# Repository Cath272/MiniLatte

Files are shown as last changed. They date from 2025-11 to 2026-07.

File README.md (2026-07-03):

# MiniLatte

## Introduction
MiniLatte is a Mini Pc made using the LattePanda Mu compute module

## General description
The device is a x86 desktop comuter with lots of IO ports like USB, PCIe, Ethernet and more. 

## Problems
Esp32 and GL3224 do not enumerate sometimes
The headphone jack is not correctly wired and i did not figure out how to fix it yet

### Block diagram
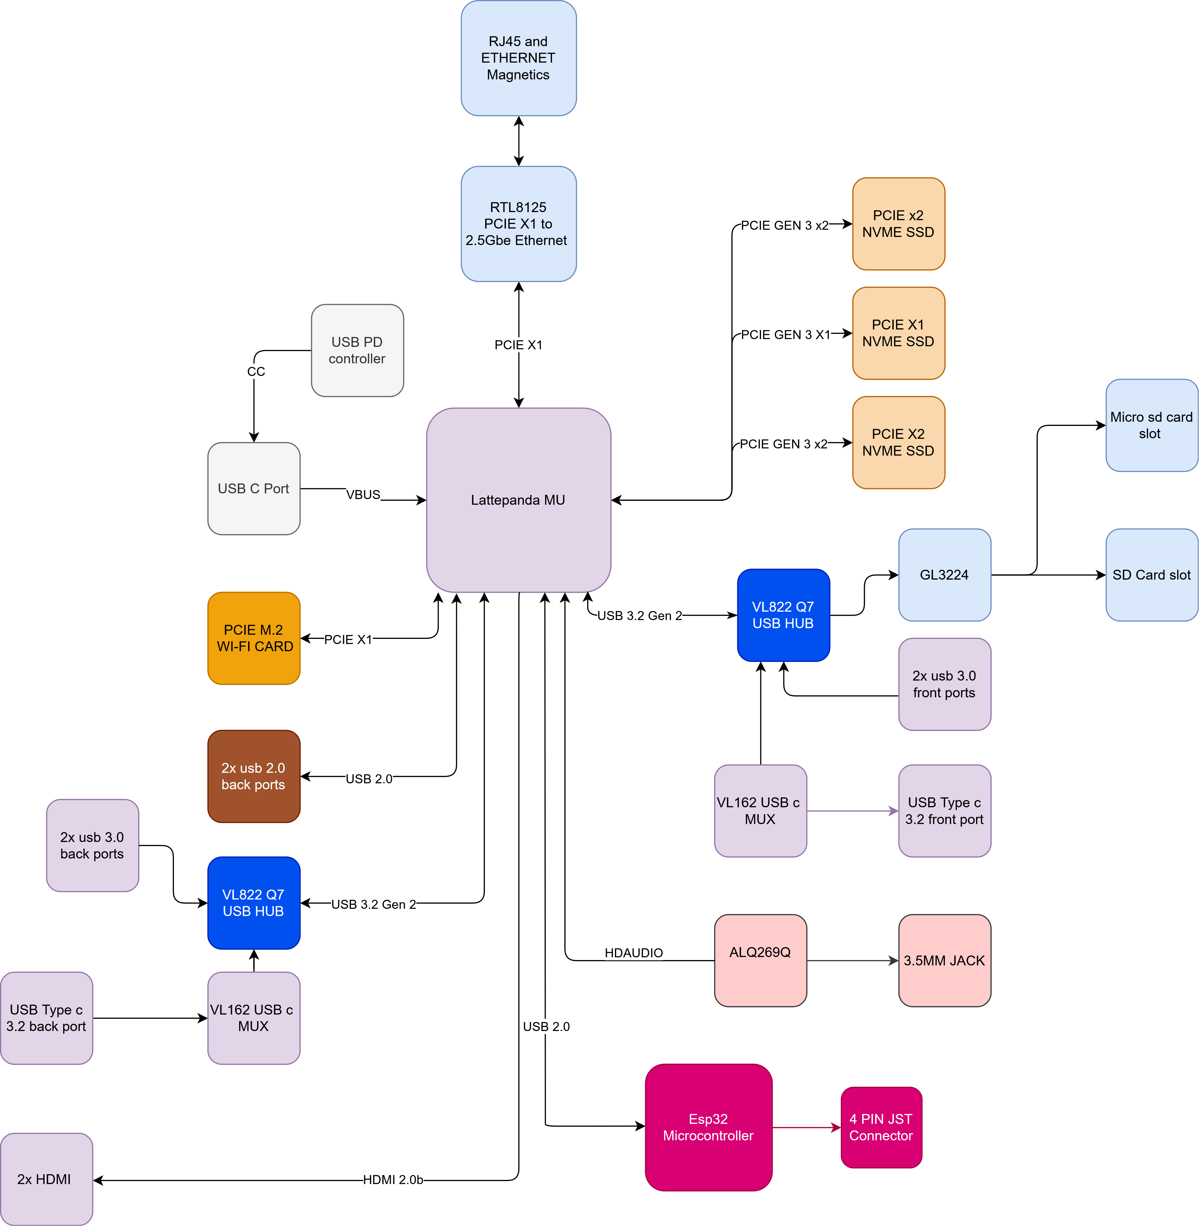
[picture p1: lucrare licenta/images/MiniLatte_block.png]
block diagram


## Hardware Design
### LattePanda Mu 
The LattePanda Mu is a compute module with rich IO with up to 9 PCIe slots, lots of usb, gpio and much more.
The module is Avaliable with 8 or 16gb of LPDDR5 ram, and an Intel N100 or Intel N305 CPU, the module uses a SODIMM DDR4 slot to connect to the carrier pcb

## ICs 
The board uses a lot of ics, so to avoid a long section about ics you can find the complete list of ICs in an the BOM generator in KiCad
All parts that are not generic (Like caps and resistors) are directly imported from LCSC so they also have an LCSC id 
Please read the warning on the IT8851-128 if you want to build the board.

Some of the chips are not available on components sourcing sites like DigiKey or LCSC but can be easliy found of Aliexpress.
Some notable Ics used by the board:

### VL822-Q7
USB 3.2 Gen 2 USB Hub 10Gbps with 4 downstream ports, used to increase the number of usb from 2 to 8

### GL3224ONY
USB 3.2 Gen 1 to dual Sd card controller, used to have 2 sd cards slots on the pcb

### IT8851FN-128
Usb Type C DP alt mode Controller, used for having a usb C port with Displayport output, the chip is a bit hard to get but you can find it on Aliexpress if you ask some BOM sellers. The chip also needs to be flashed so ask the Lattepanda team for the flashing firmware.
The chip variant needs to be "IT8851-128" EXACTLY, other variants do not work.  

### TPS51275

Main Power Ic, used for DC-DC from 20v to 3.3v and 5v

### VL162
USB Type-C 2:4 differential channels mux switch and integrated CC logic function for USB 3.1 type-C application. Needed for the type C ports to work both ways.

### RTL8125BG
PCIe to 2.5Gbps Ethernet controller

## Schematic
[Schematic](PCB/MiniLatte.pdf)

## PCB

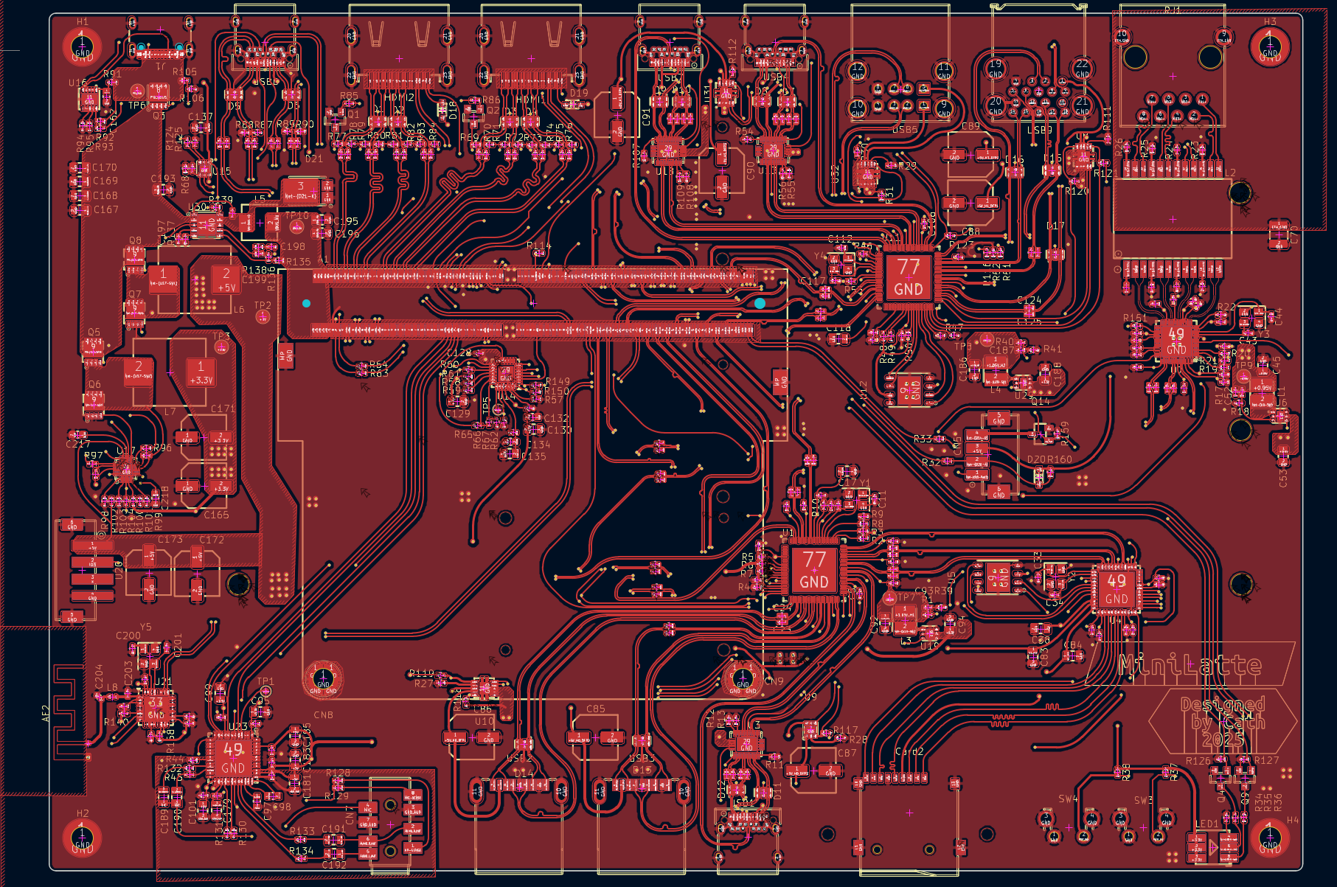
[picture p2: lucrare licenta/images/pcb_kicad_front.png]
kicad_front

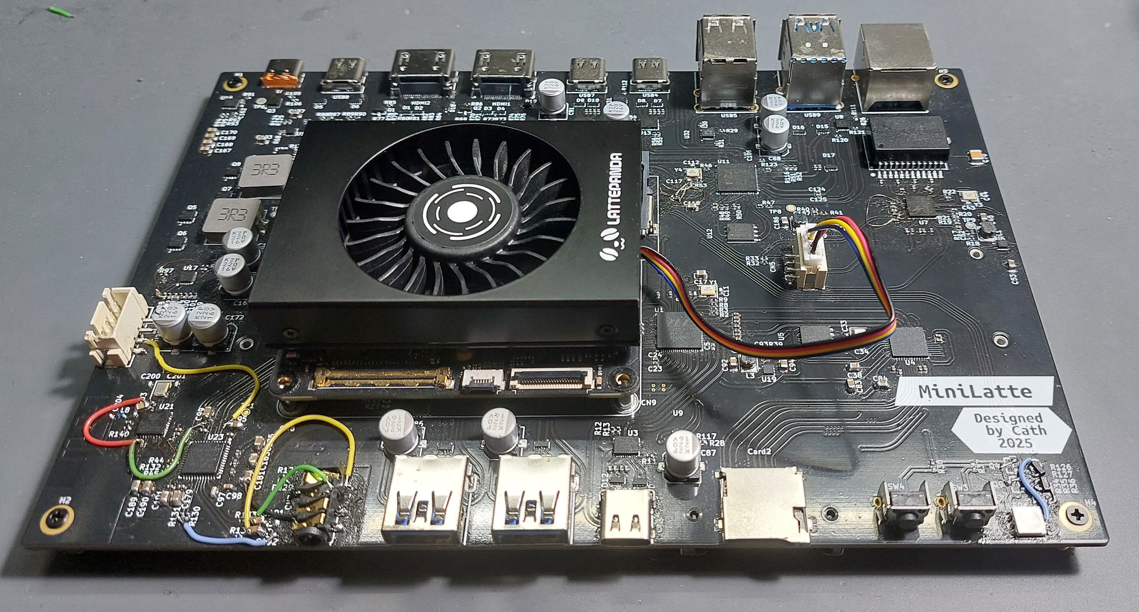
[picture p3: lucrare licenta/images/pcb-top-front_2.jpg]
pcb_front

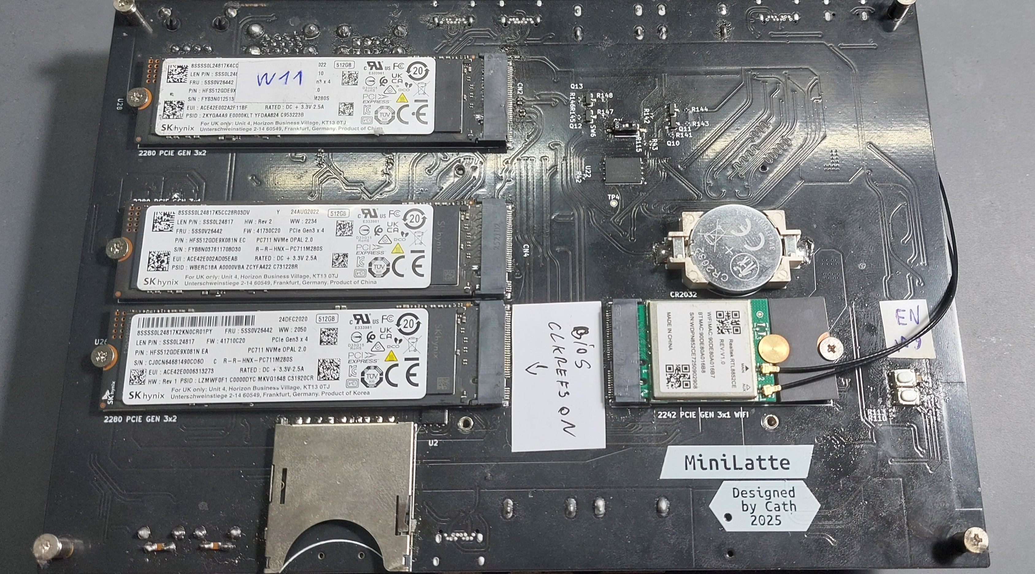
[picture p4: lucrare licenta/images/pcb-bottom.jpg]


## LED Array

The board connects to a secoundary board that an WS2812C LED Array made out of 220 leds (5x44). The Controller for the LEDs is on the main pcb and it is a ESP32 C3

## Case and 3d design

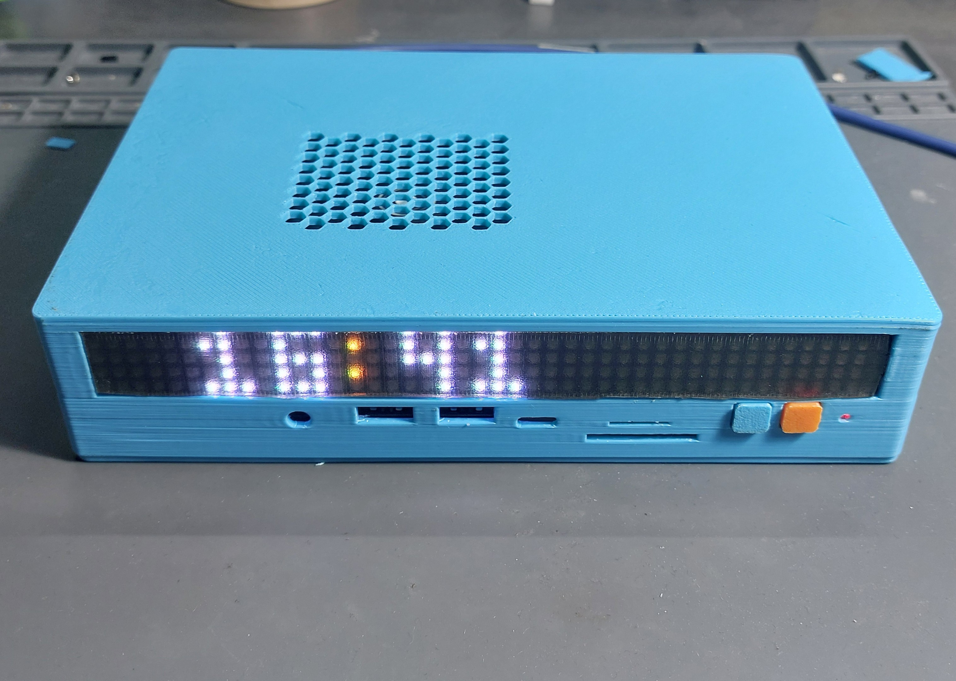
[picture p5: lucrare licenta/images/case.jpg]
case

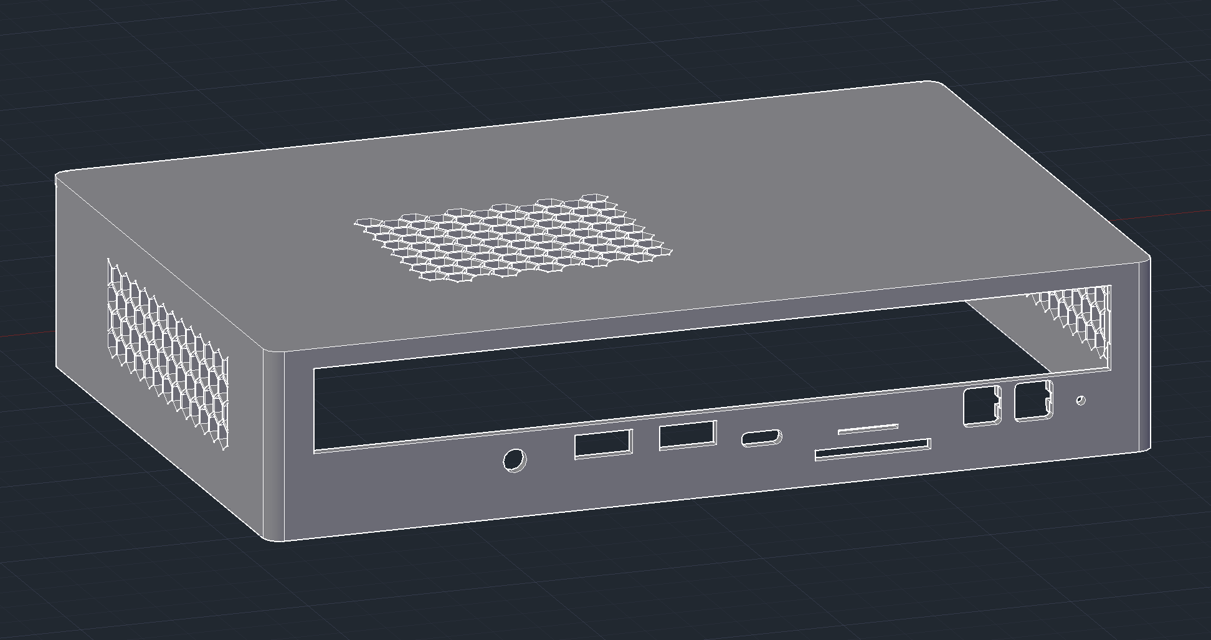
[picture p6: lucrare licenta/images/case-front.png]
case_front

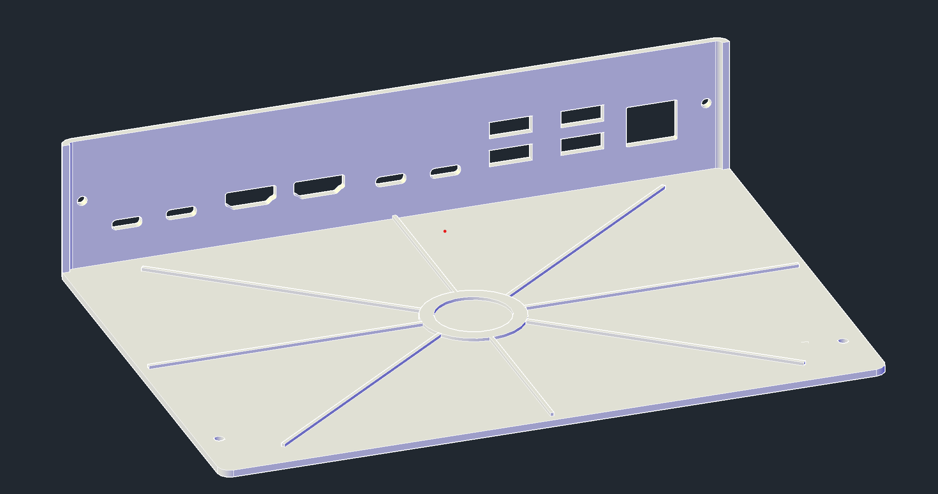
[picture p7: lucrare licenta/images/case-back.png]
case_back


The case was make using AutoCad and exported to stl
The stl files can be found in the 3D Models folder.
The case is made of 2 parts and there is a diffusion layer for the LED PCB

## Bachlors Degree
This project was made as a project for my bachlor's degree, you can find the thesis and a shorts powerpoint in the "lucrare licenta" folder but it is in romanian. It provides some details of the building process of this pcb. You can also find some extra pics in the same folder.

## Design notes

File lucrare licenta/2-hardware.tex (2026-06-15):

\chapter{Proiectarea sistemului hardware}
\label{ch:Proiectarea sistemului hardware}

\section{LattePanda Mu}

LattePanda Mu (vezi Figura \ref{fig:LattePanda-Mu}) este un modul de calcul performant, cu dimensiuni comparabile unui card bancar, proiectat de compania DFRobot. Acesta este conceput pentru integrare în produse hardware personalizate, fiind potrivit atât pentru proiecte de tip hobby, cât și pentru aplicații industriale.

Seria actuală cuprinde modele cu diferite configurații de procesoare și memorie, acestea menținând intercompatibilitatea la nivel de pinout. Modulul este proiectat pentru a fi inserat într-o \textit{carrier board} (placă de bază) folosind un slot standard SO-DIMM \ac{DDR}4. Această alegere constructivă este justificată de densitatea mare de pini, necesară pentru a expune numeroasele interfețe de comunicare către placa purtătoare.

Flexibilitatea platformei este sporită de posibilitatea modificării BIOS-ului, permițând utilizatorului să configureze alocarea liniilor de date pentru a prioritiza, după caz, numărul de sloturi \ac{PCIe} sau porturile USB disponibile. Specificațiile tehnice ale unității utilizate în prezenta lucrare sunt următoarele:

\begin{figure}
  \centering
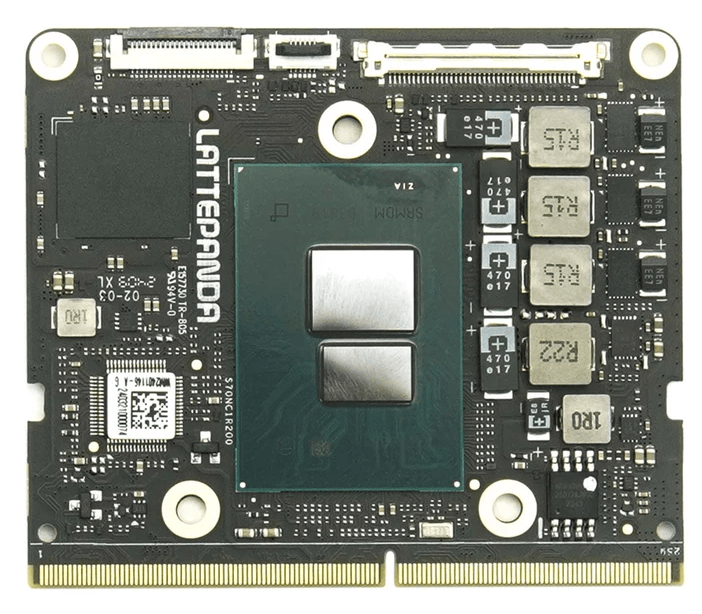
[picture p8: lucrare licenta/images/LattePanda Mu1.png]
  
  \caption[Modulul LattePanda Mu]{Modulul LattePanda Mu \cite{lattepanda_docs}.}
  \label{fig:LattePanda-Mu}
\end{figure}

În ceea ce privește conectivitatea, configurația aleasă pentru acest sistem include:
\begin{itemize}
  \item 2 porturi USB 3.2 Gen 2 (10 Gbps);
  \item 7 linii \ac{PCIe} Gen 3.
\end{itemize}

\section{Conexiuni - Diagramă Bloc}

În această secțiune sunt descrise conexiunile și este explicată diagrama bloc din Figura ~\ref{fig:diagrama-bloc}.
Sistemul utilizează standardul \textit{USB \ac{PD}}  pentru alimentare, alegere motivată datorită costului redus și a disponibilității ridicate pe piață a surselor compatibile.
Fiind un standard universal și nu unul proprietar, acesta oferă flexibilitate maximă în alegerea alimentatorului și facilitează înlocuirea rapidă a acestuia în caz de necesitate.
Toate conexiunile sunt realizate intern, la nivelul plăcii de bază, pentru a reduce latențele și a crește fiabilitatea.

\begin{figure}
  \makebox[\textwidth][c]{}
  \caption{Diagramă bloc a sistemului MiniLatte. Prezintă interconexiunile între modulul LattePanda Mu și componentele periferice.}
  \label{fig:diagrama-bloc}
\end{figure}

Pentru extinderea capacităților de conectare a perifericelor, au fost integrate două hub-uri USB care pun la dispoziție 4 porturi USB 3.2 Gen 2 fiecare, acestea sunt atât USB type A cât și USB type C. Suplimentar, la unul dintre hub-urile USB este conectat un cititor de carduri dual \ac{SD}, utilizând lățimea de bandă oferită de interfața USB 3.2 Gen 2. Amplasarea acestora fiind observată în \ref{fig:front-ports} și \ref{fig:back-ports}.

Semnalul video este distribuit prin trei porturi digitale: două \ac{HDMI} 2.0 acestea suportând rezoluții de până la 4K 60Hz, și un DisplayPort 1.4 (via USB-C) care suportă rezoluții până de la 4K 120Hz.
Pe partea de procesare audio, sistemul utilizează un cip \textit{ALC269Q} ce comunică prin protocolul \textit{\ac{HDAudio}}, acesta fiind conectat la un port de tip TRRS, permițând semnale audio stereo și microfon.

În ceea ce privește conectivitatea la rețea, sistemul oferă două posibilități distincte, ambele bazate pe magistrala \ac{PCIe} Gen 3:
\begin{enumerate}
  \item \textbf{Wireless:} prin intermediul unui modul Wi-Fi instalat în slotul dedicat de pe placa de bază;
  \item \textbf{Ethernet:} utilizând controlerul \textit{Realtek RTL8125}, care suportă viteze de transfer de până la 2.5 Gbps via \ac{PCIe} Gen 3.
\end{enumerate}

Capacitatea de stocare poate fi extinsă considerabil prin cele trei sloturi destinate unităților \ac{SSD} M.2 \ac{NVMe} poziționate pe partea inferioară a plăcii (vezi Figura \ref{fig:bottom-ports}). .

\begin{figure}
  \centering
  \begin{subfigure}[b]{1\linewidth}
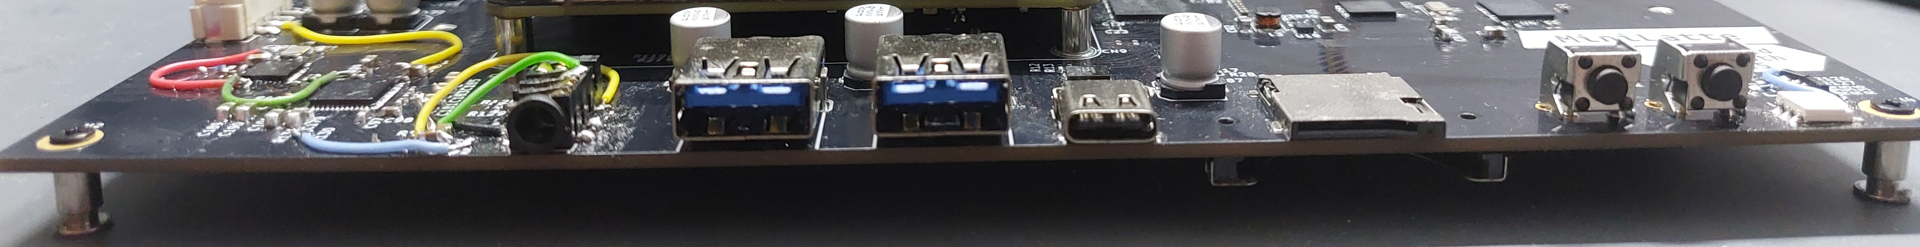
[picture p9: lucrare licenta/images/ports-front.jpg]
    
    \caption{Port-urile din partea din față a PCB-ului.}
    \label{fig:front-ports}
  \end{subfigure}
  \begin{subfigure}[b]{1\linewidth}
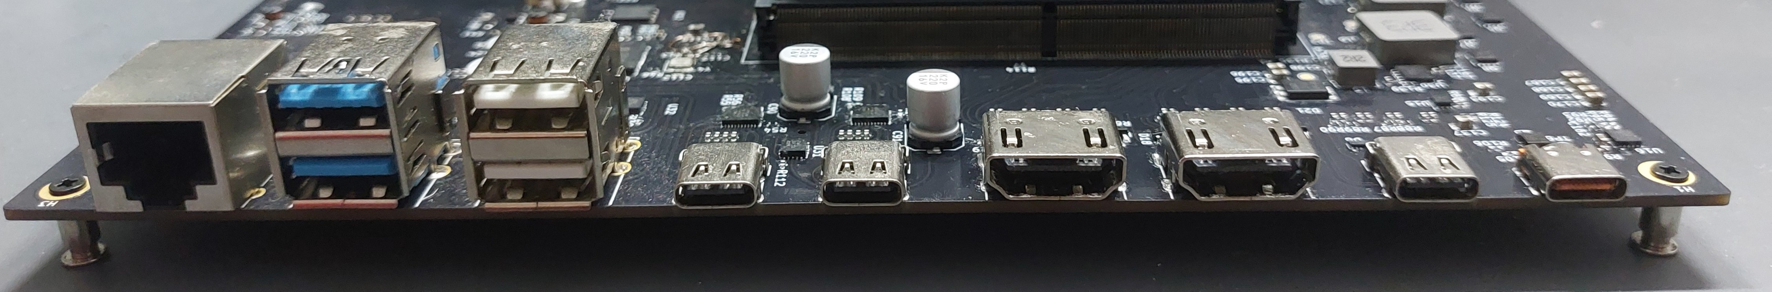
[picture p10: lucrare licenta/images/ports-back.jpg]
    
    \caption{Port-urile din partea din spate a PCB-ului.}
    \label{fig:back-ports}
  \end{subfigure}
  \begin{subfigure}[b]{0.7\linewidth}
    
    \caption{Port-urile de pe spatele PCB-ului.}
    \label{fig:bottom-ports}
  \end{subfigure}

  \caption{Port-urile PCB-ului.}
  \label{fig:ports}
\end{figure}

\section{Arhitectura hardware și selecția componentelor}

Placa de bază pentru acest modul a fost proiectată folosind KiCad 9, folosind ca bază documentația dată de creatorii modulului, dar și țindând cont de regulile de proiectare atât pe partea de diagrame electrice dar și pe partea de design de \ac{PCB}.
Pornind de la diagrama bloc,procesul de selecție a componentelor s-a bazat pe mai multe criterii, precum costul, disponibilitatea pe piață, familiaritatea cu producătorul și calitatea documentației tehnice.
\begin{itemize}
  \item \textbf{ITE IT8851FN-128:} O excepție notabilă în procesul de achiziție o reprezintă acest cip de management. Deși este un circuit integrat dificil de procurat prin canalele standard de distribuție, utilizarea sa a fost obligatorie din cauza compatibilității exclusive cu firmware-ul proprietar furnizat de LattePanda, neexistând o alternativă viabilă pe piață la momentul proiectării.
  \item \textbf{VIA Labs VL822-Q7 \cite{VL822-Q7}:} Reprezintă hub-ul USB 3.2 Gen 2 principal al sistemului. A fost selectat datorită capacității de a gestiona 4 porturi din \textit{downstream} cu o lățime de bandă de până la \mbox{10\text{\,}Gbps} per port, oferind un raport excelent între performanța de transmisie și costul de implementare.
  \item \textbf{VIA Labs VL162 \cite{VL162}:} Acest circuit integrat acționează ca un switch de date/multiplexor de mare viteză pe 4 canale, special conceput pentru configurarea porturilor USB Type-C. Rolul său critic este de a detecta orientarea fizică a conectorului USB-C inserat (prin monitorizarea pinilor CC1/CC2) și de a ruta corect liniile diferențiale de date (\textit{TX/RX}) către hub-ul principal, asigurând conexiunea indiferent de poziția în care utilizatorul conectează cablul.
  \item \textbf{Realtek RTL8125}, care oferă suport pentru viteze de până la 2.5 Gbps, menținând totodată un cost competitiv.
  \item Circuite Integrate de la Texas Instruments (TPS51275 \cite{TPS51275}, TPS54561 \cite{TPS54561}, TPS62590 \cite{TPS62590}), iar pentru protecția la supracurent au fost alese cipurile TPS2553 și TPS2561. Alegerea acestor componente s-a bazat pe eficiența ridicată, documentația detaliată și disponibilitatea acestora.
  \item \textbf{Memoriile NOR W25Q128JV} (folosit pentru stocarea BIOS-ului) respectiv W25Q32JV (folosite pentru stocarea firmware-ului pentru VL822 și GL3224), acesta au fost alese datorită costului redus.
  \item \textbf{Genesis Logic GL3224-ONY:} - controller pentru carduri SD și MicroSD, acesta a fost ales din cauza costului redus și a pentru suportul interfețelor de tip UHS-I care permit viteze până la 104MB/s.
  \item \textbf{Hynetek HUSB238} -  USB Type-C PD controller, acesta a fost ales din cauza costului redus și a modului foarte ușor de a programa tensiunile pe care le cere încărcătorului folosind doar doi rezistori, unul pentru curentul maxim și unul pentru tensiune.
  \item \textbf{Espressif Systems ESP32-C3FN4:} - Microcontroller cu WiFi și 4Mb de memorie internă, a fost ales datorită prețului, memoriei interne, circuitului intern USB-UART dar și a performanței. Microcontrollerul a fost ales în locul locul pinilor GPIO nativi ai modulului LattePanda Mu din cauza faptului că aceștia nu erau funcționali la momentul proiectării sistemului, dar și pentru a degreva procesorul de sarcina de a controla LED-urile.
\end{itemize}

\section{Diagrama electrică}

Diagrama electrică reprezintă etapa inițială esențială în procesul de proiectare. în cazul sistemului MiniLatte, aceasta este structurată pe 19 pagini și descrie în detaliu toate conexiunile dintre modulul LattePanda Mu, circuite integrate și conectori utilizați. Schema a fost organizată pe blocuri funcționale, precum „USB3”, „HDMI” și „PCIe\_SSD”, pentru a facilita înțelegerea și verificarea conexiunilor.

Pentru realizarea acesteia au fost utilizate în principal fișele de date ale componentelor, specificațiile protocoalelor de comunicație, precum și documentația oficială DFRobot  \cite{lattepanda_docs} \cite{lattepanda_github}. Aceasta din urmă a oferit informații esențiale despre modul de interconectare al modulului LattePanda Mu, servind drept referință pentru integrarea componentelor externe.

\section{Rutare trasee și Integritatea Semnalului}
Etapa de rutare a traseelor pe \ac{PCB} a avut un rol critic în asigurarea funcționării corecte a sistemului, în special datorită prezenței interfețelor de mare viteză, precum USB 3.2 Gen 2, \ac{PCIe} Gen 3 și HDMI 2.0. Pentru a preveni degradarea semnalului din cauza reflexiilor și a fenomenului de \textit{crosstalk} (diafonie), placa a fost realizată pe 4 straturi, asigurând o structură de tip \textit{stripline} (traseu rutat pe stratul exterior) și \textit{microstrip} (traseu rutat pe stratul interior) cu impedanță controlată.

%În această configurație, traseele de semnal sunt rutate pe cele două straturi exterioare, în timp ce cele două straturi interioare sunt utilizate ca planuri continue de masă. Această arhitectură permite asigurarea unui traseu de retur (return path) continuu și de impedanță redusă pentru curentul de semnal, conform bunelor practici de proiectare recomandate în ghidurile de layout pentru circuite de mare viteză \cite{Layout_Guidelines}. Menținerea unui plan de referință neîntrerupt contribuie la reducerea interferențelor electromagnetice și la îmbunătățirea integrității semnalului.

Impedanța caracteristică a liniilor de transmisie depinde direct de geometria traseelor și de proprietățile dielectrice ale materialului suport (FR4, cu o permisivitate dielectrică relativă $\varepsilon_r \approx 4.2$). Pentru protocoalele utilizate, s-au calculat și implementat următoarele valori țintă ale impedanței diferențiale ($Z_{diff}$):
\begin{itemize}
  \item \textbf{Interfețele USB 3.2 și PCIe Gen 3:} $Z_{diff} = 90\,\Omega \pm 10\%$
  \item \textbf{Interfața HDMI 2.0:} $Z_{diff} = 100\,\Omega \pm 10\%$
  \item \textbf{Liniilor de semnal de tip \textit{single-ended} (asimetrice):} $Z_{0} = 50\,\Omega \pm 10\%$
\end{itemize}

Determinarea lățimii traseelor ($w$) și a distanței de separare în cadrul perechii ($s$) s-a realizat utilizând calculatorul de impedanță integrat în suita KiCad 9, corelat cu structura geometrică a substratului (vezi Figura \ref{fig:stackup}).

Un aspect fundamental în layout-ul circuitelor de înaltă frecvență îl reprezintă asigurarea unui \textit{return path} (traseu de retur) continuu și de impedanță minimă pentru curentul de înaltă frecvență. Curentul de retur tinde să urmeze calea de sub traseul de semnal, în cel mai apropiat plan de referință solid (GND). În cadrul proiectului, straturile interioare (In1.GND și In2.GND) acționează ca planuri de masă continue.

\begin{figure}
  \centering
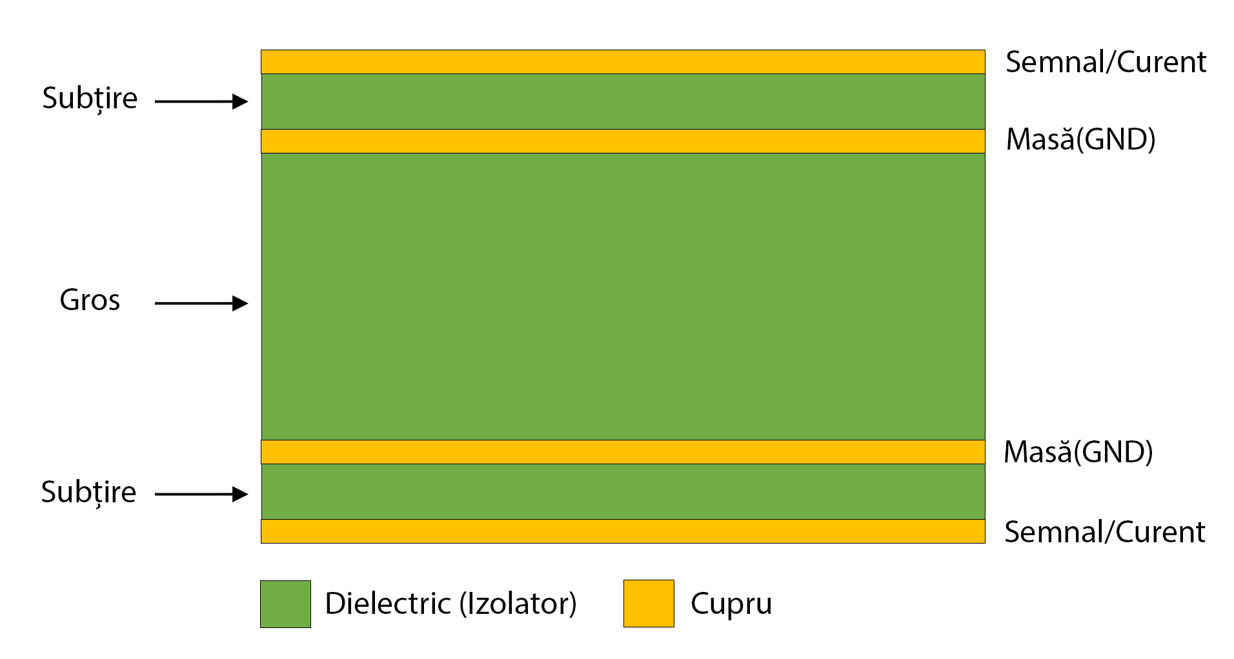
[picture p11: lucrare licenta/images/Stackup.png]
  
  \caption{Poziționarea straturilor PCBului.}
  \label{fig:stackup}
\end{figure}

\subsection{Poziționarea componentelor}
Prima etapă a rutării este plasarea preliminară a componentelor. În acest caz, s-a pornit de la poziționarea slotului pentru modulul LattePanda Mu și a conectorilor externi, în funcție de distribuția pinilor modulului (vezi Figura \ref{fig:pcb_zones}). Având în vedere că primii pini sunt dedicați alimentării, s-a ales poziționarea circuitelor de alimentare în proximitatea conectorului de intrare, definind astfel zona stângă a plăcii ca zonă principală de alimentare. Următoarele semnale sunt cele video, începând cu portul USB-C (care transmite semnal DisplayPort), urmat de cele două porturi HDMI. Ulterior, au fost poziționate porturile USB, conectate la pinii din extremitatea dreaptă a modulului, necesitând spațiu suplimentar pentru integrarea hub-ului USB. În final, a fost amplasat portul Ethernet. Dimensiunile plăcii au fost determinate de amplasarea conectorilor: lățimea este de 190 mm, stabilită de porturile din partea posterioară, iar lungimea de 130 mm, determinată de porturile din partea frontală.

\begin{figure}
  \centering
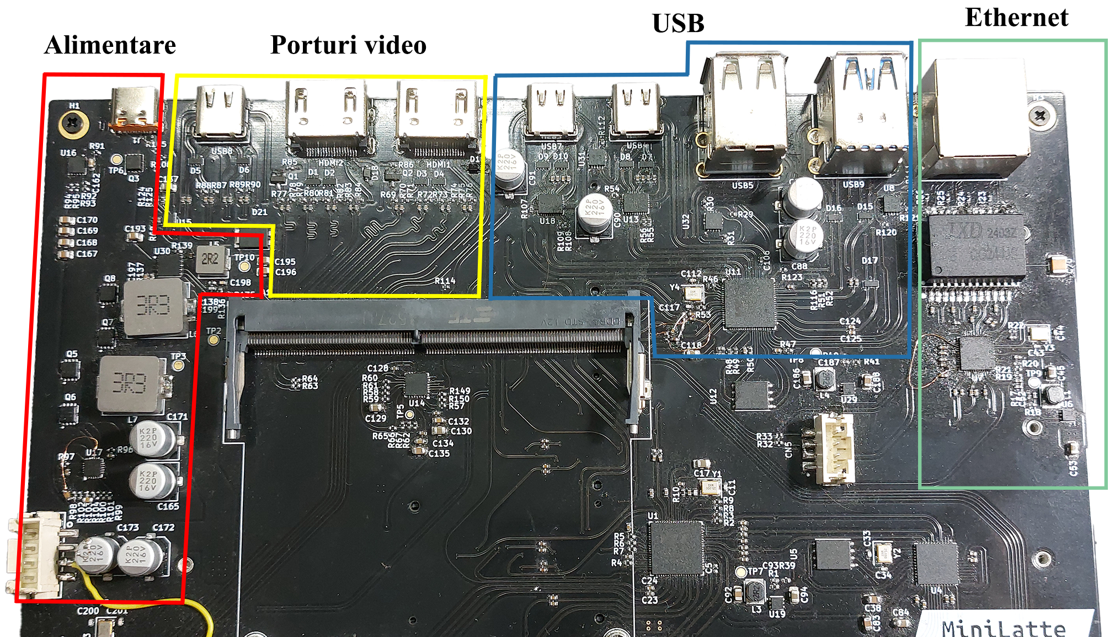
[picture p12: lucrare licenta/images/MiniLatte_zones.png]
  
  \caption{Poziționarea componentelor pe placă.}
  \label{fig:pcb_zones}
\end{figure}

\subsection{Perechi diferențiale}
Transmisia diferențiale reprezintă principala metodă de transmitere a datelor la viteze ridicate, fiind folosite în majoritatea protocoalelor de comunicare moderne cum ar fi HDMI, USB și \ac{PCIe}
În proiectarea \ac{PCB}-urilor, perechile diferențiale reprezintă două trasee paralele, cu lungimi egale și cu o distanță controlată între ele.
Diferența de lungime dintre cele două trasee, definită ca \textit{Intra Pair Skew} (decalaj în cadrul aceleiași perechi) vezi Figura~\ref{fig:Intra-Pair Skew}, trebuie să se încadreze într-o toleranță strictă, de exemplu, 0,125 mm pentru USB 3.0 \cite{Layout_Guidelines}.
În cazul protocoalelor care utilizează mai multe perechi diferențiale în paralel (precum HDMI sau DisplayPort), este necesară și gestionarea fenomenului de \textit{Inter-Pair Skew} (decalaj între perechi diferite), fiind impusă o toleranță strictă de maximum \mbox{1\text{\,}mm} pentru a asigura sincronizarea corectă a fluxurilor de date la frecvențe ridicate. Corecțiile geometrice au fost implementate prin adăugarea de serpentine pentru compensarea lungimii pe stratul exterior (vezi Figura \ref{fig:Inter-Pair Skew}).

\begin{figure}
  \centering
  \makebox[\textwidth][c]{
    \begin{subfigure}[b]{0.31\linewidth}
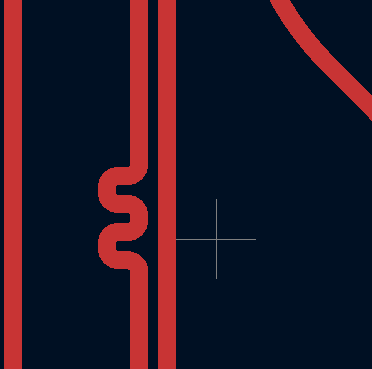
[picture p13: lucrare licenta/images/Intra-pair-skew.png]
      
      \caption{Corecție a Intra Pair Skew pe o pereche diferețială.}
      \label{fig:Intra-Pair Skew}
    \end{subfigure}
    \begin{subfigure}[b]{0.66\linewidth}
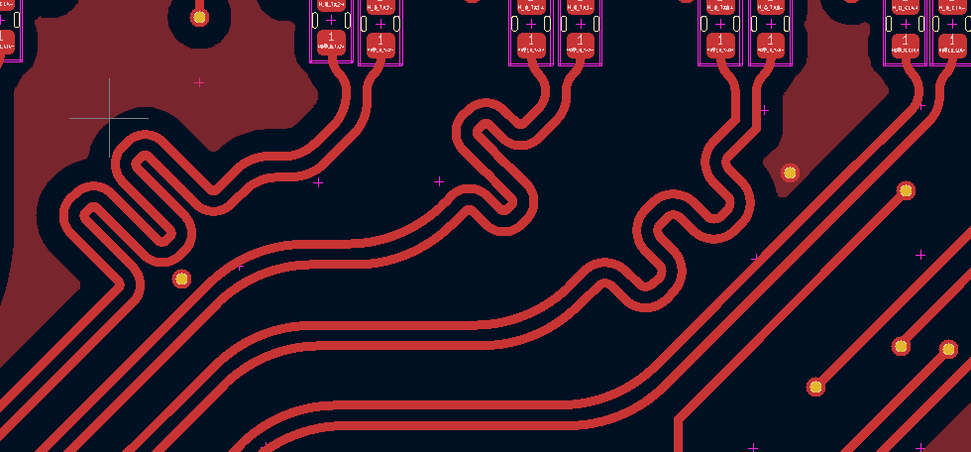
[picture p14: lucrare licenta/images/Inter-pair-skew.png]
      
      \caption{Corecție a Inter Pair Skew pe cele 4 perechi diferețiale ale unui port HDMI.}
      \label{fig:Inter-Pair Skew}
    \end{subfigure}
  }

  \caption{Corecții ale Intra si Inter Pair Skew.}
  \label{fig:Skew}

\end{figure}

\section{Proiectarea rețelei de alimentare și a protecțiilor}
Datorită numărului mare de interfețe disponibile, un lucru important in acest design a fost proiectarea in jurul consumului de curent, atât a modulului LattePanda Mu dar și componentelor de pe placa și a diverselor dispozitive conectate.

Modulul este alimentat printr-un port USB Type C utilizând protocolul USB \ac{PD} versiunea 3.0, controlat de un cip HUSB238, responsabil de negocierea tensiunii cu sursa de alimentare, solicitând un profil de \mbox{20\text{\,}V} și \mbox{3,25\text{\,}A} (\mbox{65\text{\,}W}) \cite{usb_pd_spec}, valoare standard pentru acest protocol.

Tensiunea este coborâtă la \mbox{17,5\text{\,}V} pentru modulul LattePanda Mu folosind regulatorul TPS54561. Consumul modulului fiind de \mbox{10-15\text{\,}W} în modul standard și până la \mbox{15\text{\,}W} în modul Boost, de asemenea sunt generate tensiuni auxiliare de \mbox{3,3\text{\,}V} și \mbox{5\text{\,}V} folosind cipul TPS51275.

Puterea necesară la intrare ($P_{in}$) a fost dimensionată prin calcularea consumului total al sistemului (Tabelul \ref{Tab:consumption_pwr}). Luând în considerare o eficiență conservatoare de $\eta$ = 90\% a regulatorelor DC-DC, puterea totală necesară la intrare a fost estimată matematic prin ecuația:
\begin{equation}
    P_{\text{in}} = \frac{P_{\text{total\_consumatori}}}{\eta} = \frac{48,6\,\text{W}}{0,90} \approx 54\,\text{W}
\end{equation}

Profilul de $65\,\text{W}$ a fost ales deorece este primul profil disponibil deasupra puterii calculate de $54\,\text{W}$, acest lucru oferind o marjă de siguranță critică pentru a absorbi eventualele vârfuri tranzitorii de curent.

\begin{table}[h]
  \centering
  \rowcolors{2}{white}{lightgray!20}
  \begin{tabularx}{\textwidth}{X c c c}
    \toprule
    \rowcolor{gray!30}
    \textbf{Consumator}   & \textbf{Nr. Unități} & \textbf{Consum Maxim / Unitate} & \textbf{Consum Total} \\ \midrule
    LattePanda Mu         & 1                    & 15\text{\,}W                    & 15\text{\,}W          \\
    USB 2.0 Periferice    & 2                    & 0,5\text{\,}W                   & 1\text{\,}W           \\
    USB 3.2 Periferice    & 6                    & 0,9\text{\,}W                   & 5,4\text{\,}W         \\
    Realtek RTL8125       & 1                    & 1\text{\,}W                     & 1\text{\,}W           \\
    Genesis Logic GL3224  & 1                    & 0,5\text{\,}W                   & 0,5\text{\,}W         \\
    ESP32-C3              & 1                    & 1,1\text{\,}W                   & 1,1\text{\,}W         \\
    LED-uri WS2812C       & 220                  & 0,068\text{\,}W                 & 15\text{\,}W          \\
    SSD-uri NVMe          & 3                    & 1,83\text{\,}W                  & 5,5\text{\,}W         \\
    Modul Wi-Fi           & 1                    & 2,5\text{\,}W                   & 2,5\text{\,}W         \\
    VIA Labs VL822-Q7     & 2                    & 0,8\text{\,}W                   & 1,6\text{\,}W         \\ \midrule
    \textbf{Consum total} & \multicolumn{2}{c}{} & \textbf{48,6\text{\,}W}                                 \\ \bottomrule
  \end{tabularx}
  \caption{Bugetul estimat pentru consumul de putere al sistemului.}
  \label{Tab:consumption_pwr}
\end{table}

\begin{figure}
  \centering
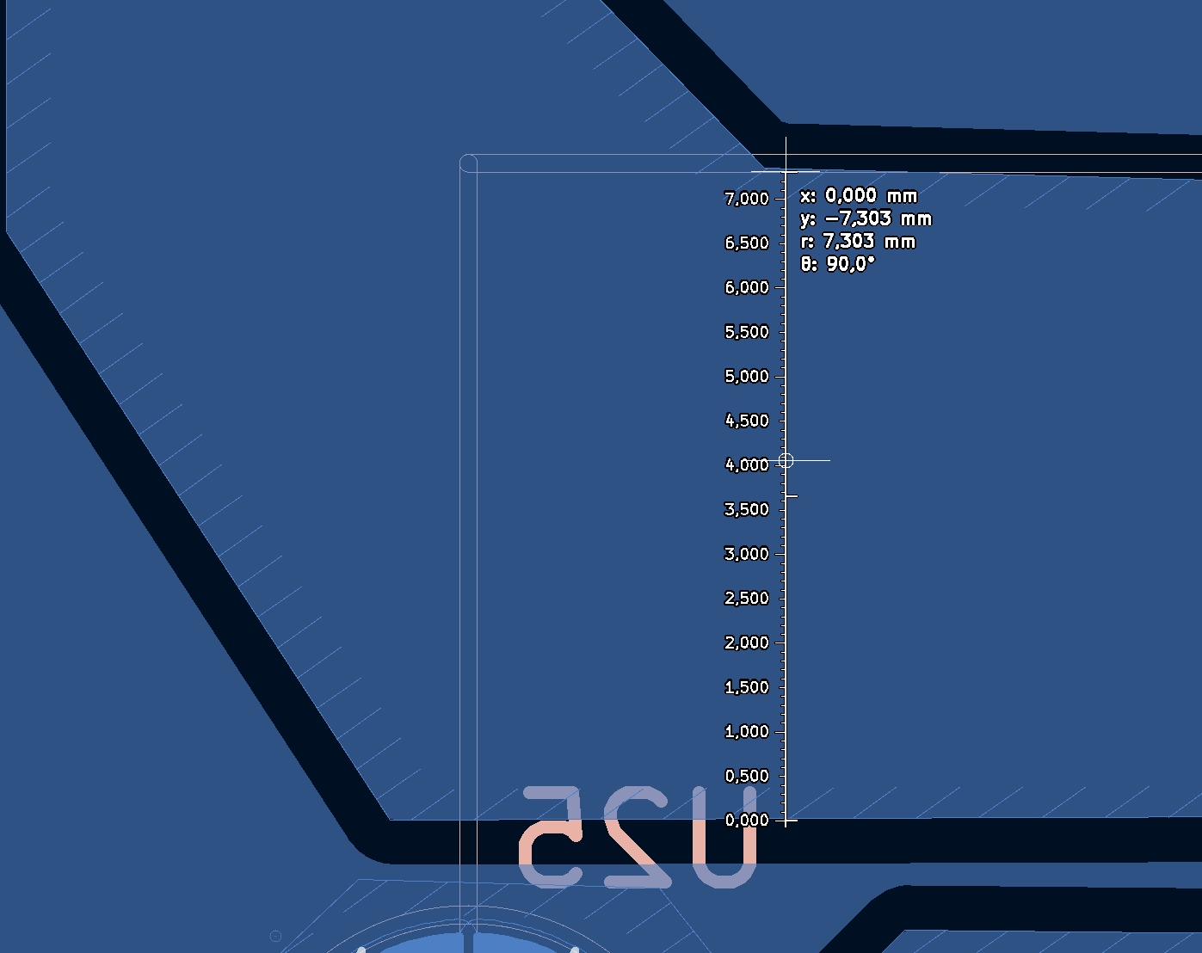
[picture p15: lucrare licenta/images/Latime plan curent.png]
  
  \caption{Plan de curent cu o lățime de 7,3mm.}
  \label{fig:power-plane}
\end{figure}

Traseele de alimentare au fost dimensionate corespunzător curenților implicați. Conform standardului IPC-2152 \cite{IPC-2152}, lățimea planului principal de alimentare de după regulatorul de $3,3\,\text{V}$ a fost dimensionată la $7.3\,\text{mm}$ (vezi Figura \ref{fig:power-plane}), urmând ca acestea să se reducă progresiv după alimentarea consumatorilor principali. Acest calcul garantează că, la un curent maxim de $10\,\text{A}$, creșterea de temperatură locală a cuprului ($\Delta T$) nu depășește $10^\circ\text{C}$ față de mediul ambiant.

Pe liniile de $3,3\,\text{V}$ și $5\,\text{V}$, unde curentul este distribuit către mai multe periferice expuse extern (porturile USB), s-a implementat o arhitectură de protecție activă. S-au integrat circuitele TPS2553 și TPS2561 de la Texas Instruments, care acționează ca limitatoare de curent reglabile și comutatoare inteligente. Acestea monitorizează în timp real curentul absorbit de porturile USB, limitându-l la $0,5\,\text{A}$ pentru USB 2.0 și respectiv $0,9\,\text{A}$ pentru USB 3.2. În cazul unui scurtcircuit extern, cipul decuplează linia defectă într-un timp de răspuns de ordinul microsecundelor, protejând sursa principală și prevenind resetarea accidentală a întregului sistem Mini PC.

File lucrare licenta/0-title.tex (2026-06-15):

\begin{titlepage}

% Redu marginile
\newgeometry{left=2cm,right=2cm,bottom=1cm}

\begin{figure}[!htb]
    \centering
    \begin{minipage}{0.2\textwidth}
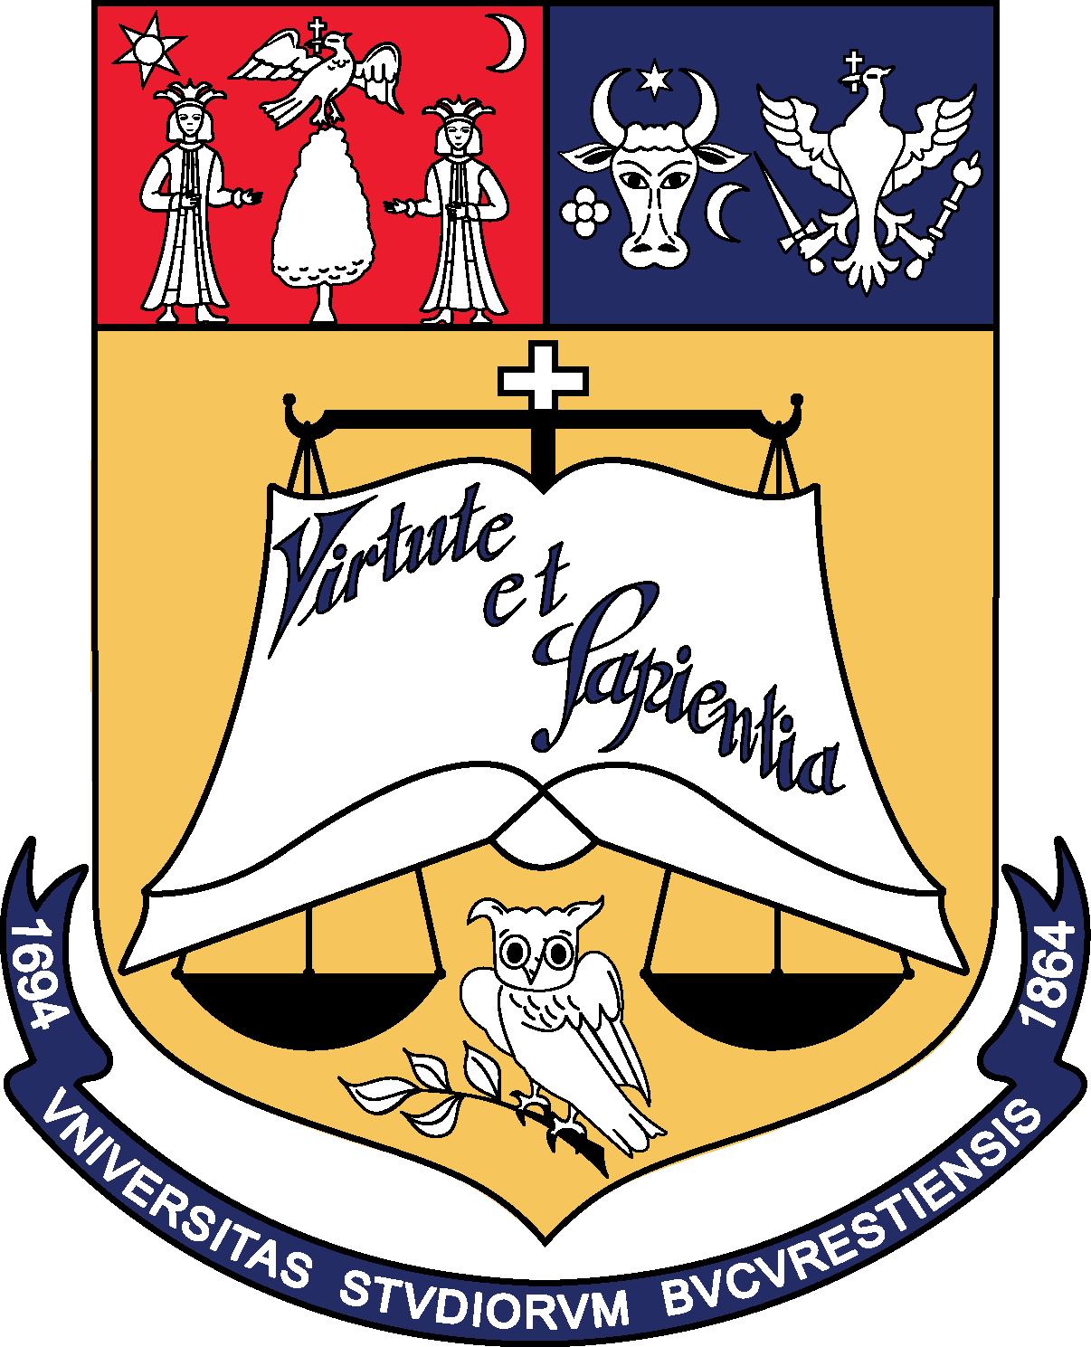
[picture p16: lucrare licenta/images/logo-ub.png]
        
    \end{minipage}
    \begin{minipage}{0.5\textwidth}
        \large
        \vspace{0.2cm}
        \begin{center}
            \textbf{UNIVERSITATEA DIN BUCUREȘTI}
        \end{center}
        \vspace{0.3cm}
        \begin{center}
            \textbf{
                FACULTATEA DE \\
                MATEMATICĂ ȘI INFORMATICĂ
            }
        \end{center}
    \end{minipage}
    \begin{minipage}{0.2\textwidth}
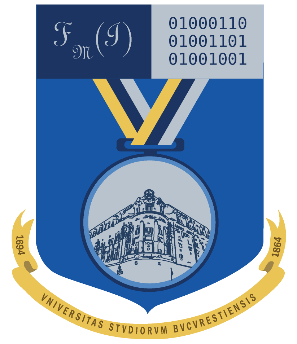
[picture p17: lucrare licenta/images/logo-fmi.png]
        
    \end{minipage}
\end{figure}

\begin{center}
\textbf{SPECIALIZAREA TEHNOLOGIA INFORMAȚIEI}
\end{center}

\vspace{1cm}

\begin{center}
\Large \textbf{Proiect de Diplomă}
\end{center}

\begin{center}
\huge \textbf{\MakeUppercase{\@title}}
\end{center}

\vspace{3cm}

\begin{center}
\large \textbf{Absolvent \\ \@author}
\end{center}

\vspace{0.25cm}

\begin{center}
\large \textbf{Coordonator științific \\ Conf. Dr. Alexe Bogdan \\ Drd. Dumitriu Andrei}
\end{center}

\vspace{2cm}

\begin{center}
\Large \textbf{București, iunie 2026}
\end{center}
\end{titlepage}

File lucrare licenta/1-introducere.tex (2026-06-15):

\chapter{Introducere}
\label{ch:introducere}

În acest capitol se prezintă contextul proiectului, obiectivele urmărite și motivația alegerii platformei hardware. Lucrarea vizează dezvoltarea unui sistem compact și performant, capabil să ruleze aplicații complexe într-un format redus, utilizând arhitectura x86 modernă pentru a asigura compatibilitatea cu o gamă largă de soluții software.

Proiectul propune dezvoltarea unui sistem Mini PC bazat pe modulul LattePanda Mu (vezi Figura \ref{fig:forma-finala}), integrat pe o placă de bază, care include interfețe de mare viteza (USB 3.2, HDMI), stocare NVMe și conectivitate WiFi și Ethernet.

Proiectul prevede proiectarea unei plăci de bază (vezi Figura \ref{fig:pcb-front-kicad}) care se integreze modulul, să îl conecteze la interfețele exterioare, direct sau prin anumite cip-uri, și să gestioneze tensiunile și curenții necesari functionării în parametrii optimi.

Acest sistem se adresează atât pasionațiilor de electronica care pot dezvolta pe baza proiectului conceput dar și a tuturor persoanelor care iși doresc un sistem compact cu posibilitea de a schimba modulul cu unul mai performant pe viitor.

\section{Obiectivele proiectului și contribuția personală}

\begin{figure}
    \centering
    \makebox[\textwidth][c]{
        \begin{subfigure}[b]{0.5\linewidth}
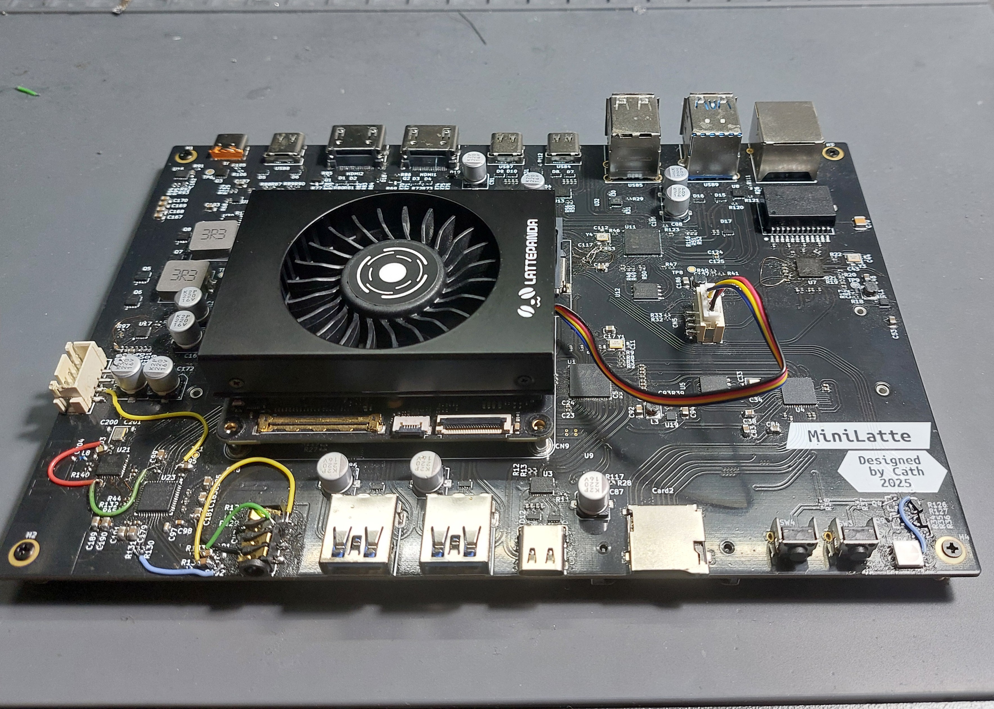
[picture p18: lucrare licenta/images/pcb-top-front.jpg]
            
            \caption{PCB-ul asamblat.}
            \label{fig:case_final}
        \end{subfigure}
        \begin{subfigure}[b]{0.5\linewidth}
            
            \caption{Sistemul asambalat în carcasă.}
            \label{fig:pcb_final}
        \end{subfigure}
    }

    \caption{Formă finală.}
    \label{fig:forma-finala}

\end{figure}

Contribuția originală a acestei lucrări constă în proiectarea integrală, realizarea fizică și validarea experimentală a unei plăci de bază complexe de la stadiul de schemă electrică de principiu până la prototipul funcțional. Obiectivele tehnice specifice îndeplinite pe parcursul proiectului au fost:

\begin{itemize}
    \item \textbf{Proiectarea schemei electrice:} Integrarea modulului x86 cu diverse circuite integrate auxiliare (hub-uri USB 3.2, controlere Ethernet 2.5 Gbps și circuite de management al curentului).
    \item \textbf{Dezvoltarea layout-ului PCB complex:} Rutarea unui circuit imprimat cu 4 straturi, cu respectarea constrângerilor stricte de integritate a semnalului (\textit{Signal Integrity}) și control al impedanței diferențiale pentru linii de mare viteză (USB 3.2 Gen 2, PCIe Gen 3 și HDMI 2.0).
    \item \textbf{Managementul alimentării și protecției:} Dimensionarea geometrică a planurilor de cupru pentru curenți mari (până la 10 A) conform standardului IPC-2152 și implementarea de protecții active la supracurent pentru porturile periferice.
    \item \textbf{Dezvoltarea carcasei și asamblarea prototipului:} Proiectarea asistată de calculator (folosind AutoCAD) a unei carcase dedicate optimizate pentru printare 3D și asamblarea fizică a componentelor SMD.
\end{itemize}

Acest sistem se adresează atât pasionaților de electronică, oferind o platformă hardware deschisă și modulară, cât și aplicațiilor comerciale care necesită densitate mare de calcul într-un volum redus, cu avantajul major de a permite upgrade-ul ulterior al modulului de procesare fără modificarea plăcii de bază.

\section{Structura lucrării} Lucrarea este structurată în patru capitole principale, începând cu „Introducerea”, care oferă
o prezentare generală a temei, a motivației și a obiectivelor proiectului.

\textit{Capitolul II} intitulat "Design", descrie proiectarea sistemului, detaliind selecția componentelor, procesul de proiectare a \ac{PCB}-ului, pozitionarea porturilor externe și diversele reguli și bune practici ce au fost luate în vedere în faza de proiectare.

\textit{Capitolul III} intitulat "Asamblare" este dedicat asamblării sistemului, detaliind matricea led integrată în sistem, proiectarea carcasei în care vor fi montate cele 2 plăci, asamblarea plăcii de bază, testarea și depanarea erorilor apărute.

Lucrarea se încheie cu o secțiune de concluzii, care evidențiază direcția de dezvoltare a proiectului, inclusiv luând în cosiderare modalitățiile prin care acesta poate fi pregătit pentru a ajunge un produs de serie.

\begin{figure}
  \centering
  
  \caption{Vedere frontală a PCB-ului in programul  \cite{kicad}.}
  \label{fig:pcb-front-kicad}
\end{figure}

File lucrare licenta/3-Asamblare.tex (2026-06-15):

\chapter{Implementarea fizică}

\section{Matrice LED}

Mini PC-ul vine echipat cu o matrice LED \ref{fig:LED-Matrix} compusă din 220 LED-uri adresabile RGB cu driver WS2812C, acestea au nevoie doar de un pin de input și sunt legate în serie, acestea formând o matrice 44x5.
Acestea sunt controlate de un Microcontroller ESP32-C3 care comunică cu modulul LattePanda prin USB, iar microcontrollerul fiind integrat direct pe \ac{PCB}-ul principal.

\begin{figure}
  \centering
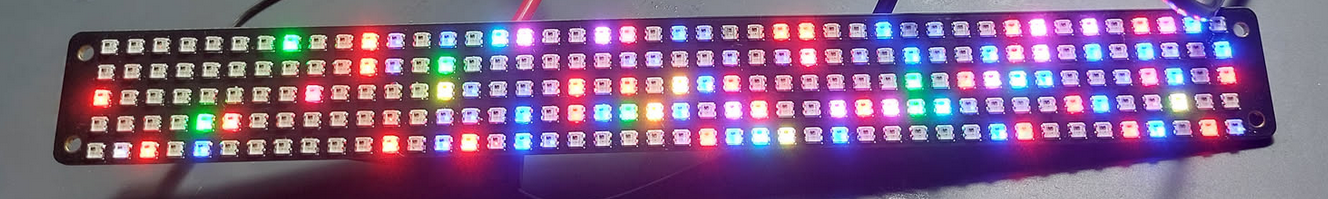
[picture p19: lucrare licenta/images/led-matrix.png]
  
  \caption{Matricea LED RGB asamblată.}
  \label{fig:LED-Matrix}
\end{figure}

\section{Carcasa}
Pentru a monta cele două \ac{PCB}-uri am proiectat o carcasă folosind AutoCAD, aceasta este formată din 2 piese principale printate 3d folosind filament PLA, un schelet ce include partea din față, lateralele și partea superioară \ref{fig:Front-case}, apoi un capac pentru partea inferioară și spate \ref{fig:back-case}. Cele 2 \ac{PCB}-uri sunt montate pe schelet, acesta incluzand și un panou de difuzie printat cu filament translucid PETG.

\begin{figure}
  \centering
  \begin{subfigure}[b]{0.45\linewidth}
    
    \caption{Partea frontală a carcasei.}
    \label{fig:Front-case}
  \end{subfigure}
  \begin{subfigure}[b]{0.45\linewidth}
    
    \caption{Partea din spate a carcasei.}
    \label{fig:back-case}
  \end{subfigure}

  \caption{Cele 2 părți ale carcasei.}
  \label{fig:Case}

\end{figure}

\section{Asamblare}
Pentru a asambla componentele pe \ac{PCB} am folosit șabloane din oțel inoxidabil, tăiate la laser, aceasta fiind produsă odată cu \ac{PCB}-ul, cu aceste șabloane am aplicat o pastă de fludor și am plasat fiecare componentă pe placă, începând cu matricea LED \ref{fig:LED-Matrix-Assembly} care are 220 LED-uri, apoi continuând cu \ac{PCB}-ul principal \ref{fig:Main-PCB-Assembly}, acesta având în jur de 500 de componente, dintre care 380 de componente pasive SMD de capsulă 0603 și 0402, 32 circuite integrate în capsule QFN, 16 tranzistori in capsula SOT și DFN, 20 de conectori și alte componente active sau pasive.

\begin{figure}
  \centering
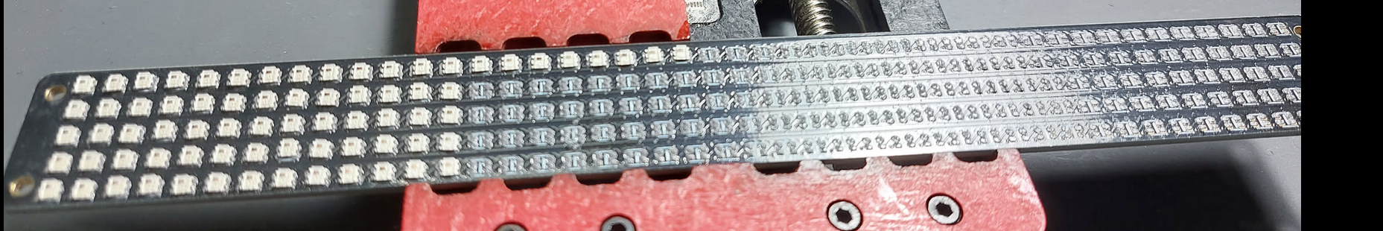
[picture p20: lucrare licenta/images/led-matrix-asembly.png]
  
  \caption{Matrice Led în timpul asamblării.}
  \label{fig:LED-Matrix-Assembly}
\end{figure}

\begin{figure}
  \centering
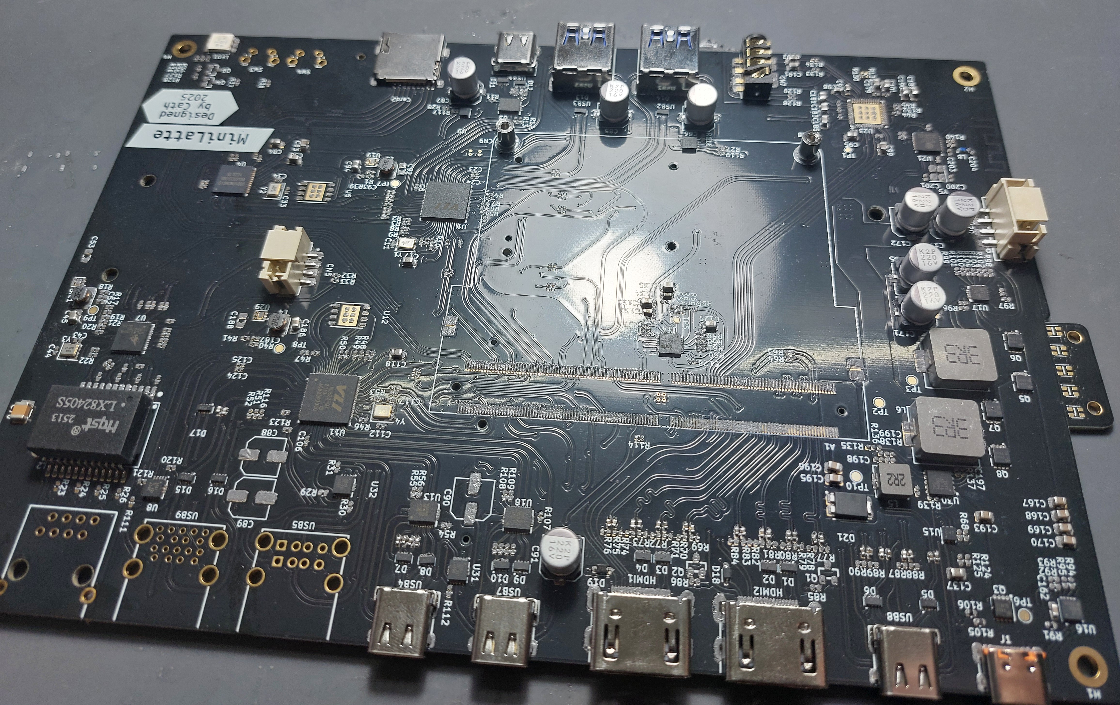
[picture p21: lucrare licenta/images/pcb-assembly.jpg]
  
  \caption{PCB-ul principal în timpul asambării în timpul asamblării.}
  \label{fig:Main-PCB-Assembly}
\end{figure}

\section{Testare și depanare}

Toate defectele prezentate în această secțiune au fost identificate în urma testării prototipului și ulterior corectate în proiectul \ac{PCB}. Din considerente de cost, varianta revizuită nu a mai fost trimisă în producție.

\subsection{Defect al circuitului de alimentare}
După asamblarea plăcii, procesul de testare a evidențiat inițial o problemă majoră: regulatorul de tensiune care coboară tensiunea de 20V la 5V și 3,3V nu pornea. Deoarece acesta asigură și alimentarea regulatorului de 17,5 V utilizat de modulul principal, nici acesta nu devenea operațional.

Cauza problemei a fost identificată ca fiind absența unor condensatoare necesare pentru funcționarea corectă a regulatorului \ac{LDO}, utilizat în faza inițială de pornire a circuitului intern al cipului, până la activarea convertorului DC-DC. Remedierea a constat în adăugarea unui condensator, realizată printr-o conexiune suplimentară între pinul circuitului integrat și un condensator montat ulterior pe placă (Figura \ref{fig:TPS-fix}).

\begin{figure}
  \centering
  \begin{subfigure}[b]{0.45\linewidth}
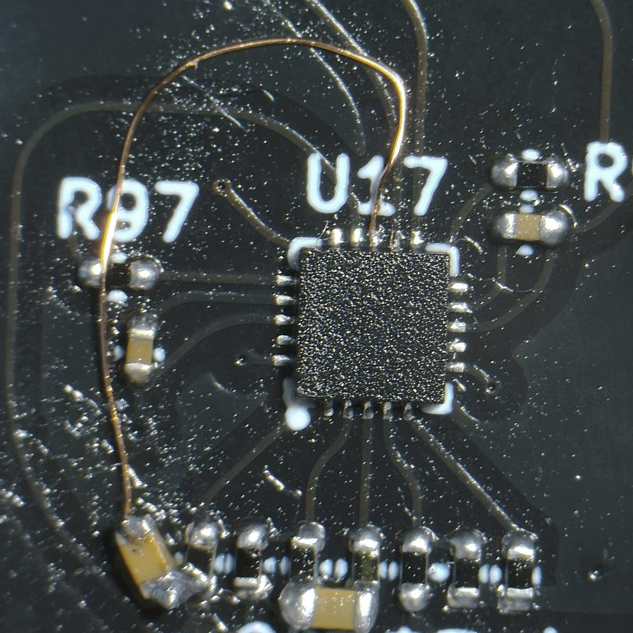
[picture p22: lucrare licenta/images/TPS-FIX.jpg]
    
    \caption{Firul ce leaga unul dintre LDO-uri de un condensator.}
    \label{fig:TPS-fix}
  \end{subfigure}
  \begin{subfigure}[b]{0.45\linewidth}
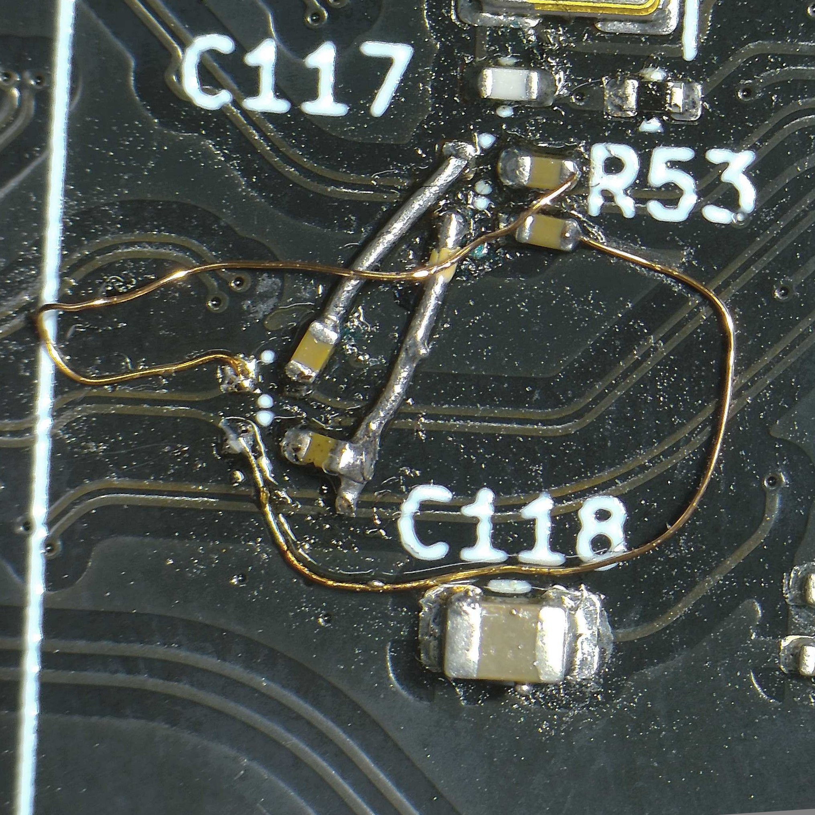
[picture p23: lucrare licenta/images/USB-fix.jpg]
    
    \caption{Repararea liniilor USB prin lipirea unor fire foarte subțiri.}
    \label{fig:USB-fix}
  \end{subfigure}
  \caption{Două reparații folosind fire subțiri.}

\end{figure}

\subsection{Defecte legate de protocoale}

Sistemul a pornit corespunzător și a permis încărcarea sistemului de operare. Testele ulterioare au evidențiat însă și alte deficiențe:
\begin{itemize}
  \item Un slot \ac{NVMe} nu funcționa, cauza fiind o lipire defectuoasă a unui pin;
  \item Controlerul Ethernet \textit{Realtek RTL8125} nu pornea, fiind necesară adăugarea unui rezistor de tip pull-up pe unul dintre pini;
  \item Timpul de inițializare în BIOS era neobișnuit de mare.
\end{itemize}

Investigațiile au arătat că problema legată de BIOS era cauzată de conectarea incorectă a liniilor USB 3.2 Gen 2 către hub-ul USB. Perechile diferențiale au fost conectate eronat (RX-RX și TX-TX), în loc de configurația corectă RX-TX și TX-RX. Această eroare a apărut din utilizarea unei topologii specifice conexiunilor între cip și port, în locul celei necesare pentru interconectarea a două cipuri. Corecția a fost realizată prin refacerea conexiunilor folosind fire (Figura \ref{fig:USB-fix}).
O altă problemă identificată a fost funcționarea incorectă a LED-ului RGB frontal, utilizat pentru indicarea stării sistemului: \textit{power off} (roșu - oprit), \textit{standby} (galben) și \textit{power on} (alb - pornit). LED-ul rămânea aprins în culoarea roșie imediat după alimentare, iar celelalte culori nu funcționau.
Cauza acestei deficiențe a fost utilizarea incorectă a tranzistoarelor MOSFET de tip N într-o configurație de tip high-side switching, în condițiile în care tensiunea de comandă pe poartă era comparabilă sau mai mică decât tensiunea drenă-sursă. În această situație, tranzistorul nu putea comuta corect.
Soluția corectă constă în utilizarea unei configurații de tip low-side switching (vezi Figura \ref{fig:low-fix} și Figura \ref{fig:low-high-conf}), în care tensiunea de comandă (3,3 V) este aplicată între poartă și masă, asigurând funcționarea corespunzătoare a tranzistorului și controlul corect al LED-ului.

\begin{figure}
  \centering
  \begin{subfigure}[b]{0.4\linewidth}
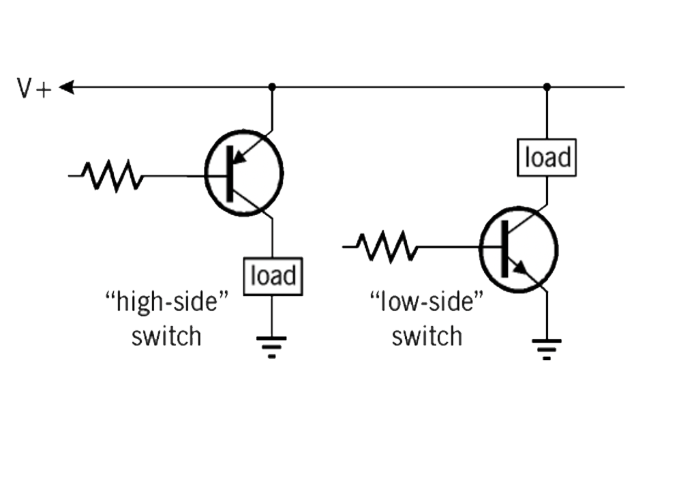
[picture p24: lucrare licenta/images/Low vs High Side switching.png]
    
    \caption{}
    \label{fig:low-high-conf}
  \end{subfigure}
  \begin{subfigure}[b]{0.55\linewidth}
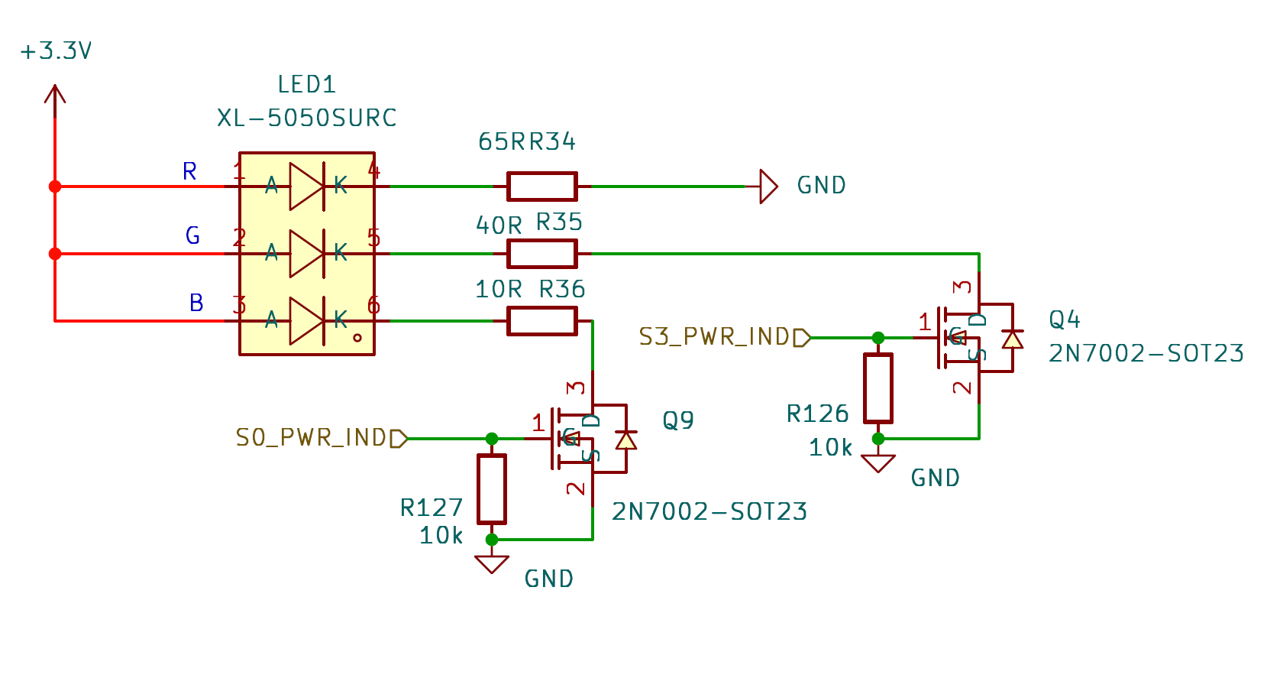
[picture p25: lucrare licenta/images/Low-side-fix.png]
    
    \caption{}
    \label{fig:low-fix}
  \end{subfigure}
  \caption{(a) Configurațiile de tip Low Side și High Side (b) Diagrama electrică reparată folosind un Low Side switch.}

\end{figure}

\subsection{Alte defecte nerezolvate}

Două defecte care nu a fost reparate pe placă dar care a fost reparate în proiect sunt:
\begin{itemize}
  \item Ventilatorul pornește la putere maximă odată cu alimentarea sistemului, pentru a remedia această problemă a fost adăugat un MOSFET care permite alimentarea sistemului doar când acesta este în starea de pornit, folosind același semnal ca LED-ul alb.
  \item Al doilea controller USB nu a fi putut fi reparat pentru a funcționa la viteze usb 3.2, acesta având punctele de lipire mai inaccesibile ca primul
\end{itemize}

\subsection{Testare în sisteme de operare}
Pentru a testa performanța sistemului am folosit sistemul de operare Windows 11.
Au fost testate (Tabelul \ref{Tab:performace}) timpul de pornire al sistemului în ambele sisteme de operare, viteza de internetului atât pe Wi-Fi cât și pe fir, viteza maximă de transmisiune pe USB dar și viteza maximă a SSD-urile conectate (fiind limitate de conexiunea PCIe x2).
Pentru testarea sistemului au fost folosite 3 SSD-uri SKhynix PC711 care rulează pe o interfață PCIe Gen3 x 4, capabile să satureze interfețele conectate. 

\begin{table}[h]
  \centering
  \rowcolors{2}{white}{lightgray!20}
  \begin{tabularx}{\textwidth}{X c}
    \toprule
    \rowcolor{gray!30}
    \textbf{Parametru Testat} & \textbf{Rezultat Măsurat (Windows 11)} \\ \midrule
    Timp de pornire           & 48\text{\,}s                               \\
    Viteza LAN                & 2,26\text{\,}Gbps                          \\
    Viteza SSD PCIe           & 1771\text{\,}MB/s (Read), 1673\text{\,}MB/s (Write) \\
    Viteza USB                & 2,5\text{\,}Gbps                           \\
    Scor Cinebench MultiCore  & 2750                                       \\ \bottomrule
  \end{tabularx}
  \caption{Performanțele măsurate ale sistemului în mediul de operare Windows 11.}
  \label{Tab:performace}
\end{table}

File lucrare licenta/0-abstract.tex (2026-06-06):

\begin{abstractpage}

\begin{abstract}{romanian}
Lucrarea de față prezintă proiectarea și realizarea unei plăci de bază dedicate modulului de calcul x86 \textit{LattePanda Mu}, având ca scop dezvoltarea unui sistem Mini PC compact și performant. Pentru a asigura o transmitere rapidă și stabilă a datelor, sistemul integrează o gamă extinsă de protocoale complexe de comunicație, întregul design fiind dezvoltat în jurul managementului riguros al consumului ridicat de curent, caracteristic arhitecturilor x86 și perifericelor atașate. Vor fi prezentate etapele de dezvoltare a hardware-ului, de la analiza conceptuală, proiectarea diagramelor electrice și selecția componentelor, până la realizarea circuitului imprimat. Lucrarea se încheie cu validarea experimentală a prototipului prin testarea stabilității în medii de operare reale.
\end{abstract}

\begin{abstract}{english}
This thesis presents the design and implementation of a dedicated motherboard for the x86 \textit{LattePanda Mu} compute module, aiming to develop a compact and high-performance Mini PC system. To ensure fast and stable data transmission, the system integrates a wide range of complex communication protocols, with the entire design centered around the rigorous power management required by x86 architectures and their peripherals. The stages of hardware development are presented, from conceptual analysis, schematic design, and component selection, to the printed circuit board layout. The thesis concludes with the experimental validation of the prototype by testing its stability under real operating conditions.
\end{abstract}

\end{abstractpage}

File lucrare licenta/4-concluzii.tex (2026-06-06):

\chapter{Concluzii și direcții viitoare}
\label{ch:concluzii}

Proiectul sistemului Mini PC bazat pe modulul \textit{LattePanda Mu} demonstrează fezabilitatea proiectării unui \ac{PCB} complex cu 4 straturi și a realizării unui sistem integrat performant. Prototipul a fost validat experimental, demonstrând stabilitate în rularea sistemelor de operare moderne. Arhitectura implementată oferă o flexibilitate ridicată, deschizând calea pentru extinderea funcționalităților plăcii sau pentru upgrade-ul direct al modulului de procesare x86.
Pentru tranziția de la stadiul de prototip de laborator la un produs de serie, sunt necesare optimizări structurate pe două direcții principale:

\begin{itemize}
    \item \textbf{Eficientizarea fabricației carcasei:} Reproiectarea geometrică a carcasei pentru a fi compatibilă cu tehnologia de \textit{injection molding} (turnare prin injecție). Această tranziție este critică pentru producția de masă, reducând drastic timpul de execuție per unitate și asigurând o rezistență structurală superioară față de printarea 3D.
    \item \textbf{Alinierea PCB-ului la normele pentru producție:} Uniformizarea orientării componentelor SMD și optimizarea amprentelor conform standardelor IPC. 
\end{itemize}

Prin atingerea tuturor obiectivelor propuse, proiectul se materializează într-o platformă hardware fiabilă și complet funcțională. Validarea interconectării magistralelor de mare viteză și a sistemului complex de alimentare pe un PCB unic confirmă viabilitatea designului, acesta servind drept o bază robustă atât pentru o viitoare comercializare, cât și pentru dezvoltarea de noi sisteme de calcul compacte.

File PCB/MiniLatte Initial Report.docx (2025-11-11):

# LattePanda Mu Mini Pc

Proiectul este bazat pe un modul LattePanda Mu (https://www.lattepanda.com/lattepanda-mu) care incorporeaza un Procesor Quad Core Intel N100 si 8Gb de Ram LPDDR5, ținta proiectului a fost de a creea un mini calculator pe baza acestui modul si a proiecta PCB-ul, carcasa si alte componente conexe in jurul acestui modul.

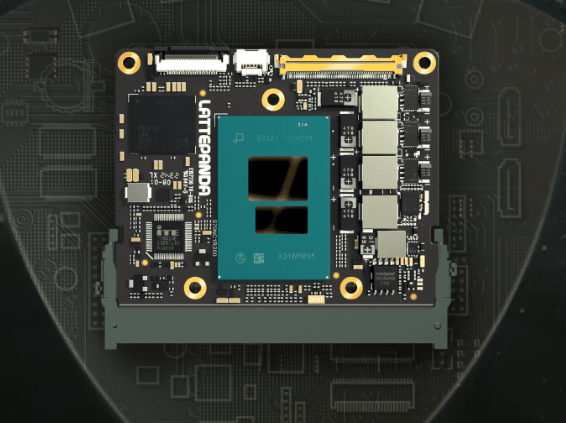
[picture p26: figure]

Descriere Generala

Modulul LattePanda Mu este foarte flexibil in conectivitatea, acesta avand 9 magistrale de viteza mare care pot fi configurate sa fie ori USB 3.2 Gen 2 (10Gbps) sau PCIE 3.0. Eu am ales sa folosesc 2 linii de usb si 7 de pcie. Cele de usb fiind destul de rapide si de usor de bifurcat folosind HUB-uri direct pe placa. Pe partea de usb am ales sa am 4 porturi usb de viteza mare in partea din spate (din care unul type c) si 3 in partea din fata (din care unul type c) iar al 4-lea din fata va fi folosit pentru un Integrat pentru interfațarea cu carduri de memorie SD de viteză mare. Pe partea de ieșiri video, placa va dispune de 2 porturi hdmi care suportă rezoluții până la 4K. Iar pe partea de conectivitate PCB-ul va dispune de un slot pentru placa de wifi și bluetooth, aceasta putând fi ușor schimbată dacă este necesară una mai perfomantă, și de asemenea va dispune de o placă de rețea de mare viteză pentru internet pe fir (2.5GbE).

Alimentarea se face printr-un port usb C care folosește standardul Power Delivery și suportă tensiuni de alimentare de la 12v la 20v. Motivul principal pentru care am folosit acest standard este popularitatea sa și ușurința cu care poți să găsești surse de alimentare de acest tip pe piață.

Și de asemenea pe partea de audio, placa o să dispună de o mufă de căști combo (căști + microfon). In ultimul rând placa va dispune de un microcontroller ESP32 care va controla o matrice de LED-uri rgb programabile, care o sa arate diferite informatii despre sistem, notificari sau o sa poata sa fie programabil pentru a afisa ce doreste utilizatorul.

Diagramă bloc

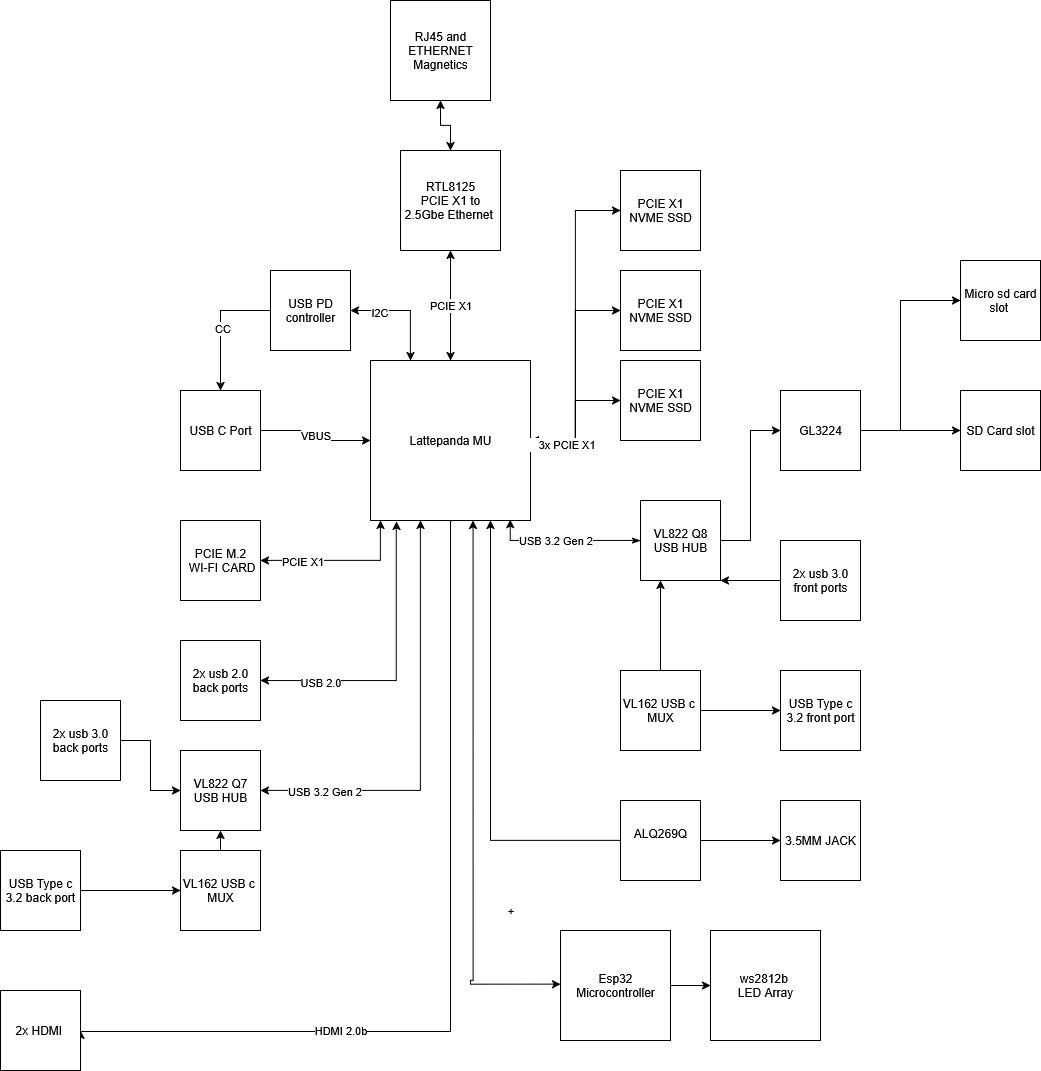
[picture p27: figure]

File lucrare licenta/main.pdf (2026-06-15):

UNIVERSITATEA DIN BUCUREȘTI

FACULTATEA DE
MATEMATICĂ ȘI INFORMATICĂ

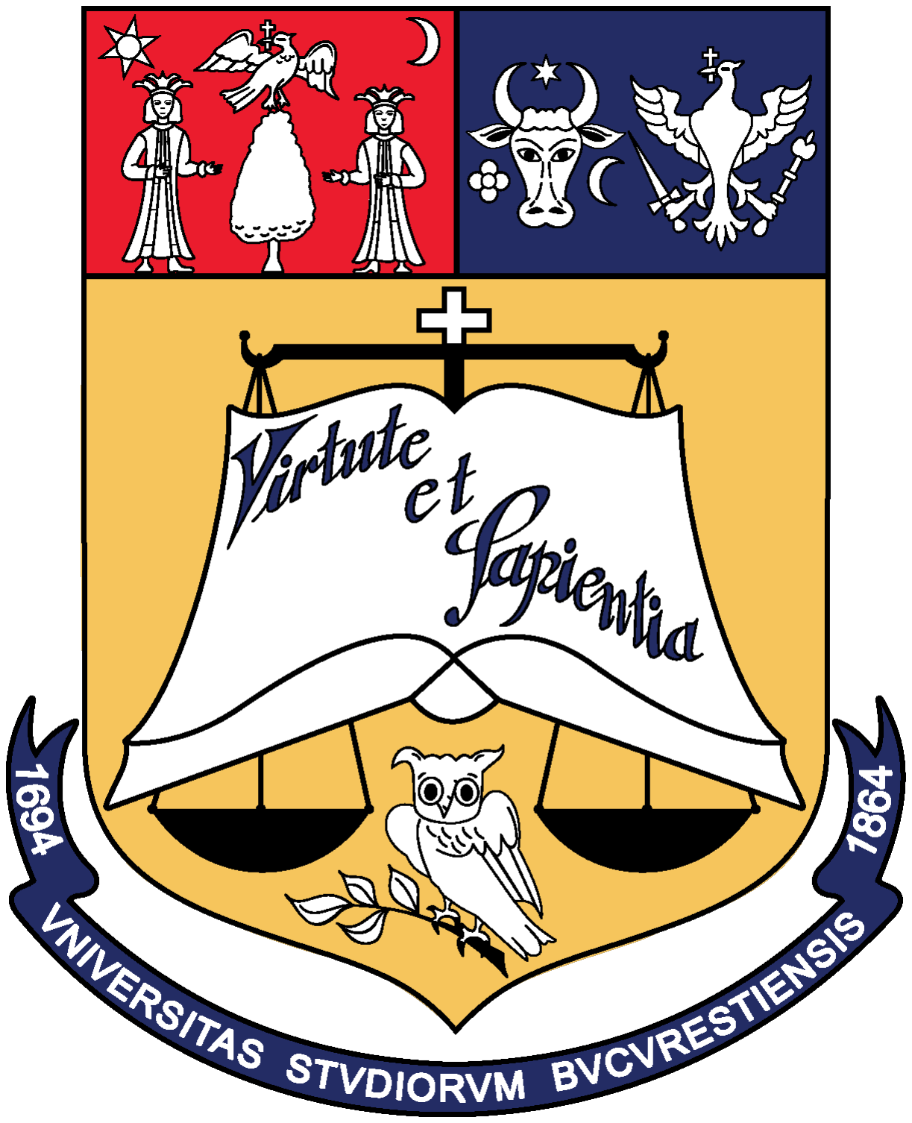
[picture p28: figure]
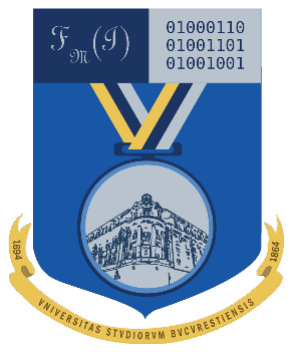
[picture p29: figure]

SPECIALIZAREA TEHNOLOGIA INFORMAȚIEI

## Proiect de Diplomă

# MINI PC FOLOSIND MODULUL

# LATTEPANDA MU

Absolvent

Bălan Liviu-Florin

Coordonator științific

Conf. Dr. Alexe Bogdan

Drd. Dumitriu Andrei

## București, iunie 2026

Rezumat

Lucrarea de față prezintă proiectarea și realizarea unei plăci de bază dedicate modulului de cal-

cul x86 LattePanda Mu, având ca scop dezvoltarea unui sistem Mini PC compact și performant.

Pentru a asigura o transmitere rapidă și stabilă a datelor, sistemul integrează o gamă extinsă de

protocoale complexe de comunicație, întregul design fiind dezvoltat în jurul managementului

riguros al consumului ridicat de curent, caracteristic arhitecturilor x86 și perifericelor atașate.

Vor fi prezentate etapele de dezvoltare a hardware-ului, de la analiza conceptuală, proiectarea di-

agramelor electrice și selecția componentelor, până la realizarea circuitului imprimat. Lucrarea

se încheie cu validarea experimentală a prototipului prin testarea stabilității în medii de operare

reale.

Abstract

This thesis presents the design and implementation of a dedicated motherboard for the x86 Lat-

tePanda Mu compute module, aiming to develop a compact and high-performance Mini PC

system. To ensure fast and stable data transmission, the system integrates a wide range of com-

plex communication protocols, with the entire design centered around the rigorous power man-

agement required by x86 architectures and their peripherals. The stages of hardware develop-

ment are presented, from conceptual analysis, schematic design, and component selection, to

the printed circuit board layout. The thesis concludes with the experimental validation of the

prototype by testing its stability under real operating conditions.

# Cuprins

1 Introducere | 8
2 Proiectarea sistemului hardware | 11
3 Implementarea fizică | 22

4 Concluzii și direcții viitoare | 27
Bibliografie | 28

# Listă de figuri

1.1 Formă finală | | 9
1.2 Vedere frontală a PCB-ului in programul [6] | | 10
2.1 Modulul LattePanda Mu | | 12

2.2 Diagramă bloc a sistemului MiniLatte. Prezintă interconexiunile între modulul

LattePanda Mu și componentele periferice | | 13
2.3 Port-urile PCB-ului | | 14
2.4 Poziționarea straturilor PCBului | | 18
2.5 Poziționarea componentelor pe placă | | 19
2.6 Corecții ale Intra si Inter Pair Skew | | 19
2.7 Plan de curent cu o lățime de 7,3mm | | 21
3.1 Matricea LED RGB asamblată | | 22
3.2 Cele 2 părți ale carcasei | | 23
3.3 Matrice Led în timpul asamblării | | 23
3.4 PCB-ul principal în timpul asambării în timpul asamblării | | 24
3.5 Două reparații folosind fire subțiri | | 25

3.6 (a) Configurațiile de tip Low Side și High Side (b) Diagrama electrică reparată

folosind un Low Side switch | 26

# Listă de tabele

2.1 Bugetul estimat pentru consumul de putere al sistemului | | 20
3.1 Performanțele măsurate ale sistemului în mediul de operare Windows 11. . . . | 26

# Lista de abrevieri

PCIe Peripheral Component Interconnect Express

HDMI High-Definition Multimedia Interface

HDAudio High Definition Audio

NVMe Non-Volatile Memory Express

SSD Solid State Drive

PCB Printed Circuit Board

SD Secure Digital

DDR Double Data Rate

PD Power Delivery

LDO Low DropOut

# Capitolul 1

# Introducere

În acest capitol se prezintă contextul proiectului, obiectivele urmărite și motivația alegerii

platformei hardware. Lucrarea vizează dezvoltarea unui sistem compact și performant, capabil

să ruleze aplicații complexe într-un format redus, utilizând arhitectura x86 modernă pentru a

asigura compatibilitatea cu o gamă largă de soluții software.

Proiectul propune dezvoltarea unui sistem Mini PC bazat pe modulul LattePanda Mu (vezi

Figura 1.1), integrat pe o placă de bază, care include interfețe de mare viteza (USB 3.2, HDMI),

stocare NVMe și conectivitate WiFi și Ethernet.

Proiectul prevede proiectarea unei plăci de bază (vezi Figura 1.2) care se integreze modulul,

să îl conecteze la interfețele exterioare, direct sau prin anumite cip-uri, și să gestioneze tensiunile

și curenții necesari functionării în parametrii optimi.

Acest sistem se adresează atât pasionațiilor de electronica care pot dezvolta pe baza proiec-

tului conceput dar și a tuturor persoanelor care iși doresc un sistem compact cu posibilitea de a

schimba modulul cu unul mai performant pe viitor.

## 1.1 Obiectivele proiectului și contribuția personală

Contribuția originală a acestei lucrări constă în proiectarea integrală, realizarea fizică și vali-

darea experimentală a unei plăci de bază complexe de la stadiul de schemă electrică de principiu

până la prototipul funcțional. Obiectivele tehnice specifice îndeplinite pe parcursul proiectului

au fost:

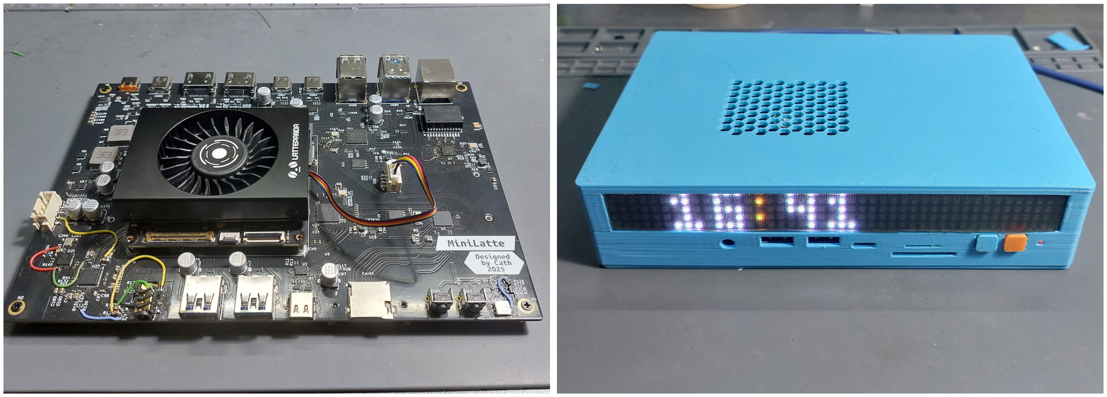
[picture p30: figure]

(a) PCB-ul asamblat. | (b) Sistemul asambalat în carcasă.

Figura 1.1: Formă finală.

- Proiectarea schemei electrice: Integrarea modulului x86 cu diverse circuite integrate

auxiliare (hub-uri USB 3.2, controlere Ethernet 2.5 Gbps și circuite de management al

curentului).

- Dezvoltarea layout-ului PCB complex: Rutarea unui circuit imprimat cu 4 straturi, cu

respectarea constrângerilor stricte de integritate a semnalului (Signal Integrity) și control

al impedanței diferențiale pentru linii de mare viteză (USB 3.2 Gen 2, PCIe Gen 3 și

HDMI 2.0).

- Managementul alimentării și protecției: Dimensionarea geometrică a planurilor de cu-

pru pentru curenți mari (până la 10 A) conform standardului IPC-2152 și implementarea

de protecții active la supracurent pentru porturile periferice.

- Dezvoltarea carcasei și asamblarea prototipului: Proiectarea asistată de calculator (fo-

losind AutoCAD) a unei carcase dedicate optimizate pentru printare 3D și asamblarea

fizică a componentelor SMD.

Acest sistem se adresează atât pasionaților de electronică, oferind o platformă hardware

deschisă și modulară, cât și aplicațiilor comerciale care necesită densitate mare de calcul într-un

volum redus, cu avantajul major de a permite upgrade-ul ulterior al modulului de procesare fără

modificarea plăcii de bază.


Figura 1.2: Vedere frontală a PCB-ului in programul [6].

## 1.2 Structura lucrării

Lucrarea este structurată în patru capitole principale, începând cu „Introducerea”, care oferă

o prezentare generală a temei, a motivației și a obiectivelor proiectului.

Capitolul II intitulat ”Design”, descrie proiectarea sistemului, detaliind selecția componen-

telor, procesul de proiectare a Printed Circuit Board (PCB)-ului, pozitionarea porturilor externe

și diversele reguli și bune practici ce au fost luate în vedere în faza de proiectare.

Capitolul III intitulat ”Asamblare” este dedicat asamblării sistemului, detaliind matricea led

integrată în sistem, proiectarea carcasei în care vor fi montate cele 2 plăci, asamblarea plăcii de

bază, testarea și depanarea erorilor apărute.

Lucrarea se încheie cu o secțiune de concluzii, care evidențiază direcția de dezvoltare a

proiectului, inclusiv luând în cosiderare modalitățiile prin care acesta poate fi pregătit pentru a

ajunge un produs de serie.

# Capitolul 2

# Proiectarea sistemului hardware

## 2.1 LattePanda Mu

LattePanda Mu (vezi Figura 2.1) este un modul de calcul performant, cu dimensiuni compa-

rabile unui card bancar, proiectat de compania DFRobot. Acesta este conceput pentru integrare

în produse hardware personalizate, fiind potrivit atât pentru proiecte de tip hobby, cât și pentru

aplicații industriale.

Seria actuală cuprinde modele cu diferite configurații de procesoare și memorie, acestea

menținând intercompatibilitatea la nivel de pinout. Modulul este proiectat pentru a fi inserat într-

o carrier board (placă de bază) folosind un slot standard SO-DIMM Double Data Rate (DDR)4.

Această alegere constructivă este justificată de densitatea mare de pini, necesară pentru a expune

numeroasele interfețe de comunicare către placa purtătoare.

Flexibilitatea platformei este sporită de posibilitatea modificării BIOS-ului, permițând utili-

zatorului să configureze alocarea liniilor de date pentru a prioritiza, după caz, numărul de sloturi

Peripheral Component Interconnect Express (PCIe) sau porturile USB disponibile. Specificați-

ile tehnice ale unității utilizate în prezenta lucrare sunt următoarele:

În ceea ce privește conectivitatea, configurația aleasă pentru acest sistem include:

- 2 porturi USB 3.2 Gen 2 (10 Gbps);
- 7 linii PCIe Gen 3.


Figura 2.1: Modulul LattePanda Mu [9].

## 2.2 Conexiuni - Diagramă Bloc

În această secțiune sunt descrise conexiunile și este explicată diagrama bloc din Figura 2.2.

Sistemul utilizează standardul USB Power Delivery (PD) pentru alimentare, alegere motivată

datorită costului redus și a disponibilității ridicate pe piață a surselor compatibile. Fiind un stan-

dard universal și nu unul proprietar, acesta oferă flexibilitate maximă în alegerea alimentatorului

și facilitează înlocuirea rapidă a acestuia în caz de necesitate. Toate conexiunile sunt realizate

intern, la nivelul plăcii de bază, pentru a reduce latențele și a crește fiabilitatea.

Pentru extinderea capacităților de conectare a perifericelor, au fost integrate două hub-uri

USB care pun la dispoziție 4 porturi USB 3.2 Gen 2 fiecare, acestea sunt atât USB type A cât și

USB type C. Suplimentar, la unul dintre hub-urile USB este conectat un cititor de carduri dual

Secure Digital (SD), utilizând lățimea de bandă oferită de interfața USB 3.2 Gen 2. Amplasarea

acestora fiind observată în 2.3a și 2.3b.

Semnalul video este distribuit prin trei porturi digitale: două High-Definition Multimedia

Interface (HDMI) 2.0 acestea suportând rezoluții de până la 4K 60Hz, și un DisplayPort 1.4 (via

USB-C) care suportă rezoluții până de la 4K 120Hz. Pe partea de procesare audio, sistemul uti-

lizează un cip ALC269Q ce comunică prin protocolul High Definition Audio (HDAudio), acesta

fiind conectat la un port de tip TRRS, permițând semnale audio stereo și microfon.

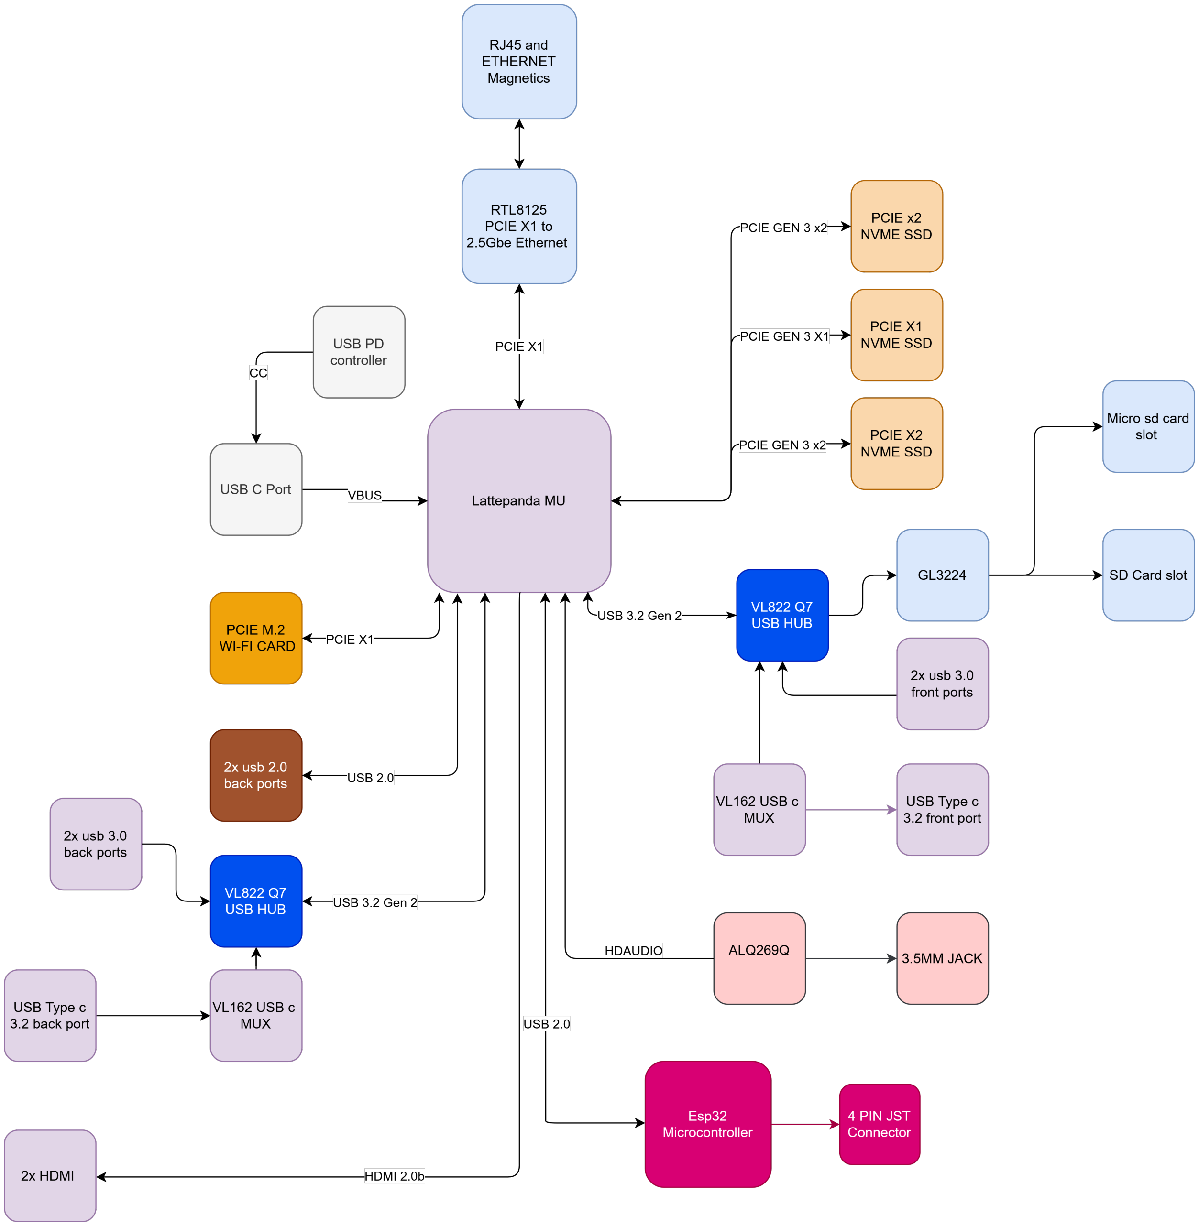
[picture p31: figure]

Figura 2.2: Diagramă bloc a sistemului MiniLatte. Prezintă interconexiunile între modulul LattePanda Mu și componentele periferice.


(a) Port-urile din partea din față a PCB-ului.


(b) Port-urile din partea din spate a PCB-ului.


(c) Port-urile de pe spatele PCB-ului.

Figura 2.3: Port-urile PCB-ului.

În ceea ce privește conectivitatea la rețea, sistemul oferă două posibilități distincte, ambele

bazate pe magistrala PCIe Gen 3:

1. Wireless: prin intermediul unui modul Wi-Fi instalat în slotul dedicat de pe placa de bază;
2. Ethernet: utilizând controlerul Realtek RTL8125, care suportă viteze de transfer de până

la 2.5 Gbps via PCIe Gen 3.

Capacitatea de stocare poate fi extinsă considerabil prin cele trei sloturi destinate unități-

lor Solid State Drive (SSD) M.2 Non-Volatile Memory Express (NVMe) poziționate pe partea

inferioară a plăcii (vezi Figura 2.3c). .

## 2.3 Arhitectura hardware și selecția componentelor

Placa de bază pentru acest modul a fost proiectată folosind KiCad 9, folosind ca bază docu-

mentația dată de creatorii modulului, dar și țindând cont de regulile de proiectare atât pe partea

de diagrame electrice dar și pe partea de design de PCB. Pornind de la diagrama bloc,procesul

de selecție a componentelor s-a bazat pe mai multe criterii, precum costul, disponibilitatea pe

piață, familiaritatea cu producătorul și calitatea documentației tehnice.

- ITE IT8851FN-128: O excepție notabilă în procesul de achiziție o reprezintă acest cip

de management. Deși este un circuit integrat dificil de procurat prin canalele standard de

distribuție, utilizarea sa a fost obligatorie din cauza compatibilității exclusive cu firmware-

ul proprietar furnizat de LattePanda, neexistând o alternativă viabilă pe piață la momentul

proiectării.

- VIA Labs VL822-Q7 [8]: Reprezintă hub-ul USB 3.2 Gen 2 principal al sistemului.

A fost selectat datorită capacității de a gestiona 4 porturi din downstream cu o lățime

de bandă de până la 10 Gbps per port, oferind un raport excelent între performanța de

transmisie și costul de implementare.

- VIA Labs VL162 [7]: Acest circuit integrat acționează ca un switch de date/multiplexor

de mare viteză pe 4 canale, special conceput pentru configurarea porturilor USB Type-C.

Rolul său critic este de a detecta orientarea fizică a conectorului USB-C inserat (prin mo-

nitorizarea pinilor CC1/CC2) și de a ruta corect liniile diferențiale de date (TX/RX) către

hub-ul principal, asigurând conexiunea indiferent de poziția în care utilizatorul conectează

cablul.

- Realtek RTL8125, care oferă suport pentru viteze de până la 2.5 Gbps, menținând toto-

dată un cost competitiv.

- Circuite Integrate de la Texas Instruments (TPS51275 [2], TPS54561 [3], TPS62590 [4]),

iar pentru protecția la supracurent au fost alese cipurile TPS2553 și TPS2561. Alegerea

acestor componente s-a bazat pe eficiența ridicată, documentația detaliată și disponibili-

tatea acestora.

- Memoriile NOR W25Q128JV (folosit pentru stocarea BIOS-ului) respectiv W25Q32JV

(folosite pentru stocarea firmware-ului pentru VL822 și GL3224), acesta au fost alese

datorită costului redus.

- Genesis Logic GL3224-ONY: - controller pentru carduri SD și MicroSD, acesta a fost

ales din cauza costului redus și a pentru suportul interfețelor de tip UHS-I care permit

viteze până la 104MB/s.

- Hynetek HUSB238 - USB Type-C PD controller, acesta a fost ales din cauza costului

redus și a modului foarte ușor de a programa tensiunile pe care le cere încărcătorului

folosind doar doi rezistori, unul pentru curentul maxim și unul pentru tensiune.

- Espressif Systems ESP32-C3FN4: - Microcontroller cu WiFi și 4Mb de memorie inter-

nă, a fost ales datorită prețului, memoriei interne, circuitului intern USB-UART dar și a

performanței. Microcontrollerul a fost ales în locul locul pinilor GPIO nativi ai modulului

LattePanda Mu din cauza faptului că aceștia nu erau funcționali la momentul proiectării

sistemului, dar și pentru a degreva procesorul de sarcina de a controla LED-urile.

## 2.4 Diagrama electrică

Diagrama electrică reprezintă etapa inițială esențială în procesul de proiectare. în cazul sis-

temului MiniLatte, aceasta este structurată pe 19 pagini și descrie în detaliu toate conexiunile

dintre modulul LattePanda Mu, circuite integrate și conectori utilizați. Schema a fost organizată

pe blocuri funcționale, precum „USB3”, „HDMI” și „PCIe_SSD”, pentru a facilita înțelegerea

și verificarea conexiunilor.

Pentru realizarea acesteia au fost utilizate în principal fișele de date ale componentelor,

specificațiile protocoalelor de comunicație, precum și documentația oficială DFRobot [9] [10].

Aceasta din urmă a oferit informații esențiale despre modul de interconectare al modulului Lat-

tePanda Mu, servind drept referință pentru integrarea componentelor externe.

## 2.5 Rutare trasee și Integritatea Semnalului

Etapa de rutare a traseelor pe PCB a avut un rol critic în asigurarea funcționării corecte a

sistemului, în special datorită prezenței interfețelor de mare viteză, precum USB 3.2 Gen 2,

PCIe Gen 3 și HDMI 2.0. Pentru a preveni degradarea semnalului din cauza reflexiilor și a

fenomenului de crosstalk (diafonie), placa a fost realizată pe 4 straturi, asigurând o structură

de tip stripline (traseu rutat pe stratul exterior) și microstrip (traseu rutat pe stratul interior) cu

impedanță controlată.

Impedanța caracteristică a liniilor de transmisie depinde direct de geometria traseelor și

de proprietățile dielectrice ale materialului suport (FR4, cu o permisivitate dielectrică relati-

vă εr ≈ 4.2). Pentru protocoalele utilizate, s-au calculat și implementat următoarele valori țintă

ale impedanței diferențiale (Zdiff ):

- Interfețele USB 3.2 și PCIe Gen 3: Zdiff = 90 Ω ± 10%
- Interfața HDMI 2.0: Zdiff = 100 Ω ± 10%
- Liniilor de semnal de tip single-ended (asimetrice): Z0 = 50 Ω ± 10%

Determinarea lățimii traseelor (w) și a distanței de separare în cadrul perechii (s) s-a realizat

utilizând calculatorul de impedanță integrat în suita KiCad 9, corelat cu structura geometrică a

substratului (vezi Figura 2.4).

Un aspect fundamental în layout-ul circuitelor de înaltă frecvență îl reprezintă asigurarea

unui return path (traseu de retur) continuu și de impedanță minimă pentru curentul de înaltă

frecvență. Curentul de retur tinde să urmeze calea de sub traseul de semnal, în cel mai apropiat

plan de referință solid (GND). În cadrul proiectului, straturile interioare (In1.GND și In2.GND)

acționează ca planuri de masă continue.

### 2.5.1 Poziționarea componentelor

Prima etapă a rutării este plasarea preliminară a componentelor. În acest caz, s-a pornit de

la poziționarea slotului pentru modulul LattePanda Mu și a conectorilor externi, în funcție de


Figura 2.4: Poziționarea straturilor PCBului.

distribuția pinilor modulului (vezi Figura 2.5). Având în vedere că primii pini sunt dedicați ali-

mentării, s-a ales poziționarea circuitelor de alimentare în proximitatea conectorului de intrare,

definind astfel zona stângă a plăcii ca zonă principală de alimentare. Următoarele semnale sunt

cele video, începând cu portul USB-C (care transmite semnal DisplayPort), urmat de cele două

porturi HDMI. Ulterior, au fost poziționate porturile USB, conectate la pinii din extremitatea

dreaptă a modulului, necesitând spațiu suplimentar pentru integrarea hub-ului USB. În final, a

fost amplasat portul Ethernet. Dimensiunile plăcii au fost determinate de amplasarea conecto-

rilor: lățimea este de 190 mm, stabilită de porturile din partea posterioară, iar lungimea de 130

mm, determinată de porturile din partea frontală.

### 2.5.2 Perechi diferențiale

Transmisia diferențiale reprezintă principala metodă de transmitere a datelor la viteze ridi-

cate, fiind folosite în majoritatea protocoalelor de comunicare moderne cum ar fi HDMI, USB și

PCIe În proiectarea PCB-urilor, perechile diferențiale reprezintă două trasee paralele, cu lungimi

egale și cu o distanță controlată între ele. Diferența de lungime dintre cele două trasee, definită

ca Intra Pair Skew (decalaj în cadrul aceleiași perechi) vezi Figura 2.6a, trebuie să se încadreze

într-o toleranță strictă, de exemplu, 0,125 mm pentru USB 3.0 [1]. În cazul protocoalelor care


Figura 2.5: Poziționarea componentelor pe placă.

utilizează mai multe perechi diferențiale în paralel (precum HDMI sau DisplayPort), este nece-

sară și gestionarea fenomenului de Inter-Pair Skew (decalaj între perechi diferite), fiind impusă

o toleranță strictă de maximum 1 mm pentru a asigura sincronizarea corectă a fluxurilor de date

la frecvențe ridicate. Corecțiile geometrice au fost implementate prin adăugarea de serpentine

pentru compensarea lungimii pe stratul exterior (vezi Figura 2.6b).


(a) Corecție a Intra Pair Skew pe o pereche diferețială.
(b) Corecție a Inter Pair Skew pe cele 4 perechi diferețiale ale unui port HDMI.

Figura 2.6: Corecții ale Intra si Inter Pair Skew.

## 2.6 Proiectarea rețelei de alimentare și a protecțiilor

Datorită numărului mare de interfețe disponibile, un lucru important in acest design a fost

proiectarea in jurul consumului de curent, atât a modulului LattePanda Mu dar și componentelor

de pe placa și a diverselor dispozitive conectate.

Modulul este alimentat printr-un port USB Type C utilizând protocolul USB PD versiunea

3.0, controlat de un cip HUSB238, responsabil de negocierea tensiunii cu sursa de alimentare,

solicitând un profil de 20 V și 3,25 A (65 W) [11], valoare standard pentru acest protocol.

Tensiunea este coborâtă la 17,5 V pentru modulul LattePanda Mu folosind regulatorul TPS54561.

Consumul modulului fiind de 10-15 W în modul standard și până la 15 W în modul Boost, de

asemenea sunt generate tensiuni auxiliare de 3,3 V și 5 V folosind cipul TPS51275.

Puterea necesară la intrare (Pin) a fost dimensionată prin calcularea consumului total al sis-

temului (Tabelul 2.1). Luând în considerare o eficiență conservatoare de η = 90% a regulatorelor

DC-DC, puterea totală necesară la intrare a fost estimată matematic prin ecuația:

Pin =

Ptotal_consumatori
η

=

48, 6 W
0, 90
≈ 54 W | (2.1)

Profilul de 65 W a fost ales deorece este primul profil disponibil deasupra puterii calculate

de 54 W, acest lucru oferind o marjă de siguranță critică pentru a absorbi eventualele vârfuri

tranzitorii de curent.

Consumator | Nr. Unități | Consum Maxim / Unitate | Consum Total
LattePanda Mu | 1 | 15 W | 15 W
USB 2.0 Periferice | 2 | 0,5 W | 1 W
USB 3.2 Periferice | 6 | 0,9 W | 5,4 W
Realtek RTL8125 | 1 | 1 W | 1 W
Genesis Logic GL3224 | 1 | 0,5 W | 0,5 W
ESP32-C3 | 1 | 1,1 W | 1,1 W
LED-uri WS2812C | 220 | 0,068 W | 15 W
SSD-uri NVMe | 3 | 1,83 W | 5,5 W
Modul Wi-Fi | 1 | 2,5 W | 2,5 W
VIA Labs VL822-Q7 | 2 | 0,8 W | 1,6 W
Consum total | 48,6W

Tabel 2.1: Bugetul estimat pentru consumul de putere al sistemului.


Figura 2.7: Plan de curent cu o lățime de 7,3mm.

Traseele de alimentare au fost dimensionate corespunzător curenților implicați. Conform

standardului IPC-2152 [5], lățimea planului principal de alimentare de după regulatorul de 3, 3 V

a fost dimensionată la 7.3 mm (vezi Figura 2.7), urmând ca acestea să se reducă progresiv după

alimentarea consumatorilor principali. Acest calcul garantează că, la un curent maxim de 10 A,

creșterea de temperatură locală a cuprului (ΔT ) nu depășește 10∘C față de mediul ambiant.

Pe liniile de 3, 3 V și 5 V, unde curentul este distribuit către mai multe periferice expuse ex-

tern (porturile USB), s-a implementat o arhitectură de protecție activă. S-au integrat circuitele

TPS2553 și TPS2561 de la Texas Instruments, care acționează ca limitatoare de curent reglabi-

le și comutatoare inteligente. Acestea monitorizează în timp real curentul absorbit de porturile

USB, limitându-l la 0, 5 A pentru USB 2.0 și respectiv 0, 9 A pentru USB 3.2. În cazul unui

scurtcircuit extern, cipul decuplează linia defectă într-un timp de răspuns de ordinul microse-

cundelor, protejând sursa principală și prevenind resetarea accidentală a întregului sistem Mini

PC.

# Capitolul 3

# Implementarea fizică

## 3.1 Matrice LED

Mini PC-ul vine echipat cu o matrice LED 3.1 compusă din 220 LED-uri adresabile RGB cu

driver WS2812C, acestea au nevoie doar de un pin de input și sunt legate în serie, acestea for-

mând o matrice 44x5. Acestea sunt controlate de un Microcontroller ESP32-C3 care comunică

cu modulul LattePanda prin USB, iar microcontrollerul fiind integrat direct pe PCB-ul principal.

## 3.2 Carcasa

Pentru a monta cele două PCB-uri am proiectat o carcasă folosind AutoCAD, aceasta este

formată din 2 piese principale printate 3d folosind filament PLA, un schelet ce include partea din

față, lateralele și partea superioară 3.2a, apoi un capac pentru partea inferioară și spate 3.2b. Cele

2 PCB-uri sunt montate pe schelet, acesta incluzand și un panou de difuzie printat cu filament

translucid PETG.


Figura 3.1: Matricea LED RGB asamblată.


(a) Partea frontală a carcasei. | (b) Partea din spate a carcasei.

Figura 3.2: Cele 2 părți ale carcasei.


Figura 3.3: Matrice Led în timpul asamblării.

## 3.3 Asamblare

Pentru a asambla componentele pe PCB am folosit șabloane din oțel inoxidabil, tăiate la

laser, aceasta fiind produsă odată cu PCB-ul, cu aceste șabloane am aplicat o pastă de fludor și

am plasat fiecare componentă pe placă, începând cu matricea LED 3.3 care are 220 LED-uri,

apoi continuând cu PCB-ul principal 3.4, acesta având în jur de 500 de componente, dintre care

380 de componente pasive SMD de capsulă 0603 și 0402, 32 circuite integrate în capsule QFN,

16 tranzistori in capsula SOT și DFN, 20 de conectori și alte componente active sau pasive.

## 3.4 Testare și depanare

Toate defectele prezentate în această secțiune au fost identificate în urma testării prototipului

și ulterior corectate în proiectul PCB. Din considerente de cost, varianta revizuită nu a mai fost

trimisă în producție.

### 3.4.1 Defect al circuitului de alimentare

După asamblarea plăcii, procesul de testare a evidențiat inițial o problemă majoră: regulato-

rul de tensiune care coboară tensiunea de 20V la 5V și 3,3V nu pornea. Deoarece acesta asigură


Figura 3.4: PCB-ul principal în timpul asambării în timpul asamblării.

și alimentarea regulatorului de 17,5 V utilizat de modulul principal, nici acesta nu devenea ope-

rațional.

Cauza problemei a fost identificată ca fiind absența unor condensatoare necesare pentru

funcționarea corectă a regulatorului Low DropOut (LDO), utilizat în faza inițială de pornire

a circuitului intern al cipului, până la activarea convertorului DC-DC. Remedierea a constat

în adăugarea unui condensator, realizată printr-o conexiune suplimentară între pinul circuitului

integrat și un condensator montat ulterior pe placă (Figura 3.5a).

### 3.4.2 Defecte legate de protocoale

Sistemul a pornit corespunzător și a permis încărcarea sistemului de operare. Testele ulteri-

oare au evidențiat însă și alte deficiențe:

- Un slot NVMe nu funcționa, cauza fiind o lipire defectuoasă a unui pin;
- Controlerul Ethernet Realtek RTL8125 nu pornea, fiind necesară adăugarea unui rezistor

de tip pull-up pe unul dintre pini;

- Timpul de inițializare în BIOS era neobișnuit de mare.

Investigațiile au arătat că problema legată de BIOS era cauzată de conectarea incorectă a


(a) Firul ce leaga unul dintre LDO-uri de un condensator.
(b) Repararea liniilor USB prin lipirea unor fire foarte subțiri.

Figura 3.5: Două reparații folosind fire subțiri.

liniilor USB 3.2 Gen 2 către hub-ul USB. Perechile diferențiale au fost conectate eronat (RX-

RX și TX-TX), în loc de configurația corectă RX-TX și TX-RX. Această eroare a apărut din

utilizarea unei topologii specifice conexiunilor între cip și port, în locul celei necesare pentru

interconectarea a două cipuri. Corecția a fost realizată prin refacerea conexiunilor folosind fire

(Figura 3.5b). O altă problemă identificată a fost funcționarea incorectă a LED-ului RGB fron-

tal, utilizat pentru indicarea stării sistemului: power off (roșu - oprit), standby (galben) și power

on (alb - pornit). LED-ul rămânea aprins în culoarea roșie imediat după alimentare, iar cele-

lalte culori nu funcționau. Cauza acestei deficiențe a fost utilizarea incorectă a tranzistoarelor

MOSFET de tip N într-o configurație de tip high-side switching, în condițiile în care tensiunea

de comandă pe poartă era comparabilă sau mai mică decât tensiunea drenă-sursă. În această si-

tuație, tranzistorul nu putea comuta corect. Soluția corectă constă în utilizarea unei configurații

de tip low-side switching (vezi Figura 3.6b și Figura 3.6a), în care tensiunea de comandă (3,3

V) este aplicată între poartă și masă, asigurând funcționarea corespunzătoare a tranzistorului și

controlul corect al LED-ului.

### 3.4.3 Alte defecte nerezolvate

Două defecte care nu a fost reparate pe placă dar care a fost reparate în proiect sunt:


(a) (b)

Figura 3.6: (a) Configurațiile de tip Low Side și High Side (b) Diagrama electrică reparată folosind un Low Side switch.

- Ventilatorul pornește la putere maximă odată cu alimentarea sistemului, pentru a remedia

această problemă a fost adăugat un MOSFET care permite alimentarea sistemului doar

când acesta este în starea de pornit, folosind același semnal ca LED-ul alb.

- Al doilea controller USB nu a fi putut fi reparat pentru a funcționa la viteze usb 3.2, acesta

având punctele de lipire mai inaccesibile ca primul

### 3.4.4 Testare în sisteme de operare

Pentru a testa performanța sistemului am folosit sistemul de operare Windows 11. Au fost

testate (Tabelul 3.1) timpul de pornire al sistemului în ambele sisteme de operare, viteza de

internetului atât pe Wi-Fi cât și pe fir, viteza maximă de transmisiune pe USB dar și viteza

maximă a SSD-urile conectate (fiind limitate de conexiunea PCIe x2). Pentru testarea sistemului

au fost folosite 3 SSD-uri SKhynix PC711 care rulează pe o interfață PCIe Gen3 x 4, capabile

să satureze interfețele conectate.

Parametru Testat | Rezultat Măsurat (Windows 11)
Timp de pornire | 48 s
Viteza LAN | 2,26 Gbps
Viteza SSD PCIe | 1771 MB/s (Read), 1673 MB/s (Write)
Viteza USB | 2,5 Gbps
Scor Cinebench MultiCore | 2750

Tabel 3.1: Performanțele măsurate ale sistemului în mediul de operare Windows 11.

# Capitolul 4

# Concluzii și direcții viitoare

Proiectul sistemului Mini PC bazat pe modulul LattePanda Mu demonstrează fezabilitatea

proiectării unui PCB complex cu 4 straturi și a realizării unui sistem integrat performant. Prototi-

pul a fost validat experimental, demonstrând stabilitate în rularea sistemelor de operare moderne.

Arhitectura implementată oferă o flexibilitate ridicată, deschizând calea pentru extinderea func-

ționalităților plăcii sau pentru upgrade-ul direct al modulului de procesare x86. Pentru tranziția

de la stadiul de prototip de laborator la un produs de serie, sunt necesare optimizări structurate

pe două direcții principale:

- Eficientizarea fabricației carcasei: Reproiectarea geometrică a carcasei pentru a fi com-

patibilă cu tehnologia de injection molding (turnare prin injecție). Această tranziție este

critică pentru producția de masă, reducând drastic timpul de execuție per unitate și asigu-

rând o rezistență structurală superioară față de printarea 3D.

- Alinierea PCB-ului la normele pentru producție: Uniformizarea orientării componen-

telor SMD și optimizarea amprentelor conform standardelor IPC.

Prin atingerea tuturor obiectivelor propuse, proiectul se materializează într-o platformă har-

dware fiabilă și complet funcțională. Validarea interconectării magistralelor de mare viteză și a

sistemului complex de alimentare pe un PCB unic confirmă viabilitatea designului, acesta ser-

vind drept o bază robustă atât pentru o viitoare comercializare, cât și pentru dezvoltarea de noi

sisteme de calcul compacte.

# Bibliografie

[1] Texas Instruments, High-Speed Layout Guidelines for Signal Conditioners and USB Hubs,

## 2025, URL: https://www.ti.com/lit/an/slla414a/slla414a.pdf, (accessed:

24.03.2026).

[2] Texas Instruments, TPS51275 Datasheet, URL: https : / / www . ti . com / lit / ds /

symlink/tps51275.pdf, (https://www.ti.com/lit/ds/symlink/tps51275.pdf) (accessed: 04.05.2026).

[3] Texas Instruments, TPS54561 Datasheet, URL: https : / / www . ti . com / lit / ds /

symlink/tps54561.pdf, (https://www.ti.com/lit/ds/symlink/tps54561.pdf) (accessed: 04.05.2026).

[4] Texas Instruments, TPS62590 Datasheet, URL: https : / / www . ti . com / lit / ds /

symlink/tps62590.pdf, (https://www.ti.com/lit/ds/symlink/tps62590.pdf) (accessed: 04.05.2026).

[5] IPC, IPC-2152 : Standard for Determining Current Carrying Capacity in Printed Board
Design, URL: https://www.electronics.org/TOC/IPC-2152.pdf.
[6] KiCad, KiCad - Schematic Capture {&} PCB Design Software, URL: https : / / www .
kicad.org/.
[7] Via Labs, VL162 Datasheet, URL: https://www.lcsc.com/datasheet/C19270896.

pdf, (https://www.lcsc.com/datasheet/C19270896.pdf) (accessed: 04.05.2026).

[8] Via Labs, VL822-Q7 Datasheet, URL: https://www.lcsc.com/datasheet/C42419379.

pdf, (https://www.lcsc.com/datasheet/C42419379.pdf) (accessed: 04.05.2026).

[9] LattePandaTeam, LattePanda Documentation, URL: https://docs.lattepanda.com/
content/mu_edition/introduction/, (https://docs.lattepanda.com/content/mu_edition/introduction/) (accessed: 24.03.2026).
[10] LattePandaTeam, LattePanda-Mu, URL: https : / / github . com / LattePandaTeam /

LattePanda-Mu, (https://github.com/LattePandaTeam/LattePanda-Mu) (accessed: 24.03.2026).

[11] USB Implementers Forum, USB Power Delivery Specification Revision 3.2, URL: https:
//www.usb.org/document-library/usb-power-delivery.

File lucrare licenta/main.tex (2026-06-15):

% Sablon pentru realizarea lucrarii de licenta, conform cu recomandarile
% din ghidul de redactare:
% - https://fmi.unibuc.ro/finalizare-studii/

% Multumiri lui Gabriel Majeri, acest sablon a fost creat pe baza
% codului sursa a lucrarii sale de licenta. 
% Codul sursa: https://github.com/GabrielMajeri/bachelors-thesis
% Website: https://www.gabrielmajeri.ro/
%
% Acest sablon este licentiat sub Creative Commons Attribution 4.0 International License.
% modificat 8 noiembrie 2024

\documentclass[12pt, a4paper]{report}

% Suport pentru diacritice și alte simboluri
\usepackage{fontspec}

% Font Times New Roman
\setmainfont{Times New Roman}

% Suport pentru mai multe limbi
\usepackage{polyglossia}

% Setează limba textului la română
\setdefaultlanguage{romanian}
% Am nevoie de engleză pentru rezumat
\setotherlanguages{english}

% Indentează și primul paragraf al fiecărei noi secțiuni
\SetLanguageKeys{romanian}{indentfirst=true}

% Suport pentru diferite stiluri de ghilimele
\usepackage{csquotes}

\DeclareQuoteStyle{romanian}
  {\quotedblbase}
  {\textquotedblright}
  {\guillemotleft}
  {\guillemotright}

% Utilizează biblatex pentru referințe bibliografice
\usepackage[
    maxbibnames=50,
    sorting=nty
]{biblatex}
\gappto\captionsromanian{\renewcommand{\tablename}{Tabel}}
\addbibresource{bibliography.bib}

% Setează spațiere inter-linie (doublespacing din LaTeX este echivalentul setarii 1.5 in Microsoft Word)
\usepackage{setspace}
\doublespacing

% Modificarea geometriei paginii (cu margini de 2,5 cm) 
\usepackage[margin=2.5cm]{geometry}

% Include funcțiile de grafică
\usepackage{graphicx}
% Încarcă imaginile din directorul `images`
\graphicspath{{./images/}}

% Listări de cod
\usepackage{listings}

% Linkuri interactive în PDF
\usepackage[
    colorlinks,
    linkcolor={black},
    menucolor={black},
    citecolor={black},
    urlcolor={blue}
]{hyperref}

% Simboluri matematice codificate Unicode
\usepackage[warnings-off={mathtools-colon,mathtools-overbracket}]{unicode-math}

% Comenzi matematice
\usepackage{amsmath}
\usepackage{mathtools}

% Formule matematice
\newcommand{\bigO}[1]{\symcal{O}\left(#1\right)}
\DeclarePairedDelimiter\abs{\lvert}{\rvert}

% Suport pentru rezumat în două limbi
% Bazat pe https://tex.stackexchange.com/a/70818
\newenvironment{abstractpage}
  {\cleardoublepage\vspace*{\fill}\thispagestyle{empty}}
  {\vfill\cleardoublepage}
\renewenvironment{abstract}[1]
  {\bigskip\selectlanguage{#1}%
   \begin{center}\bfseries\abstractname\end{center}}
  {\par\bigskip}

% Suport pentru anexe
\usepackage{appendix}

% Stiluri diferite de headere și footere
\usepackage{fancyhdr}
\usepackage{acronym}
\usepackage{graphicx}
\usepackage{subcaption}
\usepackage{changepage}
\usepackage{float}
\usepackage{booktabs}
\usepackage{tabularx}
\usepackage[table]{xcolor}

% Metadate
\title{Mini PC folosind modulul LattePanda Mu}
\author{Bălan Liviu-Florin}

% Generează variabilele cu @
\makeatletter

\begin{document}

% Front matter
\cleardoublepage
\let\ps@plain

% Pagina de titlu
\include{0-title}
\restoregeometry
\newgeometry{
    margin=2.5cm
}

\fancypagestyle{main}{
  \fancyhf{}
  \renewcommand\headrulewidth{0pt}
  \fancyhead[C]{}
  \fancyfoot[C]{\thepage}
}

\addtocounter{page}{1}

% Rezumatul
\include{0-abstract}

\tableofcontents

\begingroup
\renewcommand{\addvspace}[1]{} % Anulează spațiul vertical dintre capitole
\listoffigures
\endgroup

\begingroup
\renewcommand{\addvspace}[1]{} % Anulează spațiul vertical dintre capitole
\listoftables
\endgroup

\chapter*{Lista de abrevieri}
\begin{acronym}
    \acro{PCIe}{Peripheral Component Interconnect Express}
    \acro{HDMI}{High-Definition Multimedia Interface}
    \acro{HDAudio}{High Definition Audio}
    \acro{NVMe}{Non-Volatile Memory Express}
    \acro{SSD}{Solid State Drive}
    \acro{PCB}{Printed Circuit Board}
    \acro{SD}{Secure Digital}
    \acro{DDR}{Double Data Rate}
    \acro{PD}{Power Delivery}
    \acro{LDO}{Low DropOut}

\end{acronym}

\captionsetup[subfigure]{margin={0pt, 15pt}}

% Main matter
\cleardoublepage
\pagestyle{main}
\let\ps@plain\ps@main

\include{1-introducere}
\include{2-hardware}
\include{3-Asamblare}
\include{4-concluzii}

\printbibliography[heading=bibintoc]

\end{document}

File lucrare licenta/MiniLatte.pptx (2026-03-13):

## MiniLatte

## agenda

- Introduction
- Building confidence
- Engaging the audience
- Visual aids
- Final tips & takeaways

## The power of communication

A person standing in front of a whiteboard

## Overcoming nervousness

A person holding a microphone and standing in front of a group of people

- Confidence-building strategies

## Engaging the audience

- Make eye contact with your audience to create a sense of intimacy and involvement
- Weave relatable stories into your presentation using narratives that make your message memorable and impactful
- Encourage questions and provide thoughtful responses to enhance audience participation
- Use live polls or surveys to gather audience opinions, promoting engagement and making sure the audience feel involved

## Selecting visual aids

- Enhancing your presentation

## Effective delivery techniques

- This is a powerful tool in public speaking. It involves varying pitch, tone, and volume to convey emotion, emphasize points, and maintain interest.
  - Pitch variation
  - Tone inflection
  - Volume control

- Effective body language enhances your message, making it more impactful and memorable.
  - Meaningful eye contact
  - Purposeful gestures
  - Maintain good posture
  - Control your expressions

## Navigating Q&A sessions

A person wearing a blue suit and headphones pointing at a computer

- Maintaining composure during the Q&A session is essential for projecting confidence and authority. Consider the following tips for staying composed:
- Stay calm
- Actively listen
- Pause and reflect
- Maintain eye contact

- Know your material in advance
- Anticipate common questions
- Rehearse your responses

## Speaking impact

- Your ability to communicate effectively will leave a lasting impact on your audience
- Effectively communicating involves not only delivering a message but also resonating with the experiences, values, and emotions of those listening

A person wearing glasses and a blue shirt

## Dynamic delivery

Metric | Measurement | Target | Actual
Audience attendance | # of attendees | 150 | 120
Engagement duration | Minutes | 60 | 75
Q&A interaction | # of questions | 10 | 15
Positive feedback | Percentage (%) | 90 | 95
Rate of information retention | Percentage (%) | 80 | 85

- Learn to infuse energy into your delivery to leave a lasting impression
- One of the goals of effective communication is to motivate your audience

## Final tips & takeaways

- Consistent rehearsal
  - Strengthen your familiarity
- Refine delivery style
  - Pacing, tone, and emphasis
- Timing and transitions
  - Aim for seamless, professional delivery
- Practice audience
  - Enlist colleagues to listen & provide feedback

- Seek feedback
- Reflect on performance
- Explore new techniques
- Set personal goals
- Iterate and adapt

## Speaking engagement metrics

Impact factor | Measurement | Target | Achieved
Audience interaction | Percentage (%) | 85 | 88
Knowledge retention | Percentage (%) | 75 | 80
Post-presentation surveys | Average rating | 4.2 | 4.5
Referral rate | Percentage (%) | 10 | 12
Collaboration opportunities | # of opportunities | 8 | 10

## Thank you

Brita Tamm
502-555-0152
brita@firstupconsultants.com
www.firstupconsultants.com

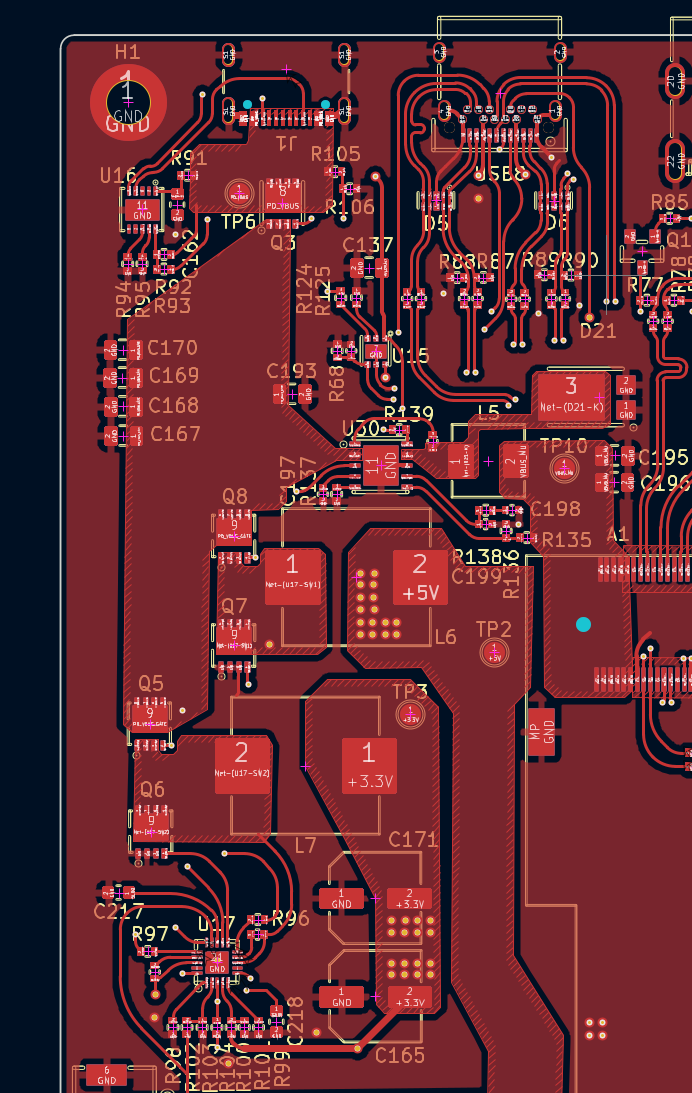
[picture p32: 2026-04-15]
lucrare licenta/images/main-power-rail.png

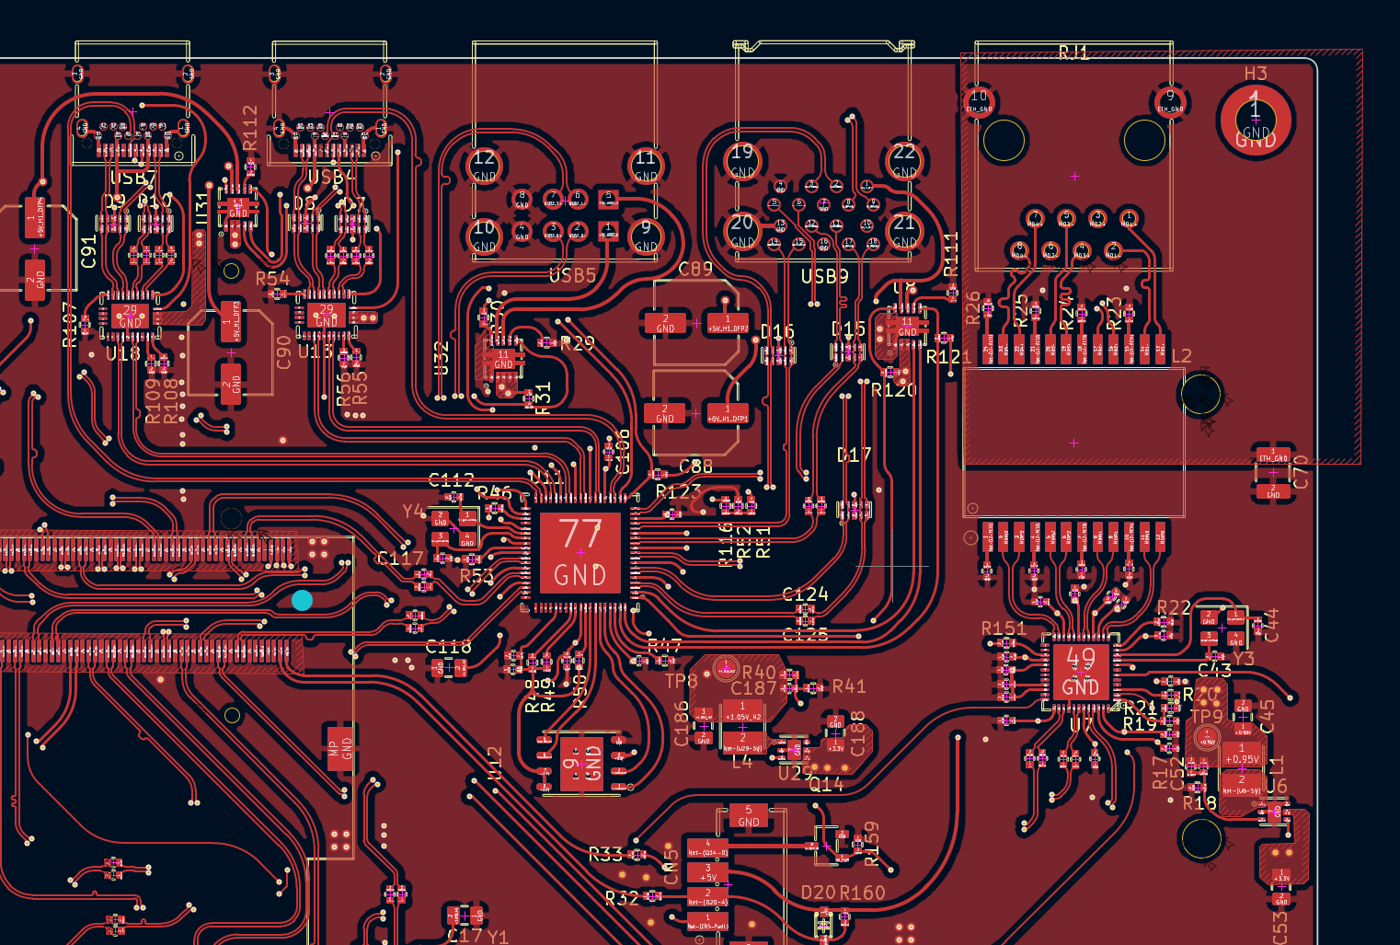
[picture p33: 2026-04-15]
lucrare licenta/images/USB-PORTS.png

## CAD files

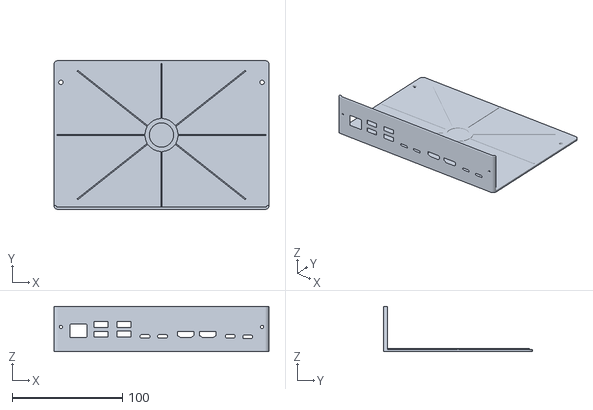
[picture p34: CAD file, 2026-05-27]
3d models/minilatte_back_warpedpcb.stl
195.0 x 135.0 x 41.0

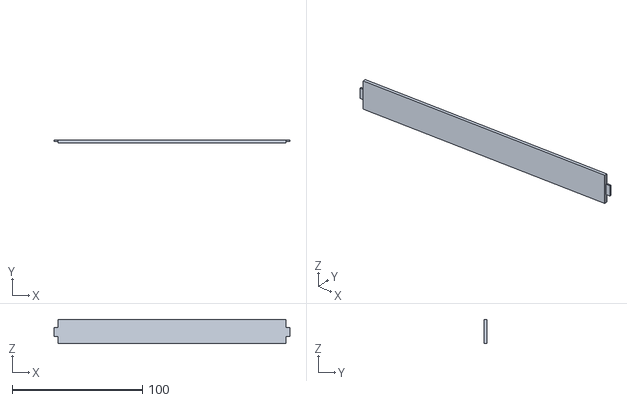
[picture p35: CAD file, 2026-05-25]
3d models/MiniLatte_window.stl
181.3 x 2.00 x 18.6

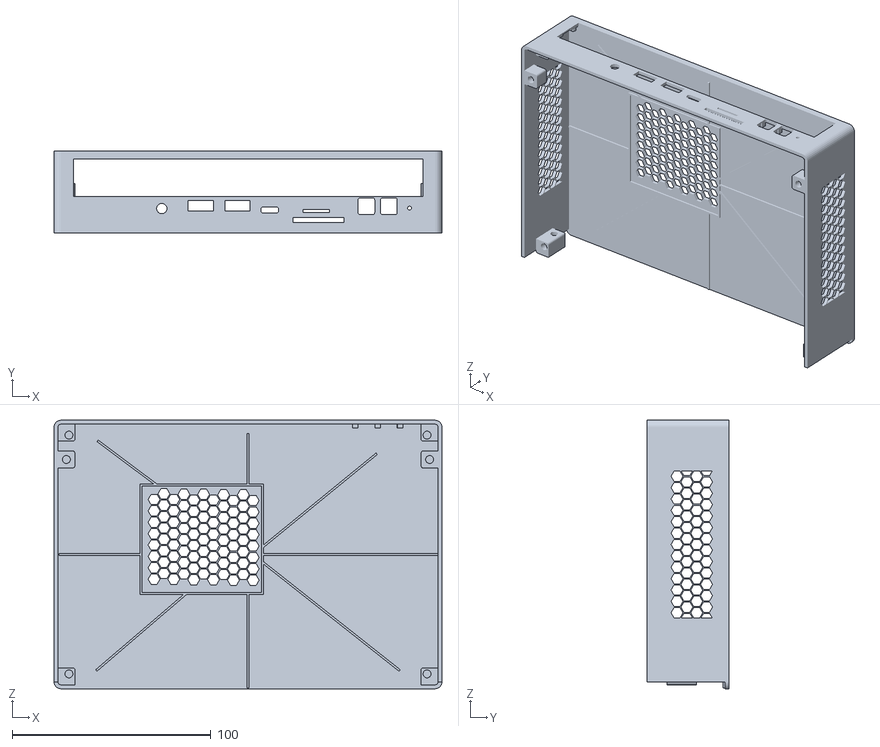
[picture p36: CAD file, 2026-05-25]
3d models/minilatte_front_n_top.stl
195.0 x 41.0 x 135.0

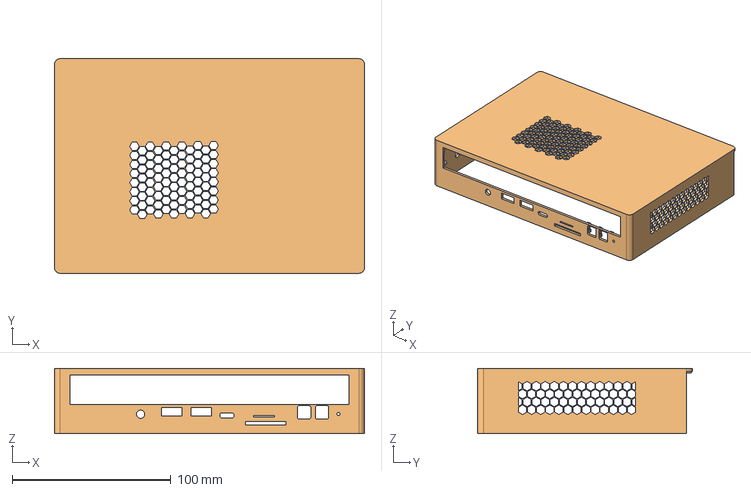
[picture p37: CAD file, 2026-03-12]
3d models/front.step
195.0 x 135.0 x 41.0 mm

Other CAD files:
3d models/front.dwg

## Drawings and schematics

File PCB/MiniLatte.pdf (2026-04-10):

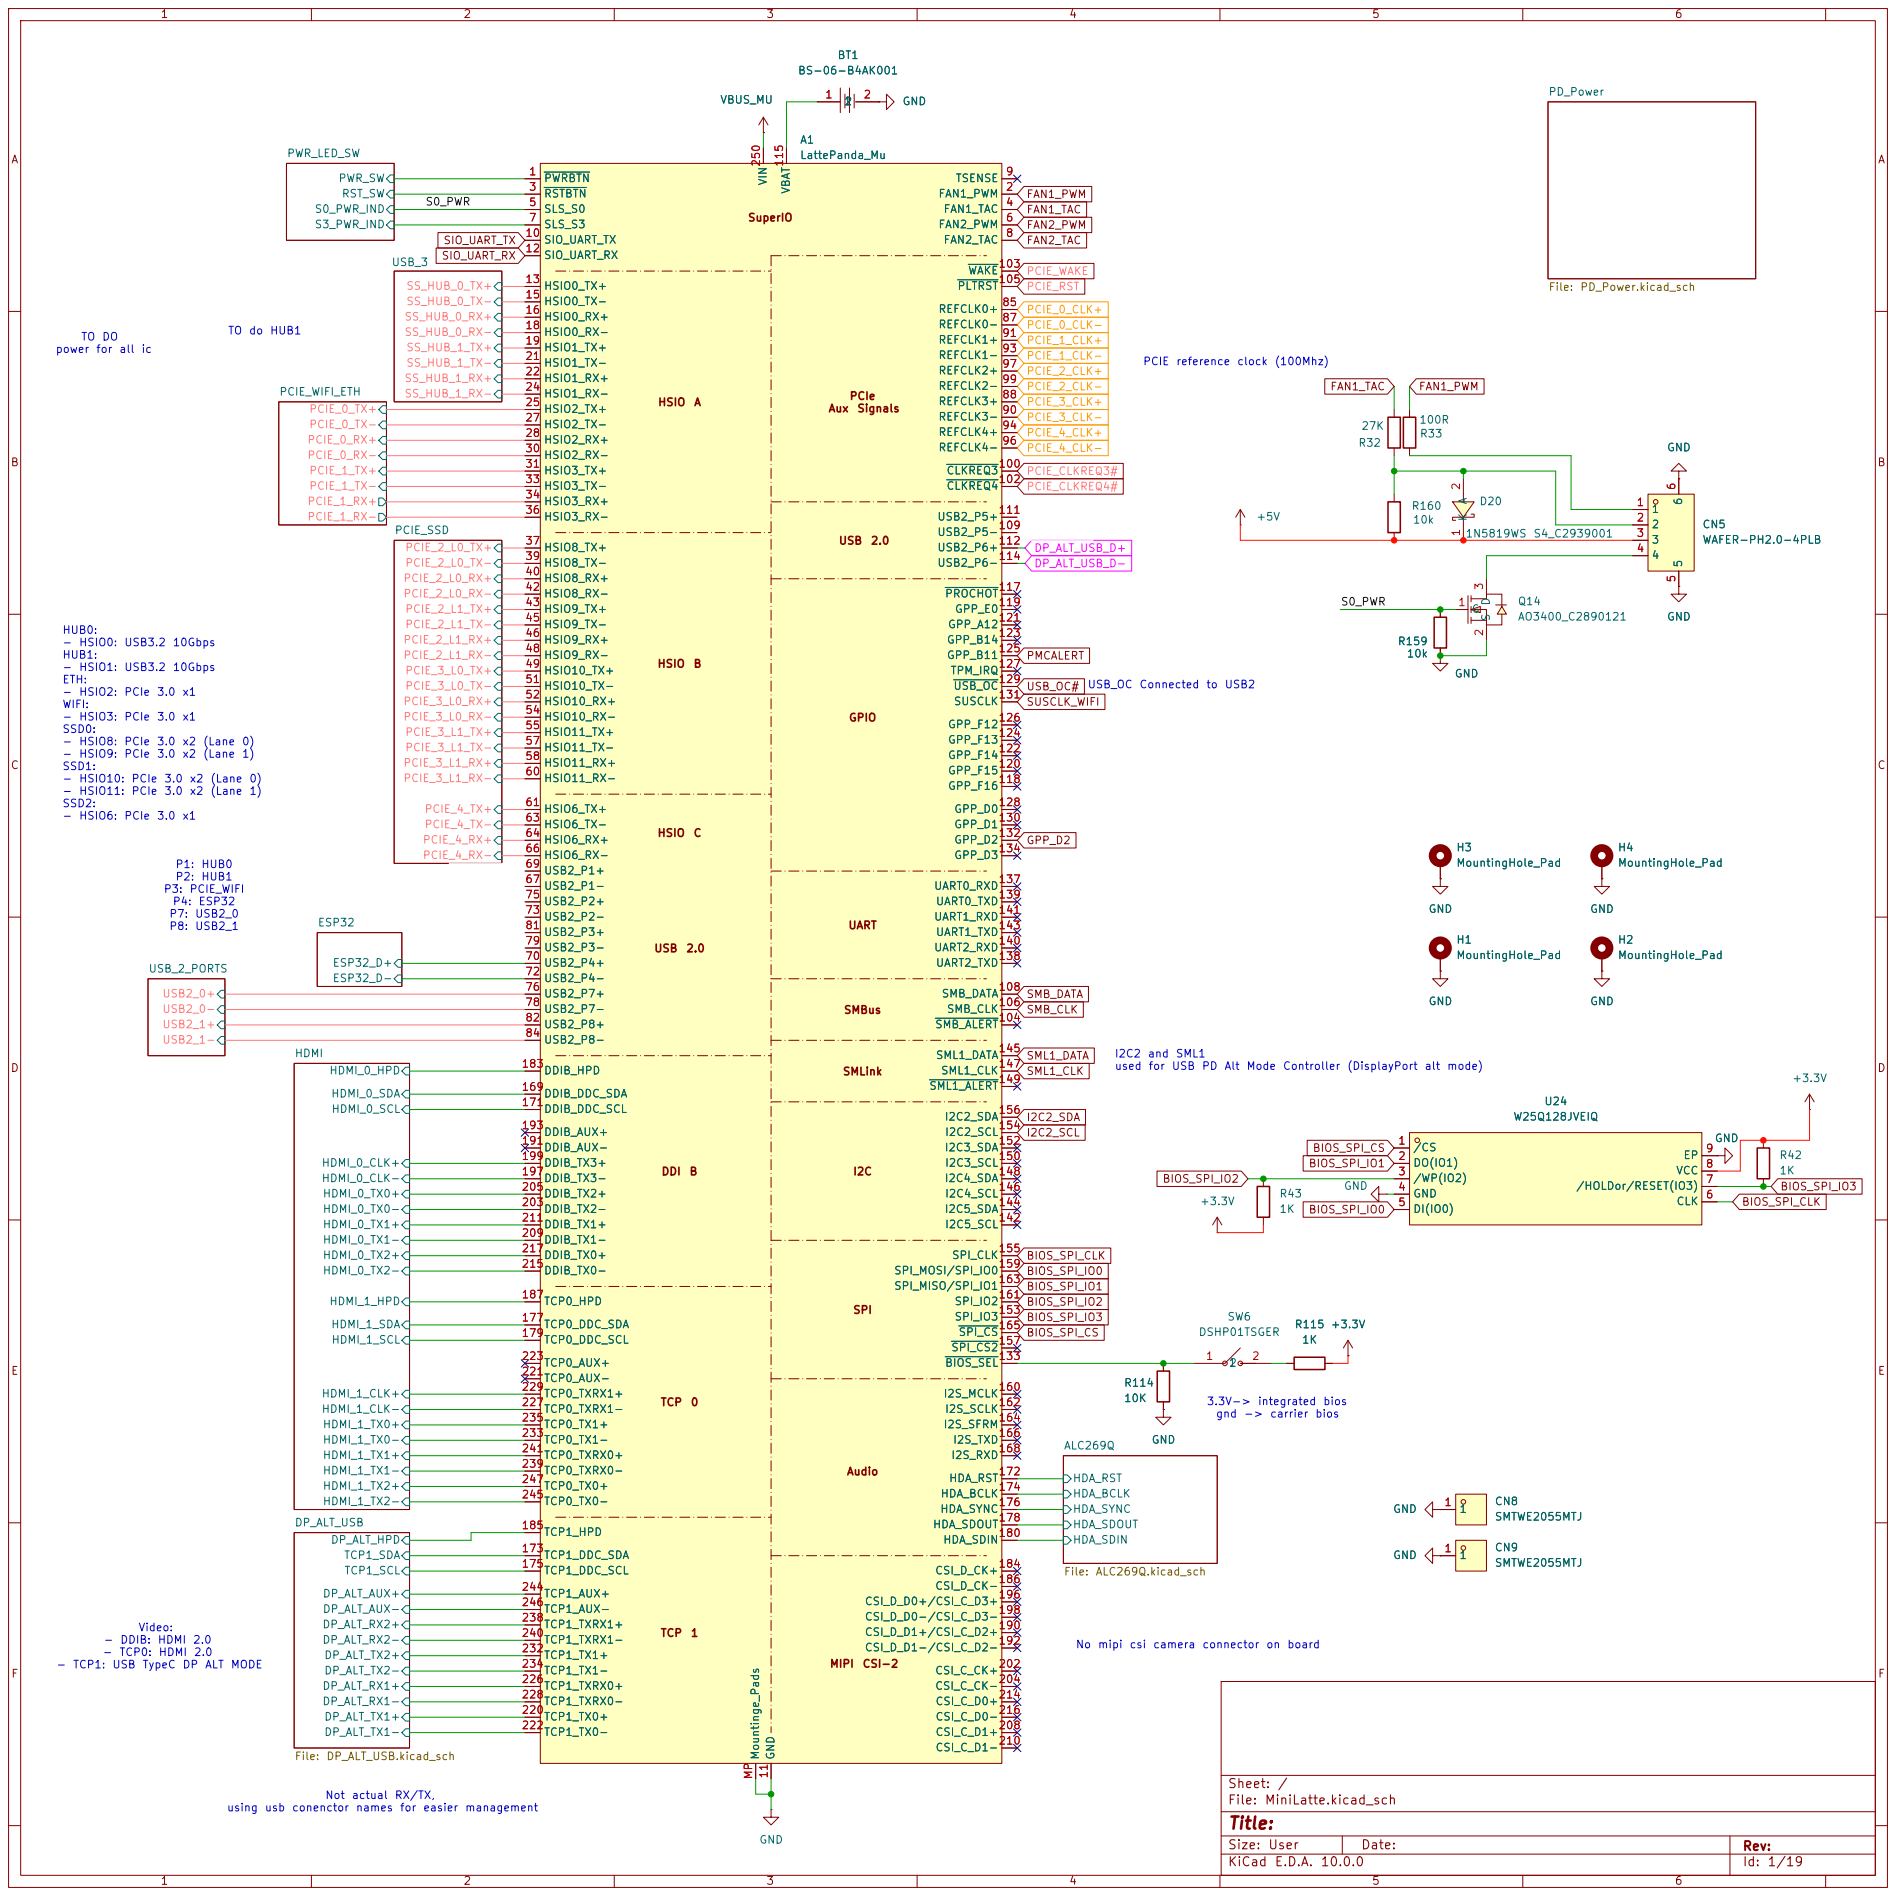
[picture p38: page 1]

TO DO power for all ic

HSIO A HSIO B HSIO C USB 2.0 DDI B

USB_OC Connected to USB2 HUB0: - HSIO0: USB3.2 10Gbps HUB1: - HSIO1: USB3.2 10Gbps ETH: - HSIO2: PCIe 3.0 x1 WIFI: - HSIO3: PCIe 3.0 x1 SSD0: - HSIO8: PCIe 3.0 x2 (Lane 0) - HSIO9: PCIe 3.0 x2 (Lane 1) SSD1: - HSIO10: PCIe 3.0 x2 (Lane 0) - HSIO11: PCIe 3.0 x2 (Lane 1) SSD2: - HSIO6: PCIe 3.0 x1 P1: HUB0 P2: HUB1 P3: PCIE_WIFI P4: ESP32 P7: USB2_0 P8: USB2_1

I2C2 and SML1
used for USB PD Alt Mode Controller (DisplayPort alt mode)

3.3V-> integrated bios gnd -> carrier bios

Video: - DDIB: HDMI 2.0 - TCP0: HDMI 2.0 - TCP1: USB TypeC DP ALT MODE

No mipi csi camera connector on board

Not actual RX/TX,

using usb conenctor names for easier management

Size: User | Rev:
KiCad E.D.A. 10.0.0 | Id: 1/19

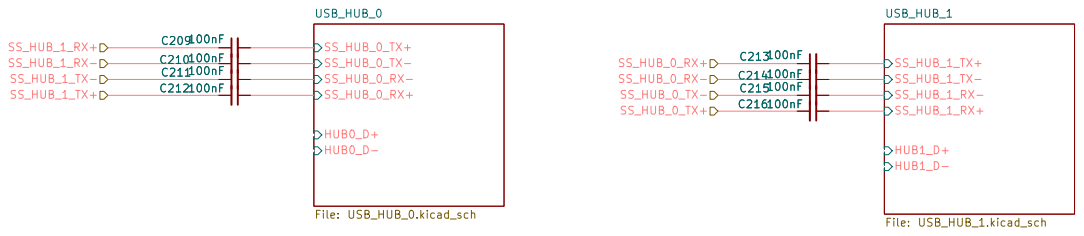
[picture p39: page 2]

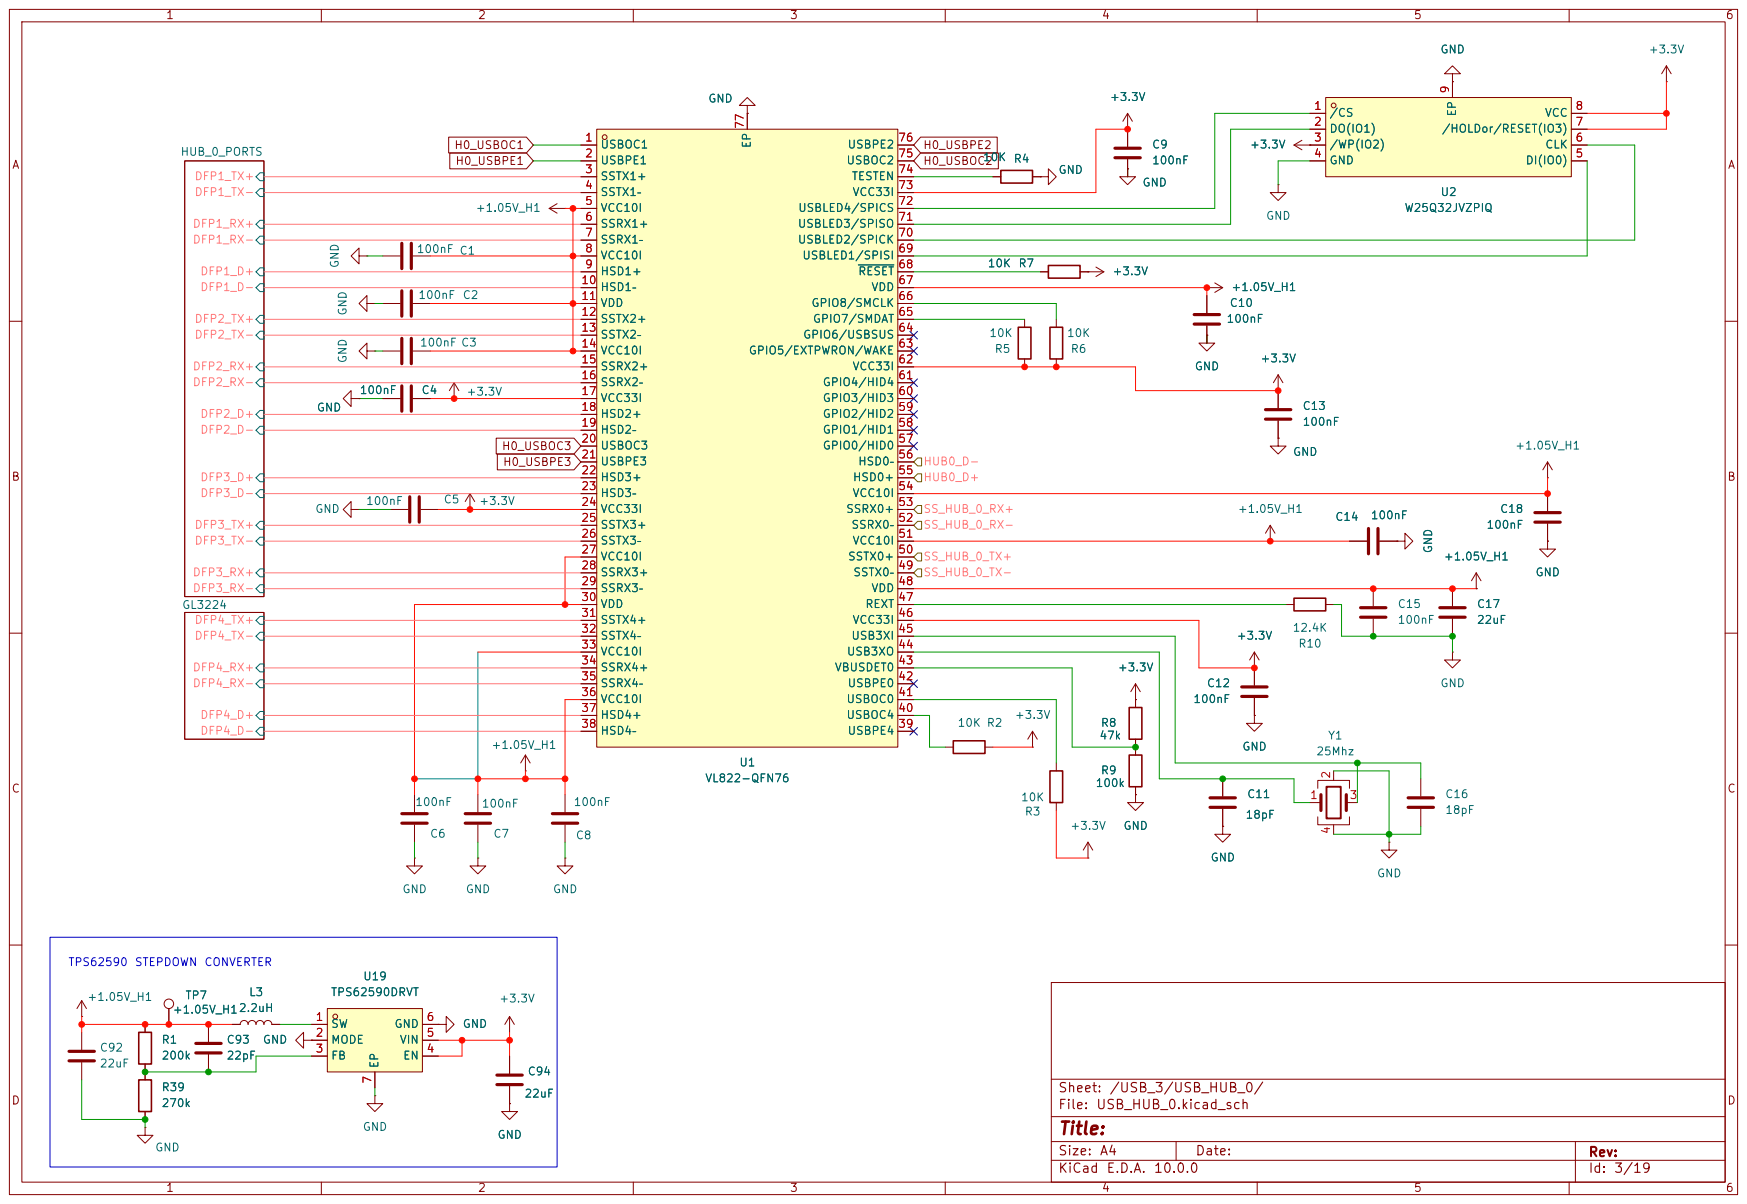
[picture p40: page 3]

VCC10I 5 VCC10I 5 SSRX1+ 6 SSRX1+ 6

SSRX1– 7
VCC10I 8 HSD1+ 9 HSD1– 10

100nF C2 | VDD 11 VDD 11 SSTX2+ 12 SSTX2+ 12

SSTX2– 13
VCC10I 14 VCC10I 14 SSRX2+ 15 SSRX2+ 15

VCC10I 33

SSRX4– 35

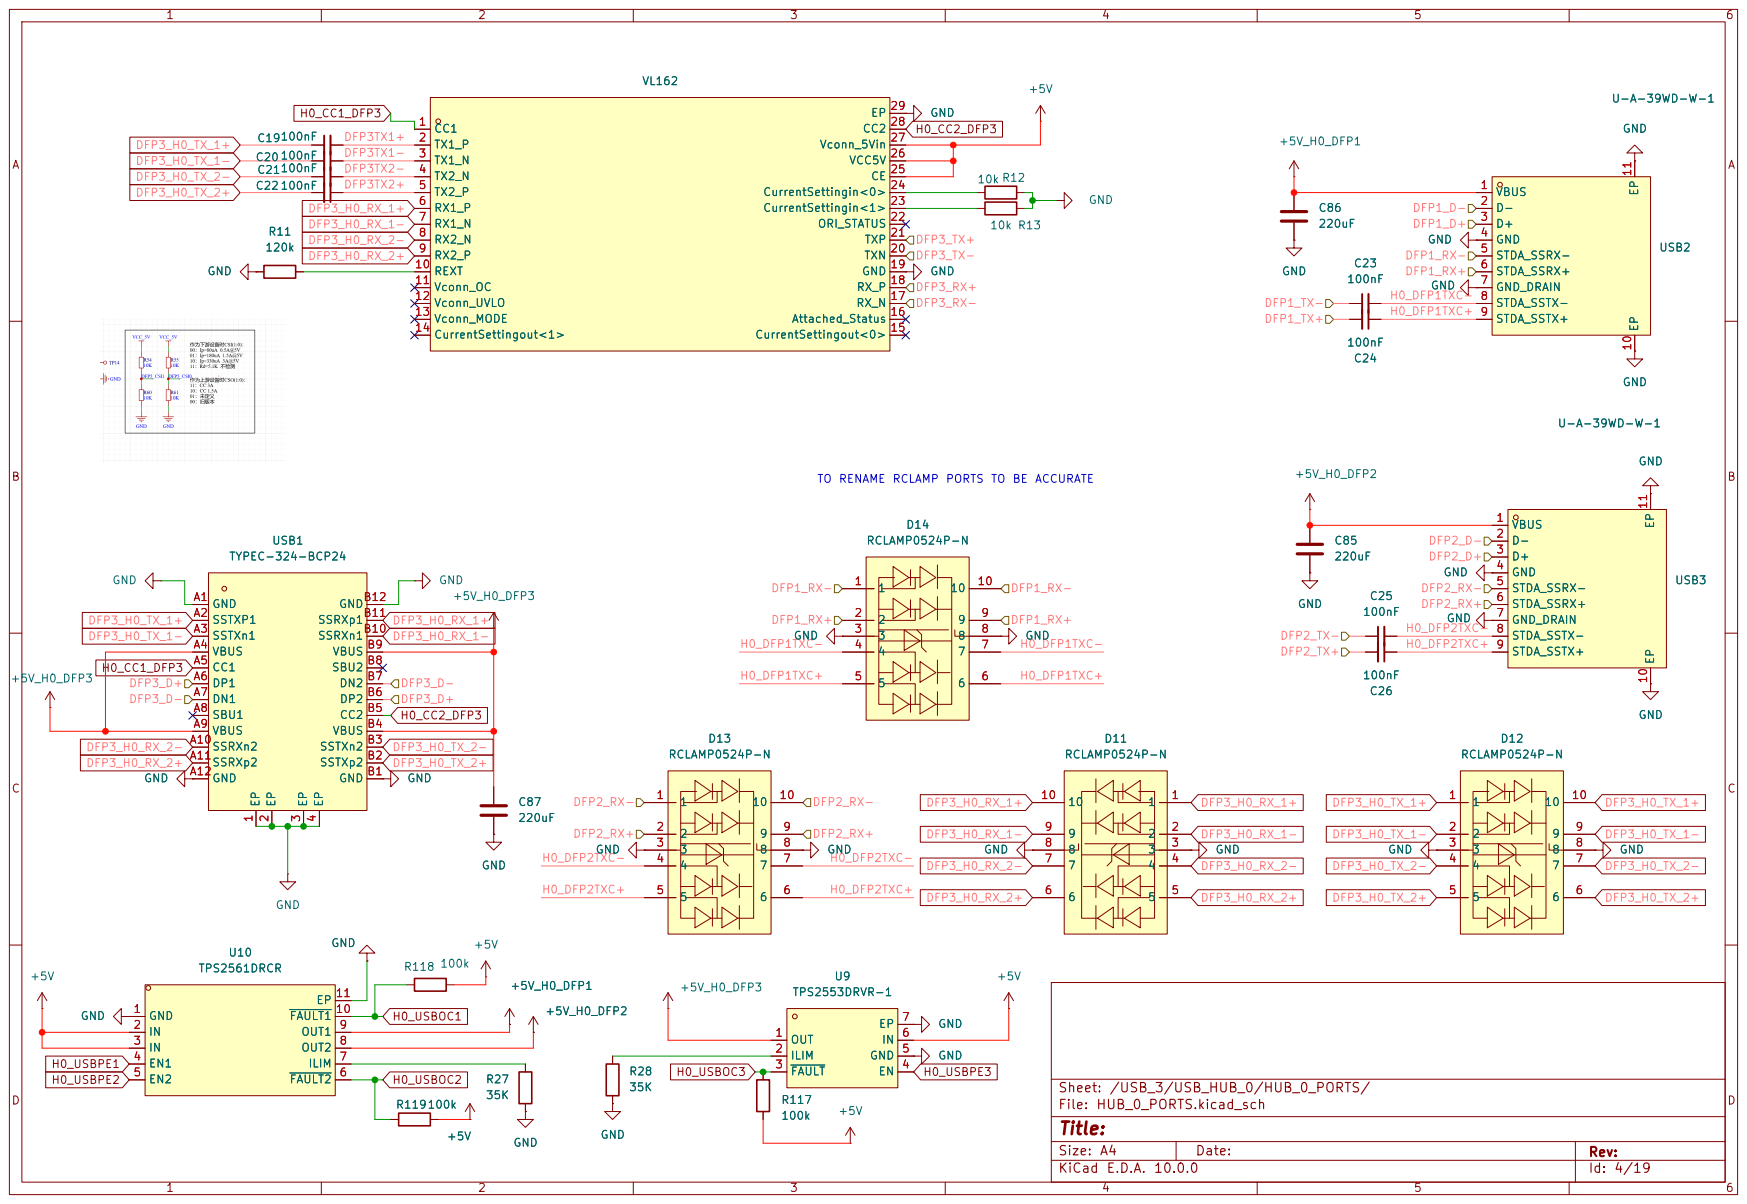
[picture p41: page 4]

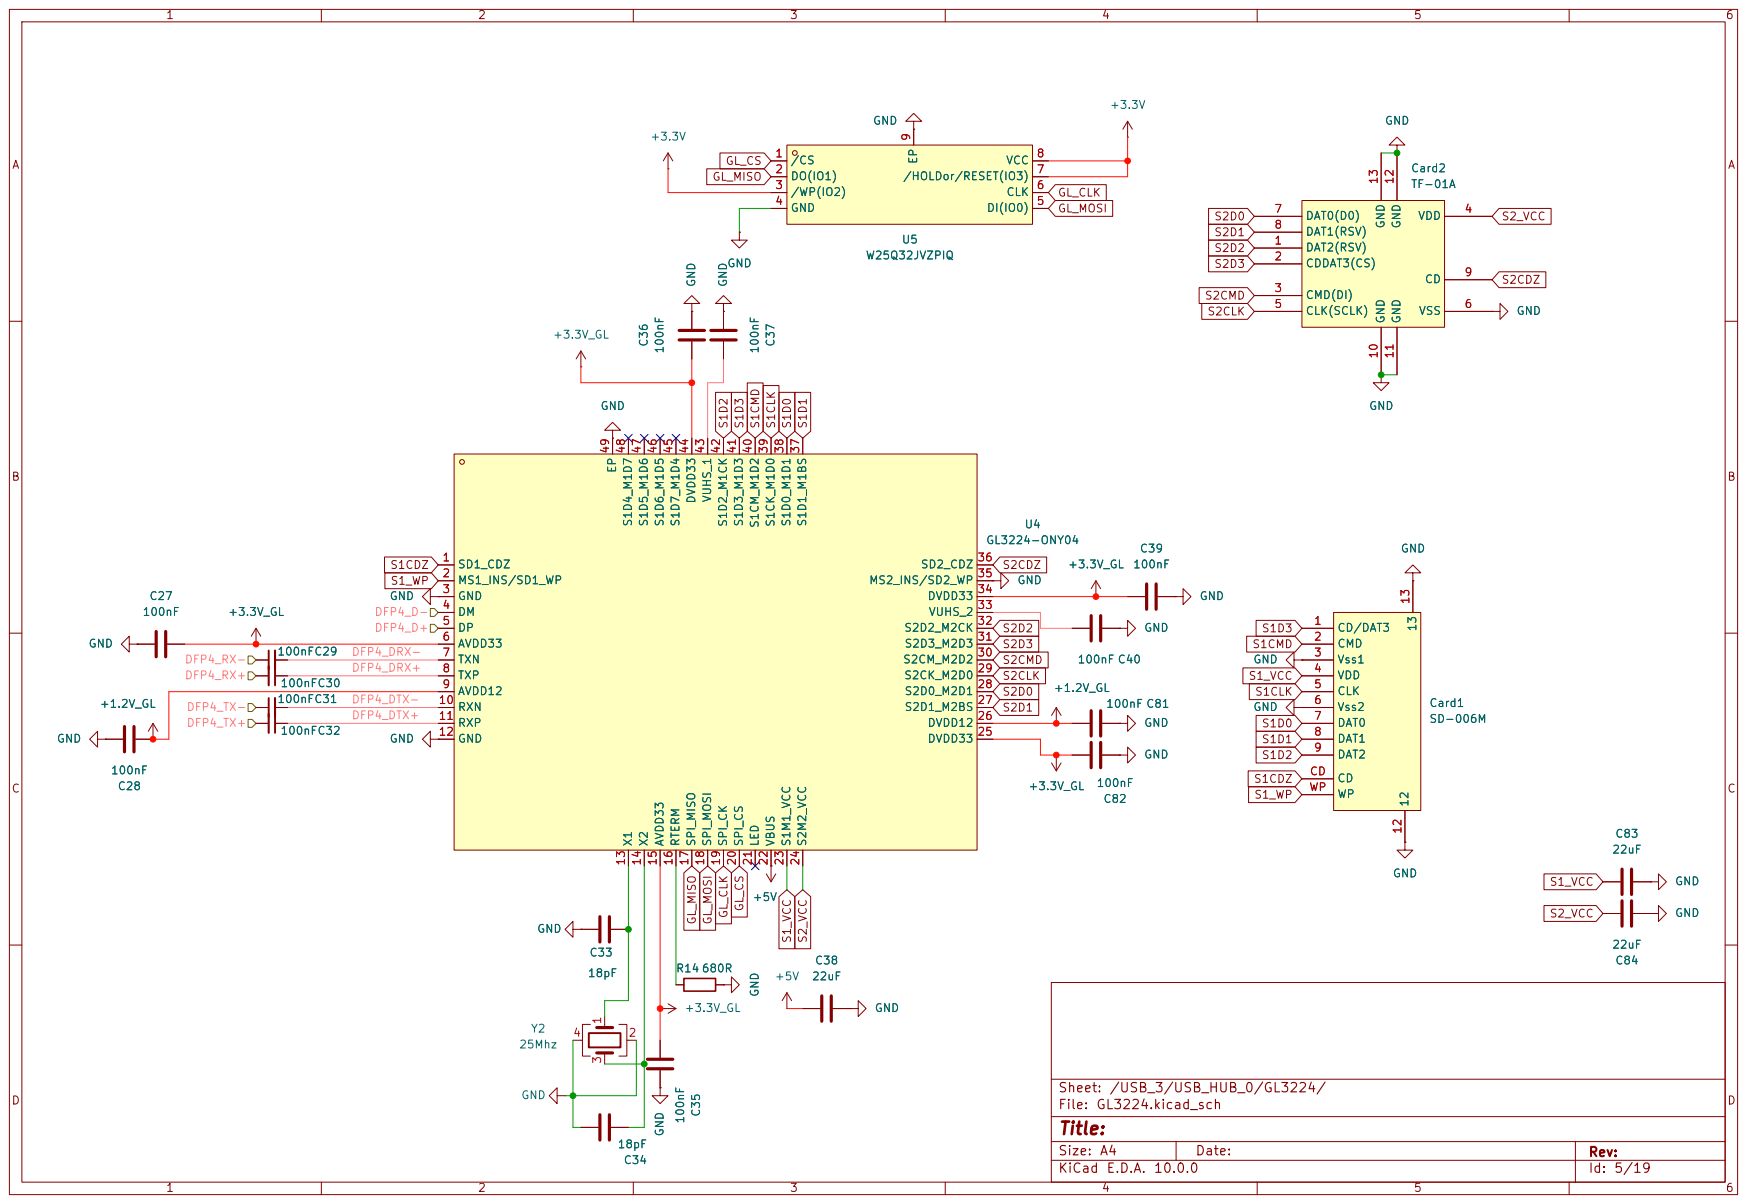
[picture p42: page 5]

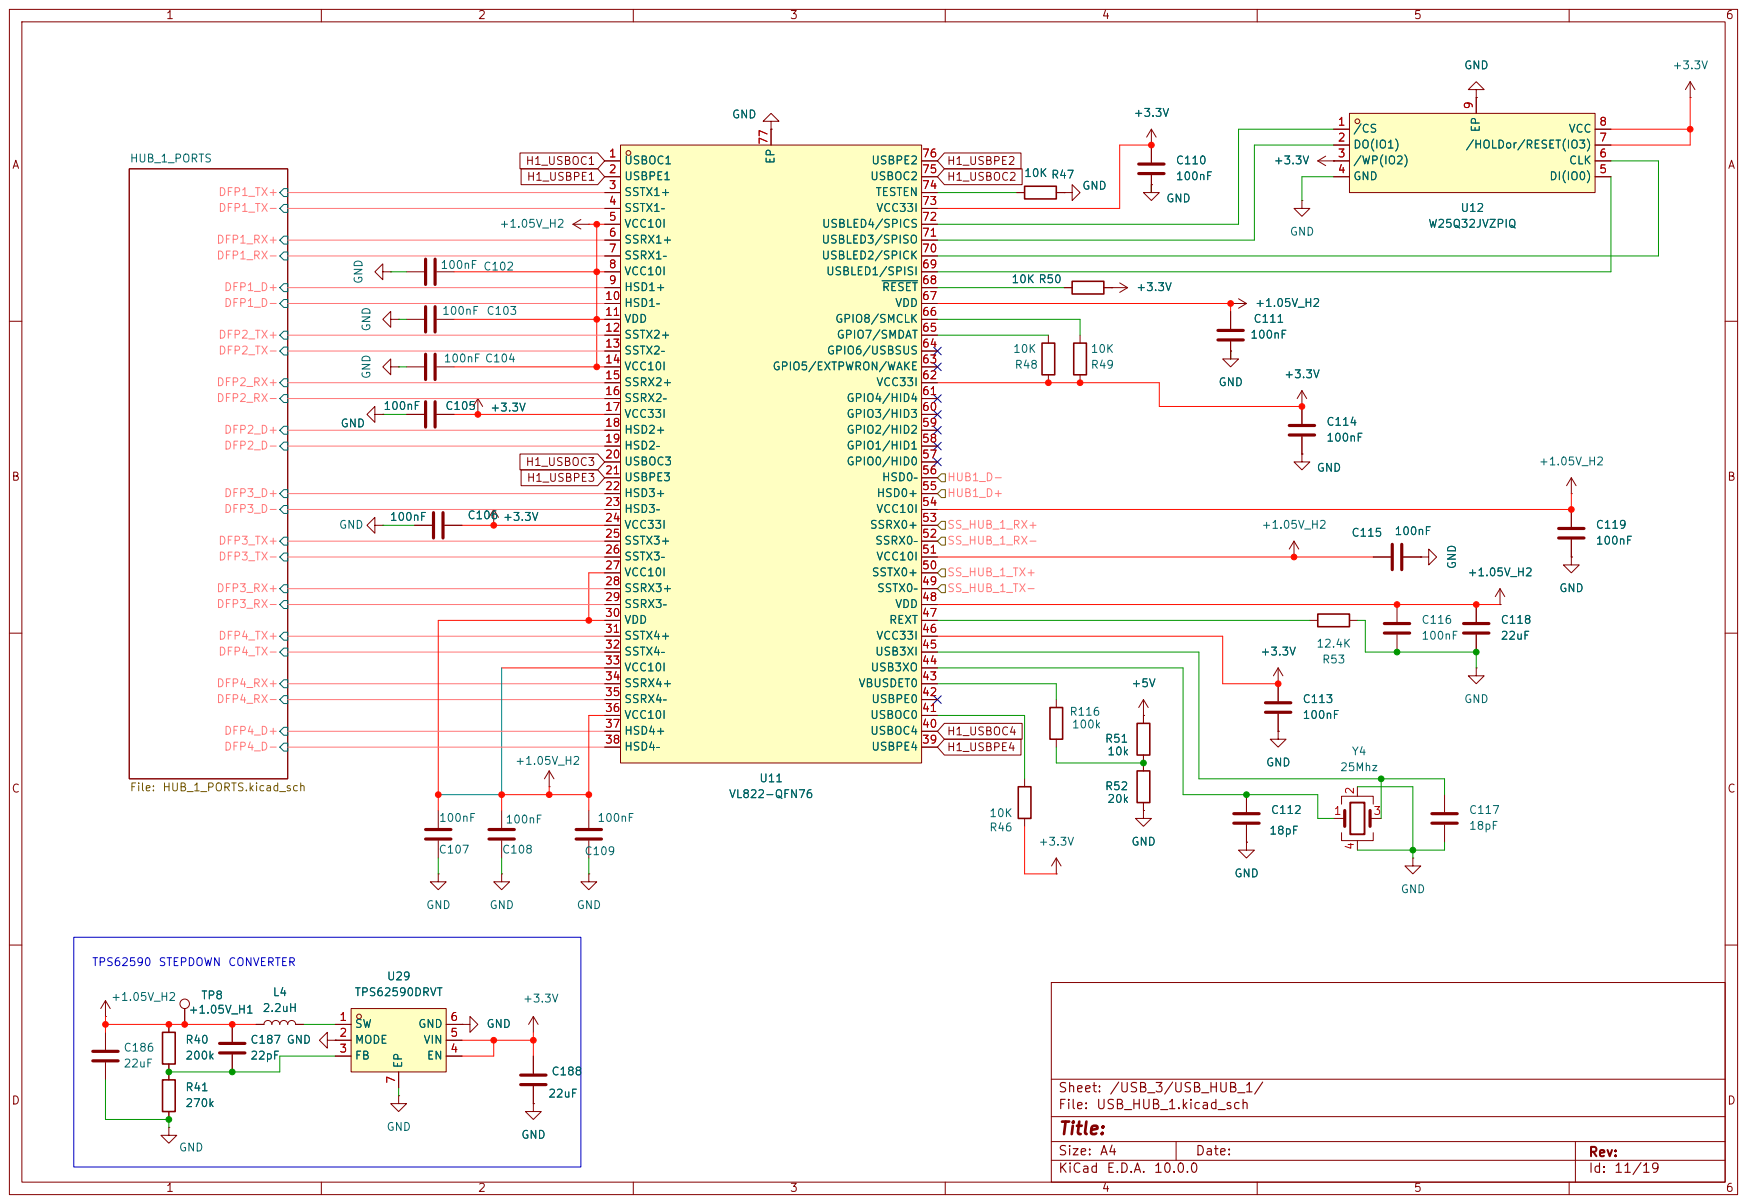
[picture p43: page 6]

VCC10I 8 HSD1+ 9 HSD1– 10

VDD 11 VDD 11 SSTX2+ 12 SSTX2+ 12

SSTX2– 13

100nF C104 GND | VCC10I 14 VCC10I 14 SSRX2+ 15 SSRX2+ 15

VCC10I 27

SSRX3– 29
VDD 30

SSTX4– 32
VCC10I 33

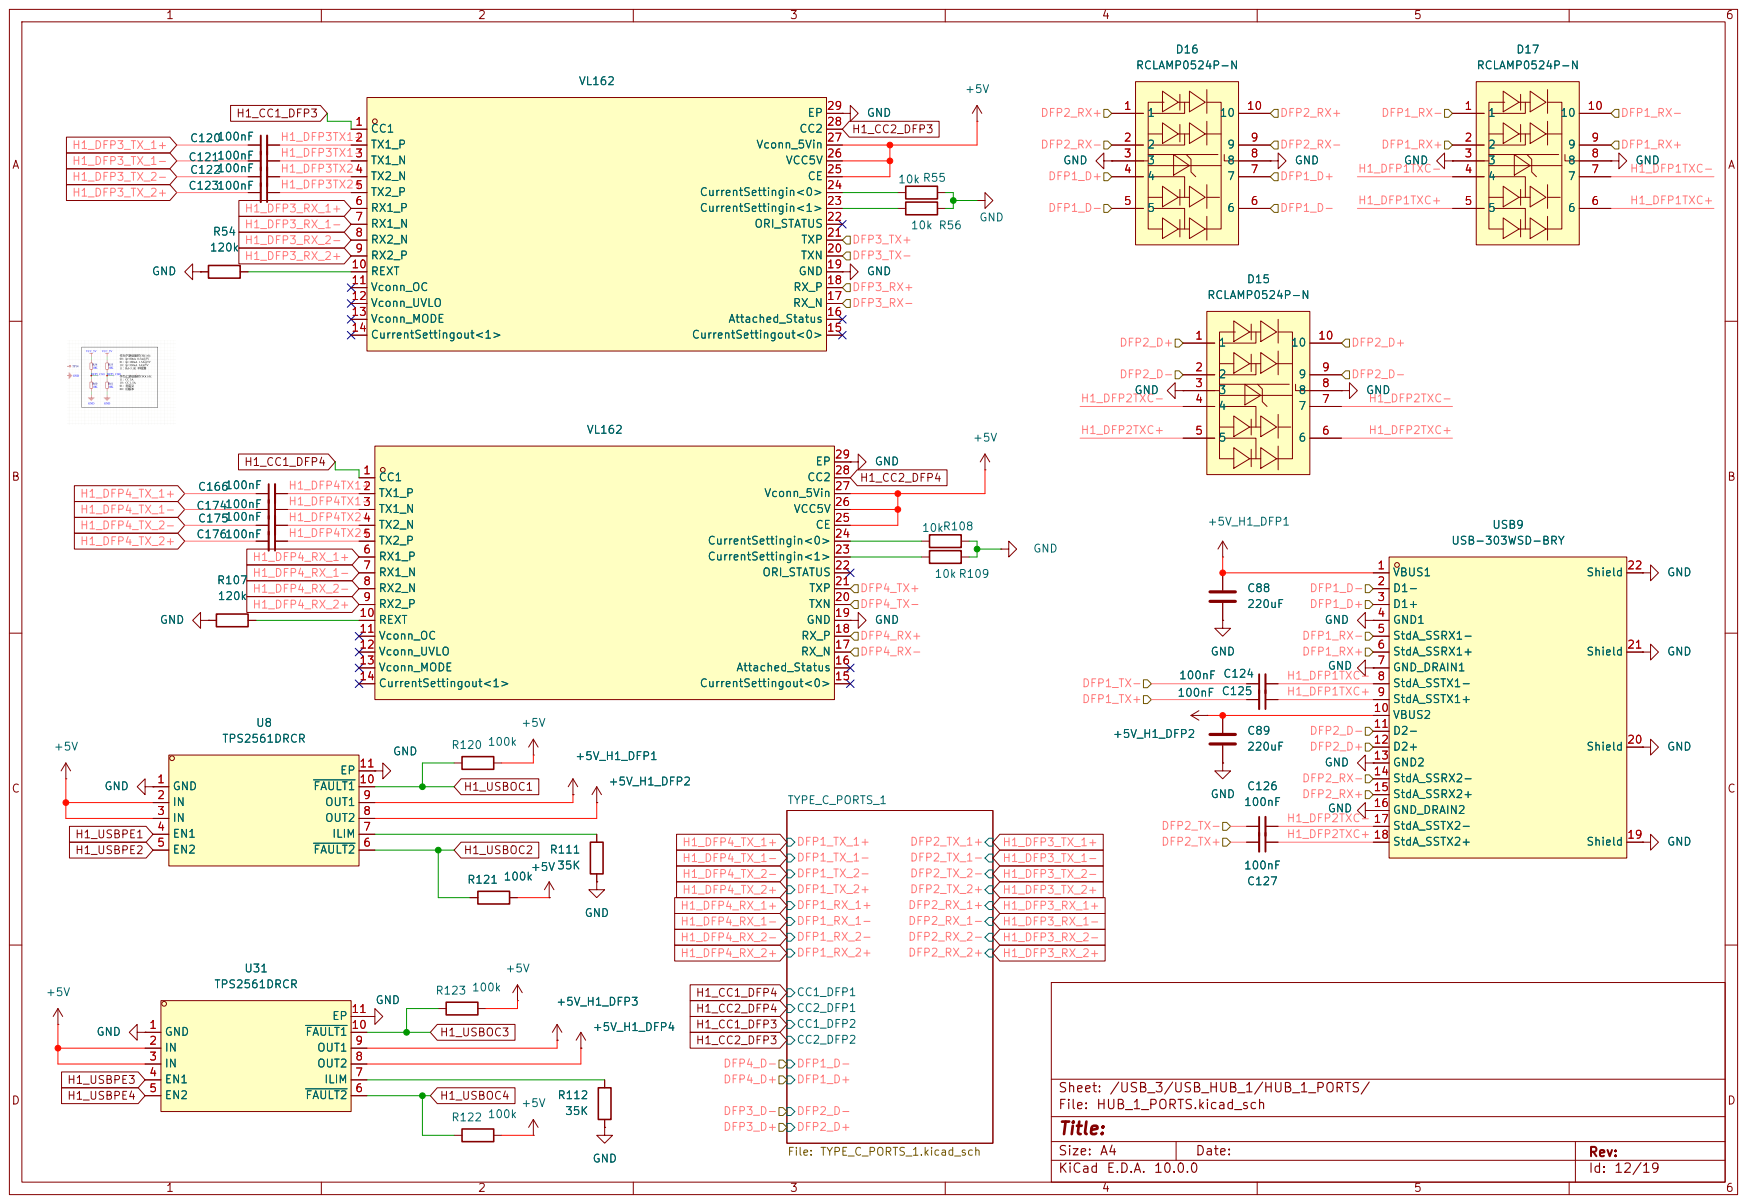
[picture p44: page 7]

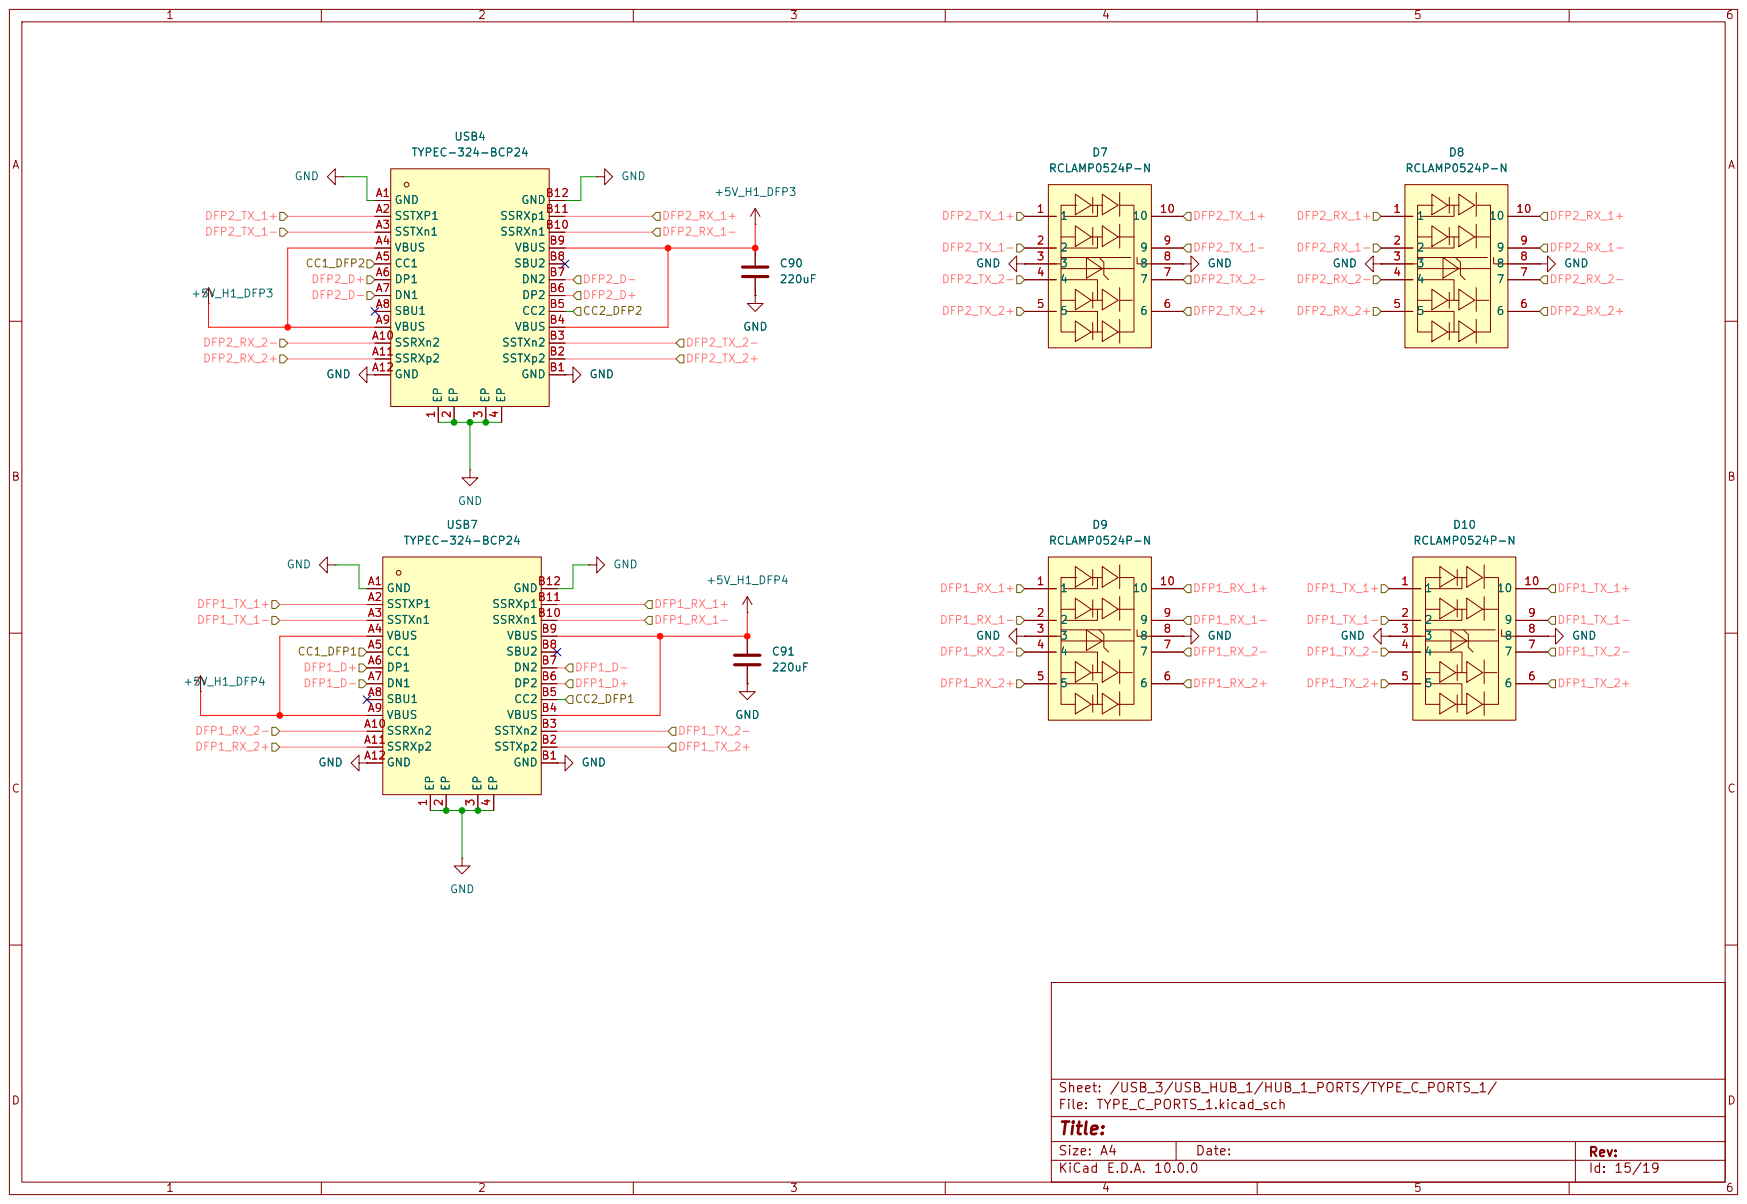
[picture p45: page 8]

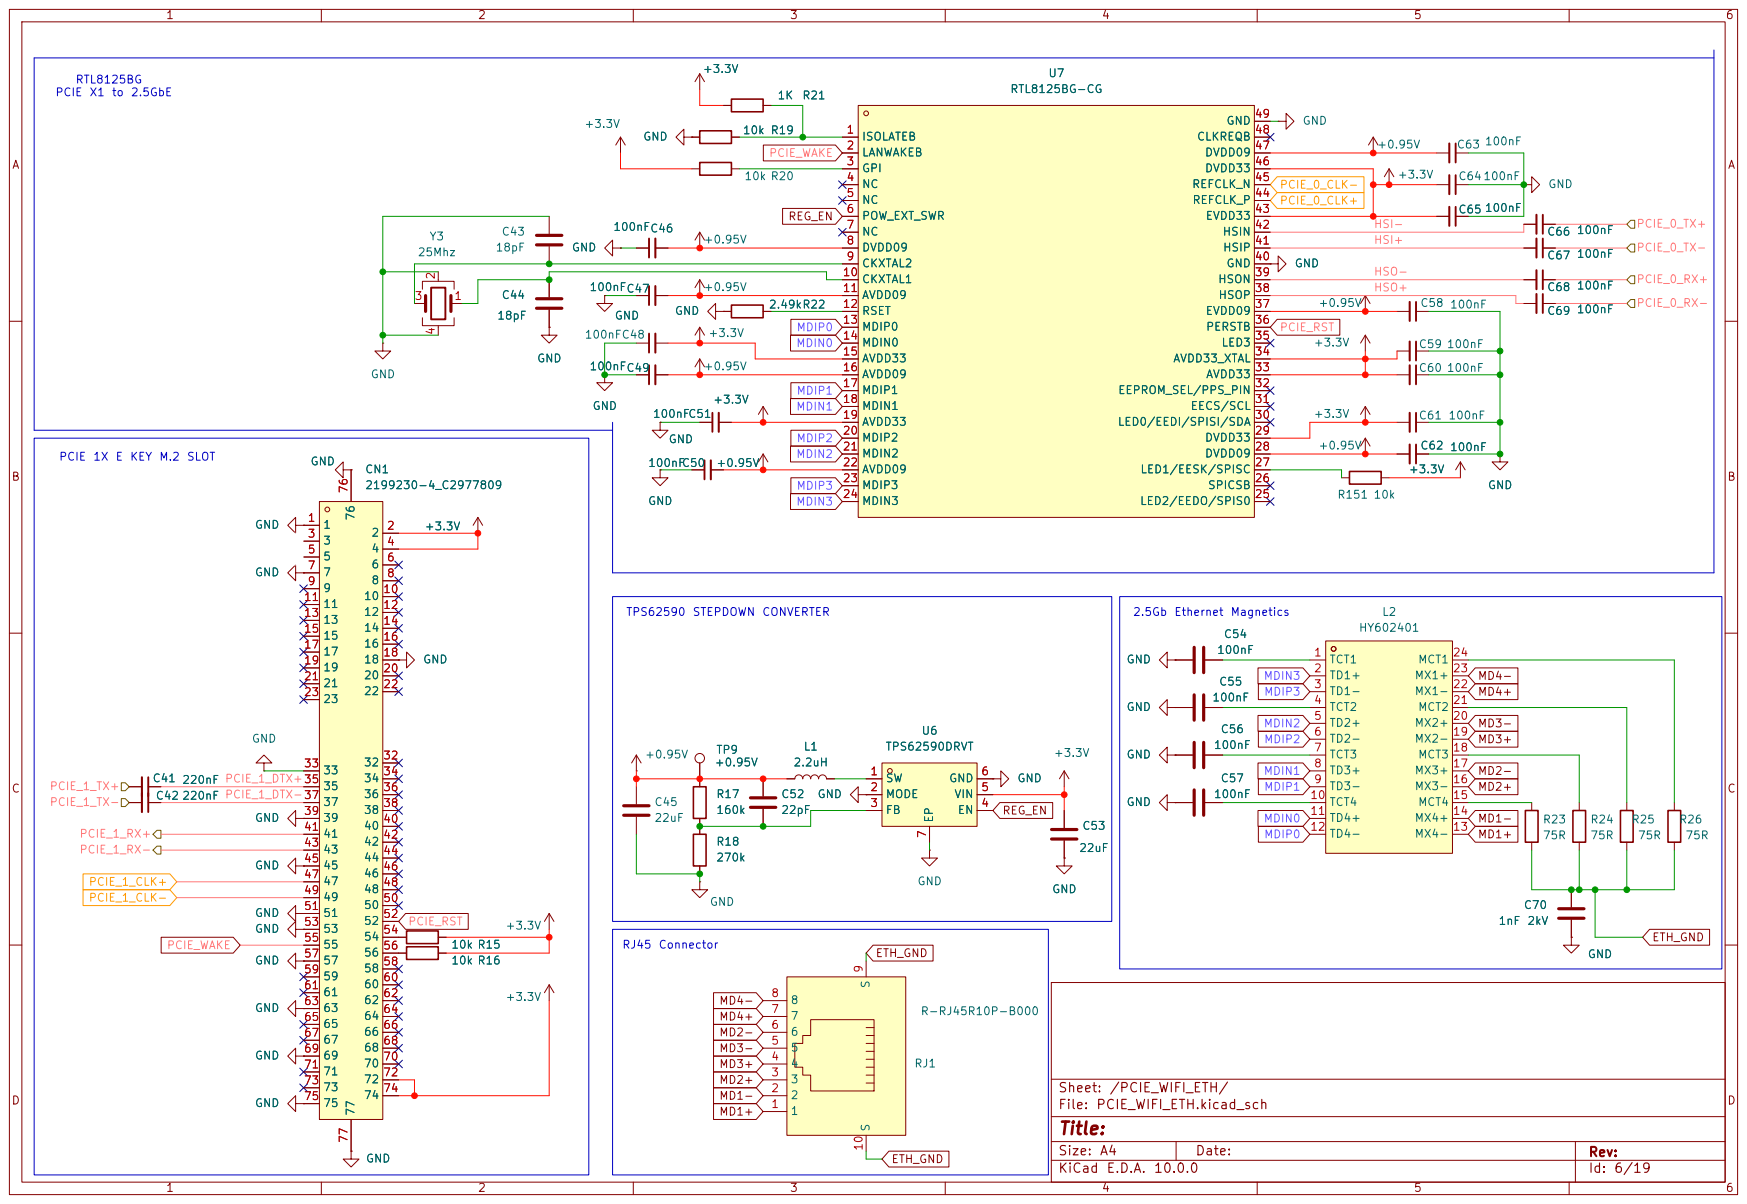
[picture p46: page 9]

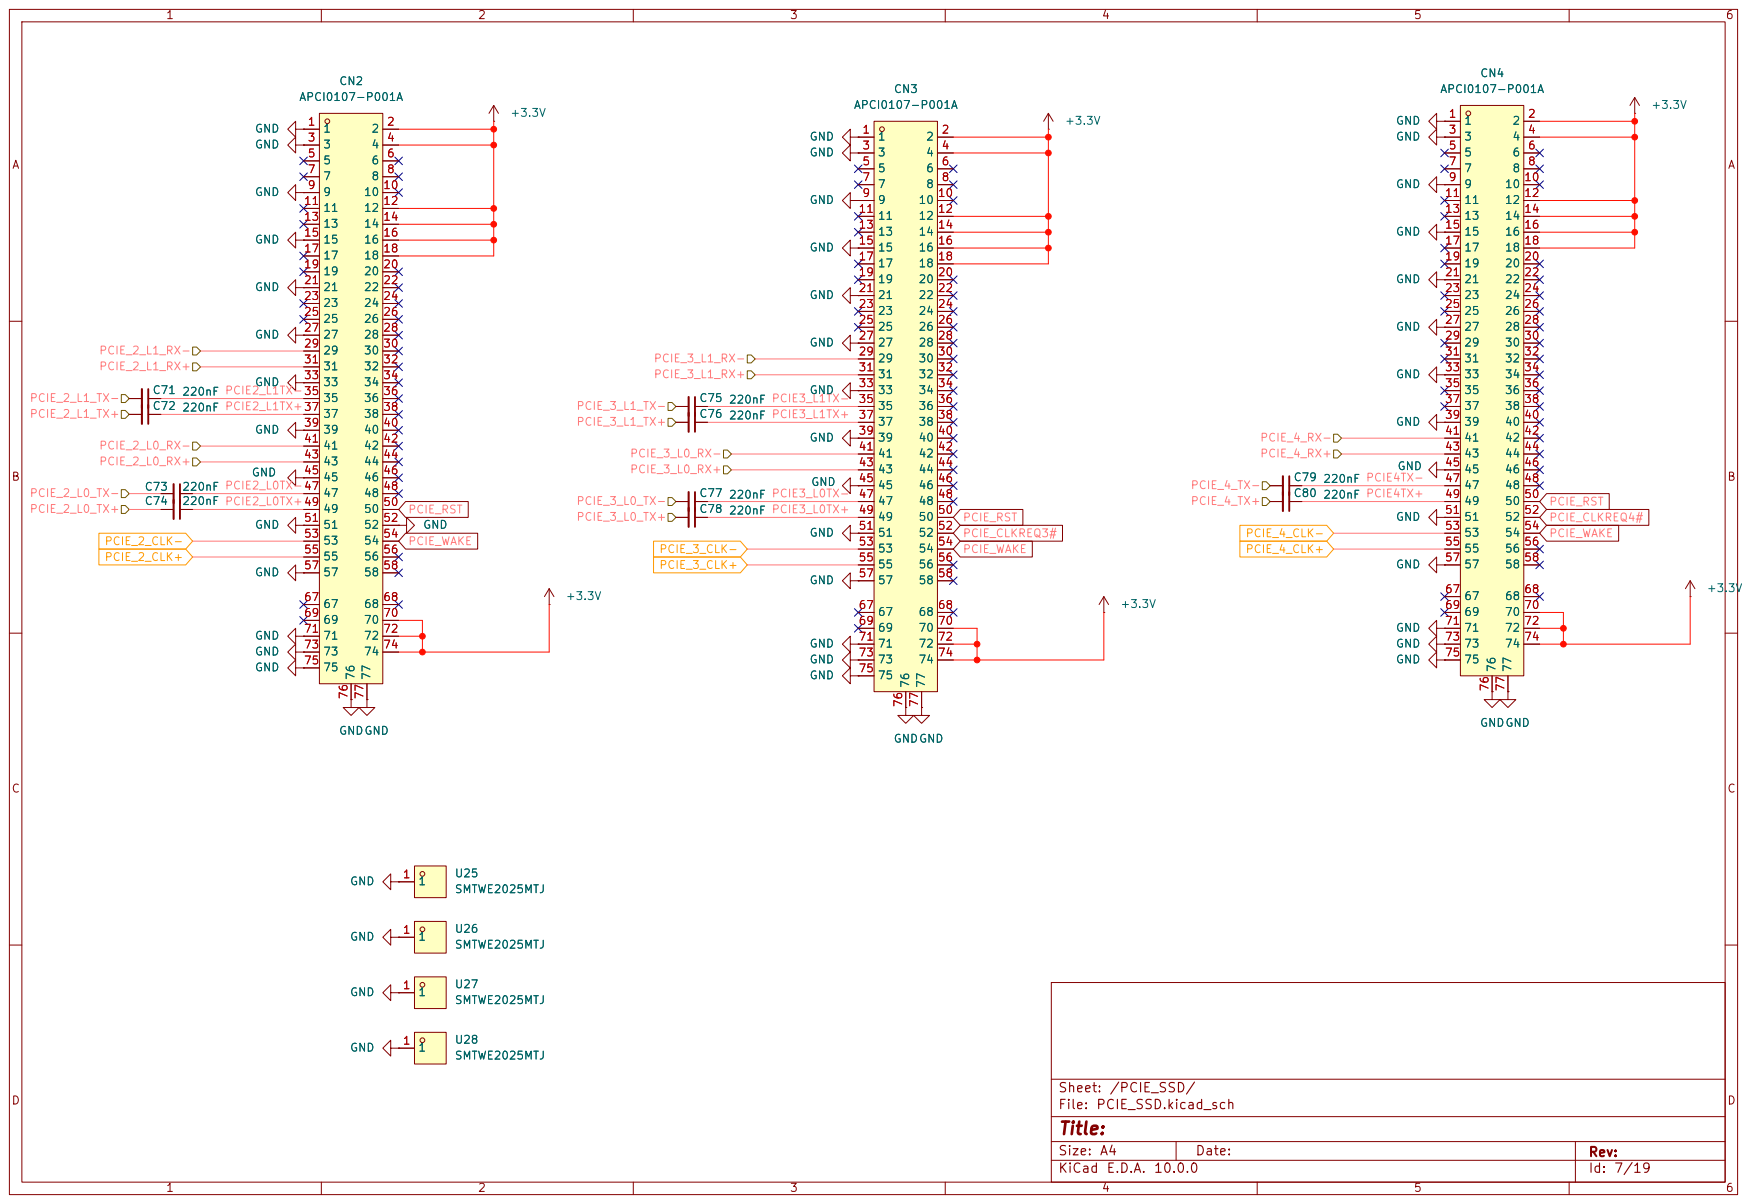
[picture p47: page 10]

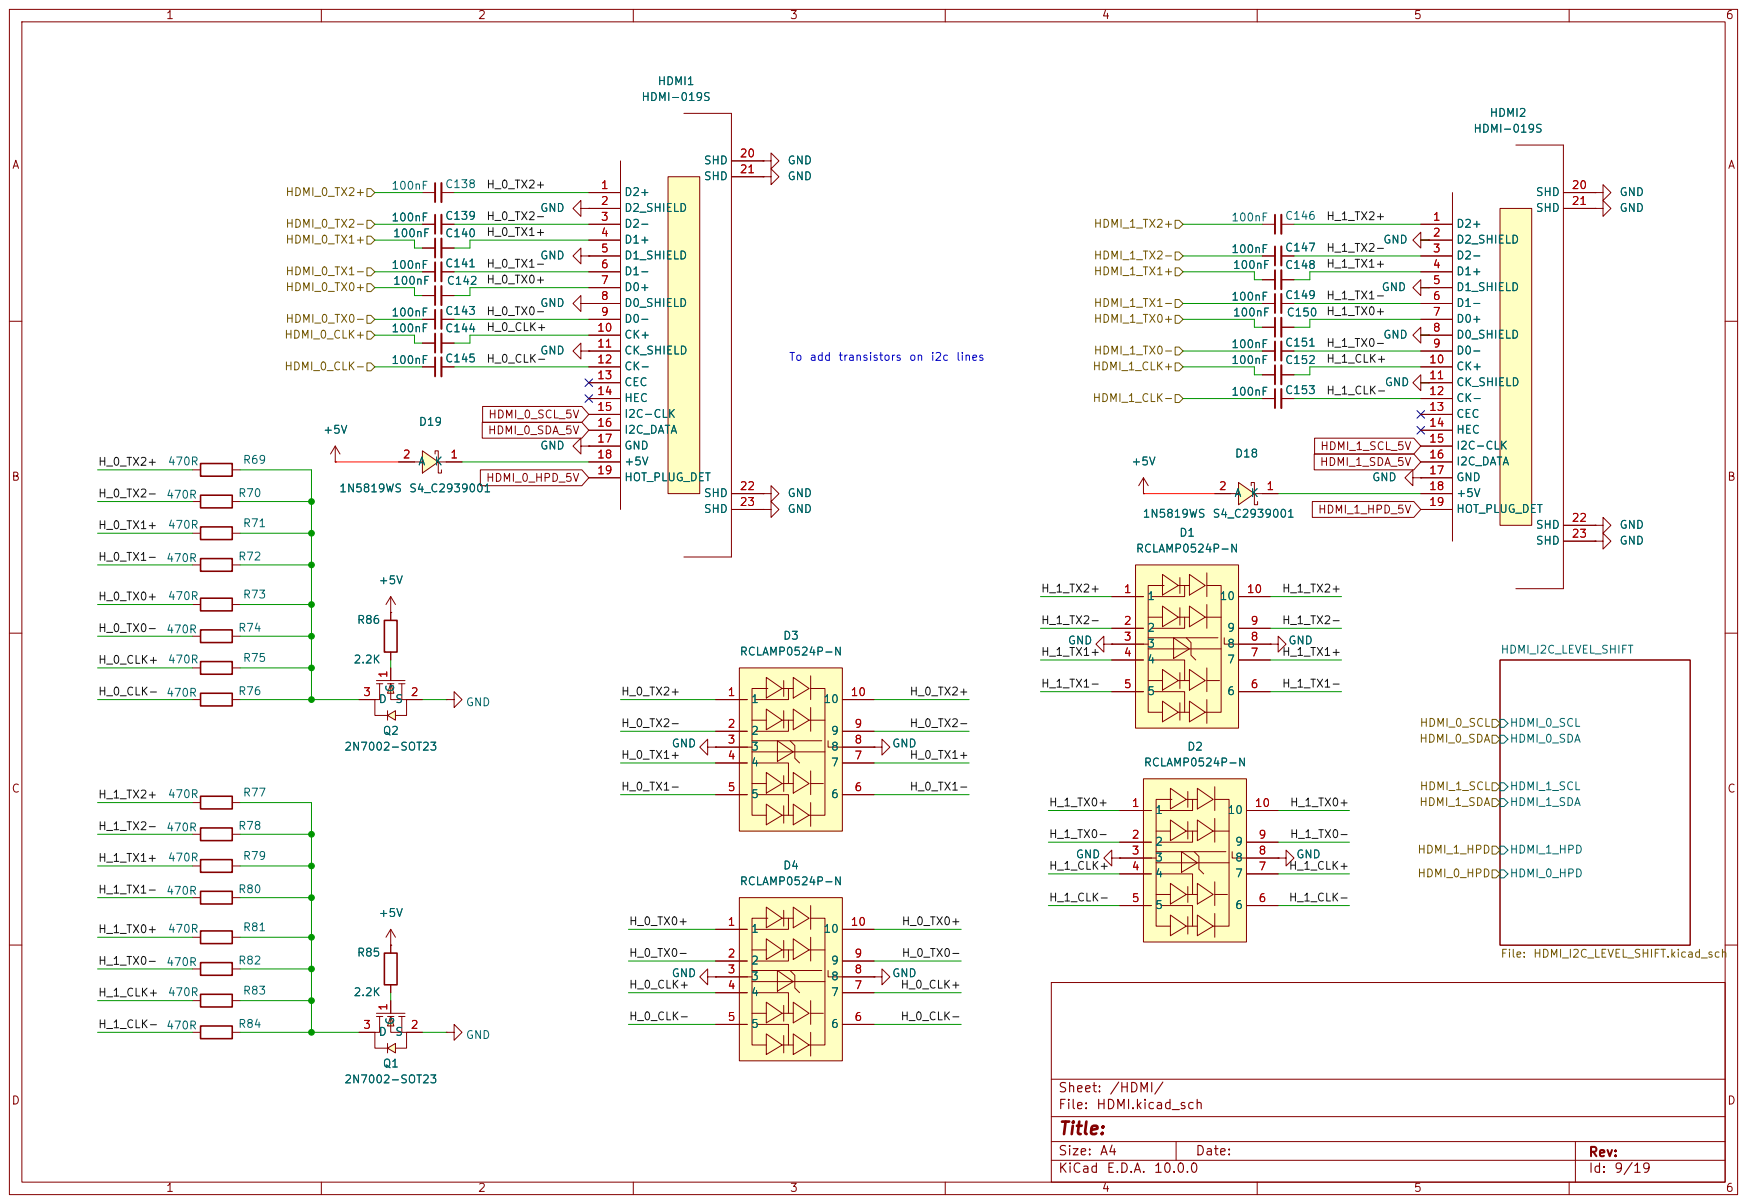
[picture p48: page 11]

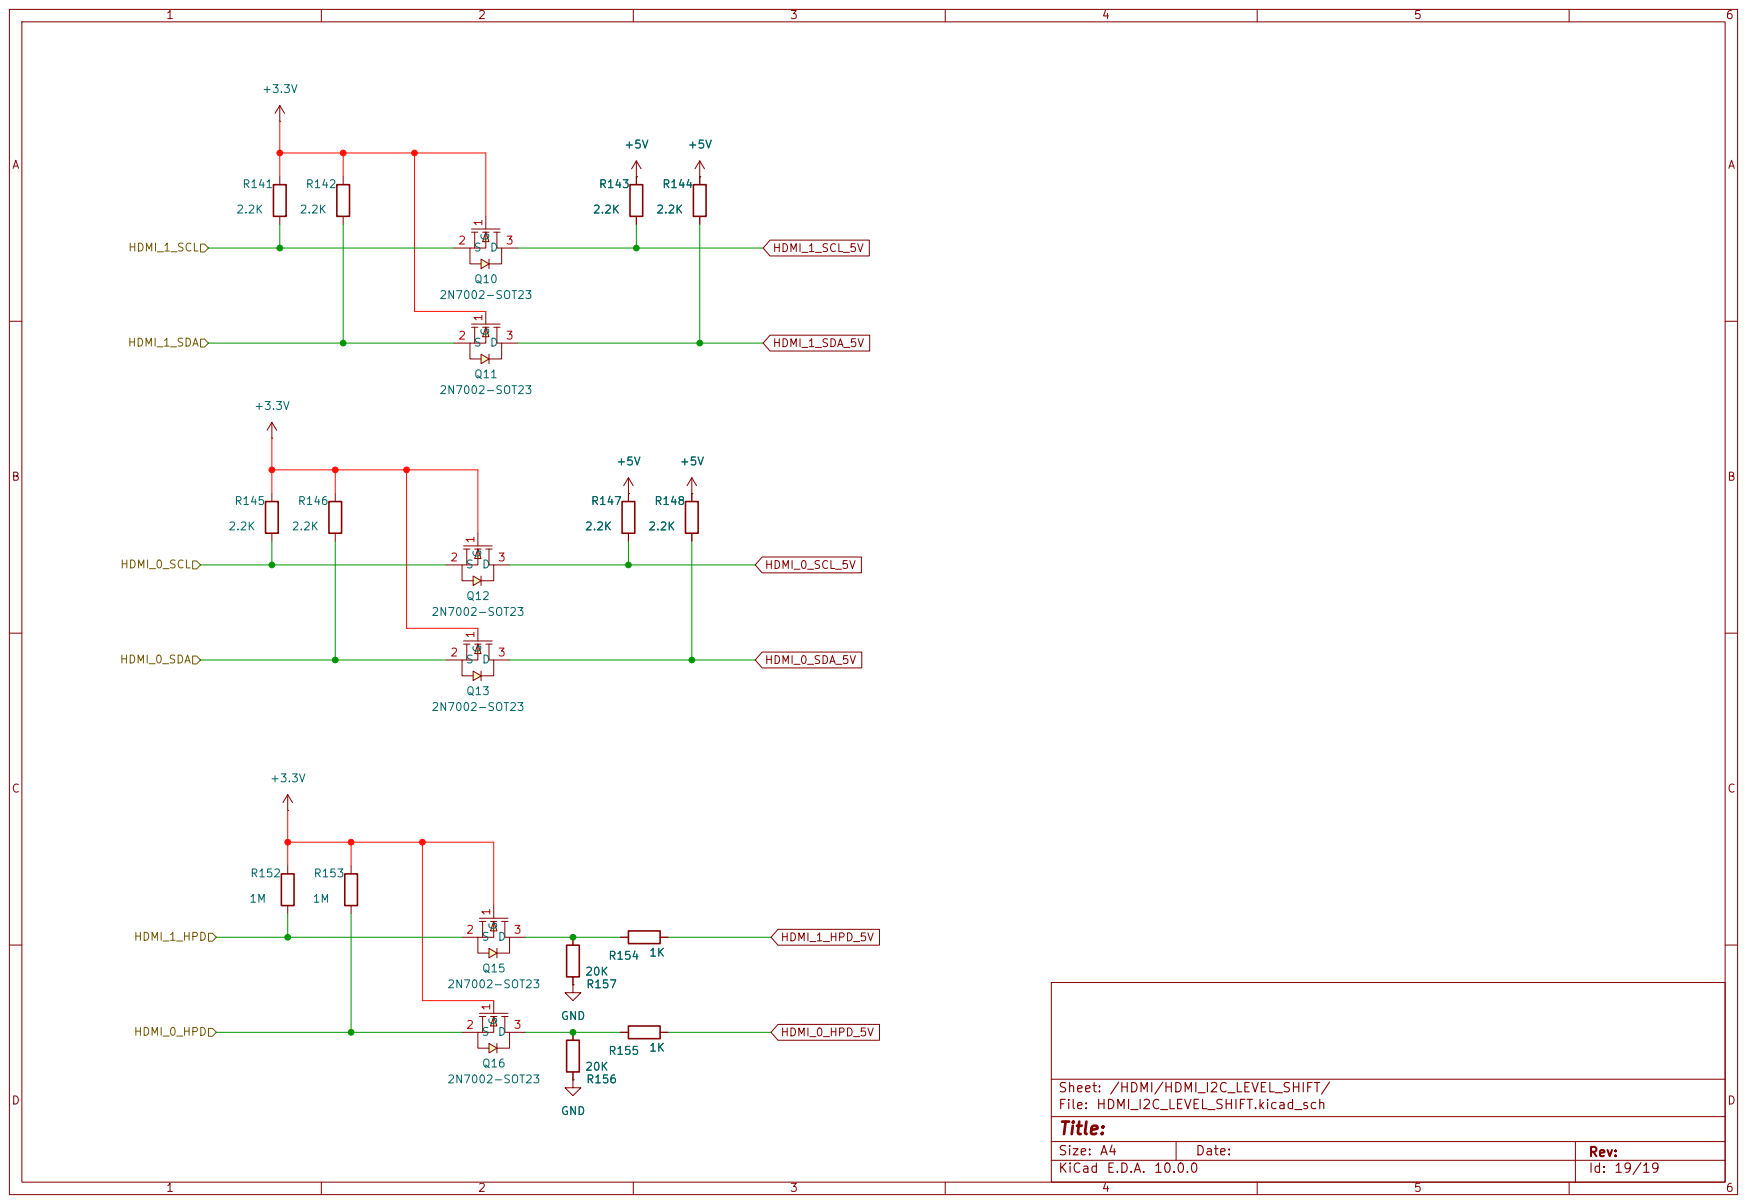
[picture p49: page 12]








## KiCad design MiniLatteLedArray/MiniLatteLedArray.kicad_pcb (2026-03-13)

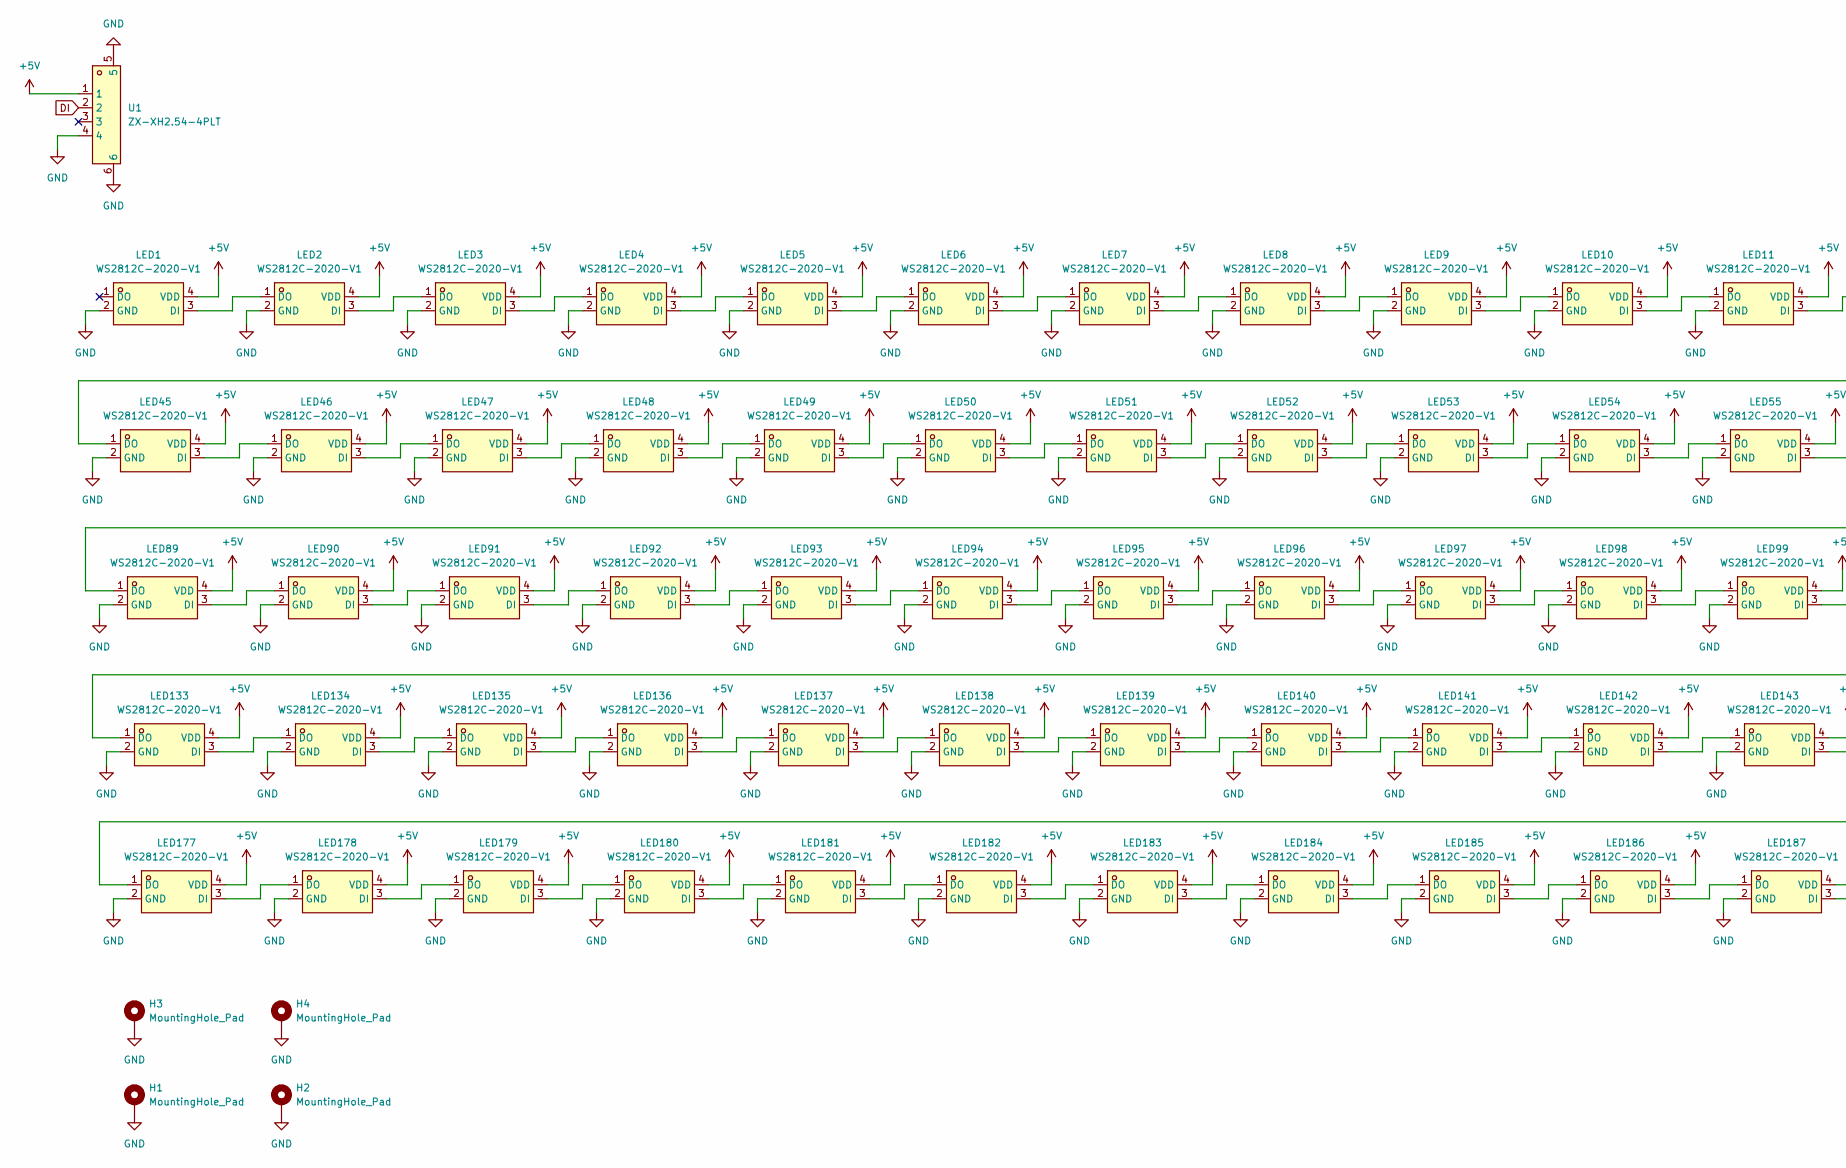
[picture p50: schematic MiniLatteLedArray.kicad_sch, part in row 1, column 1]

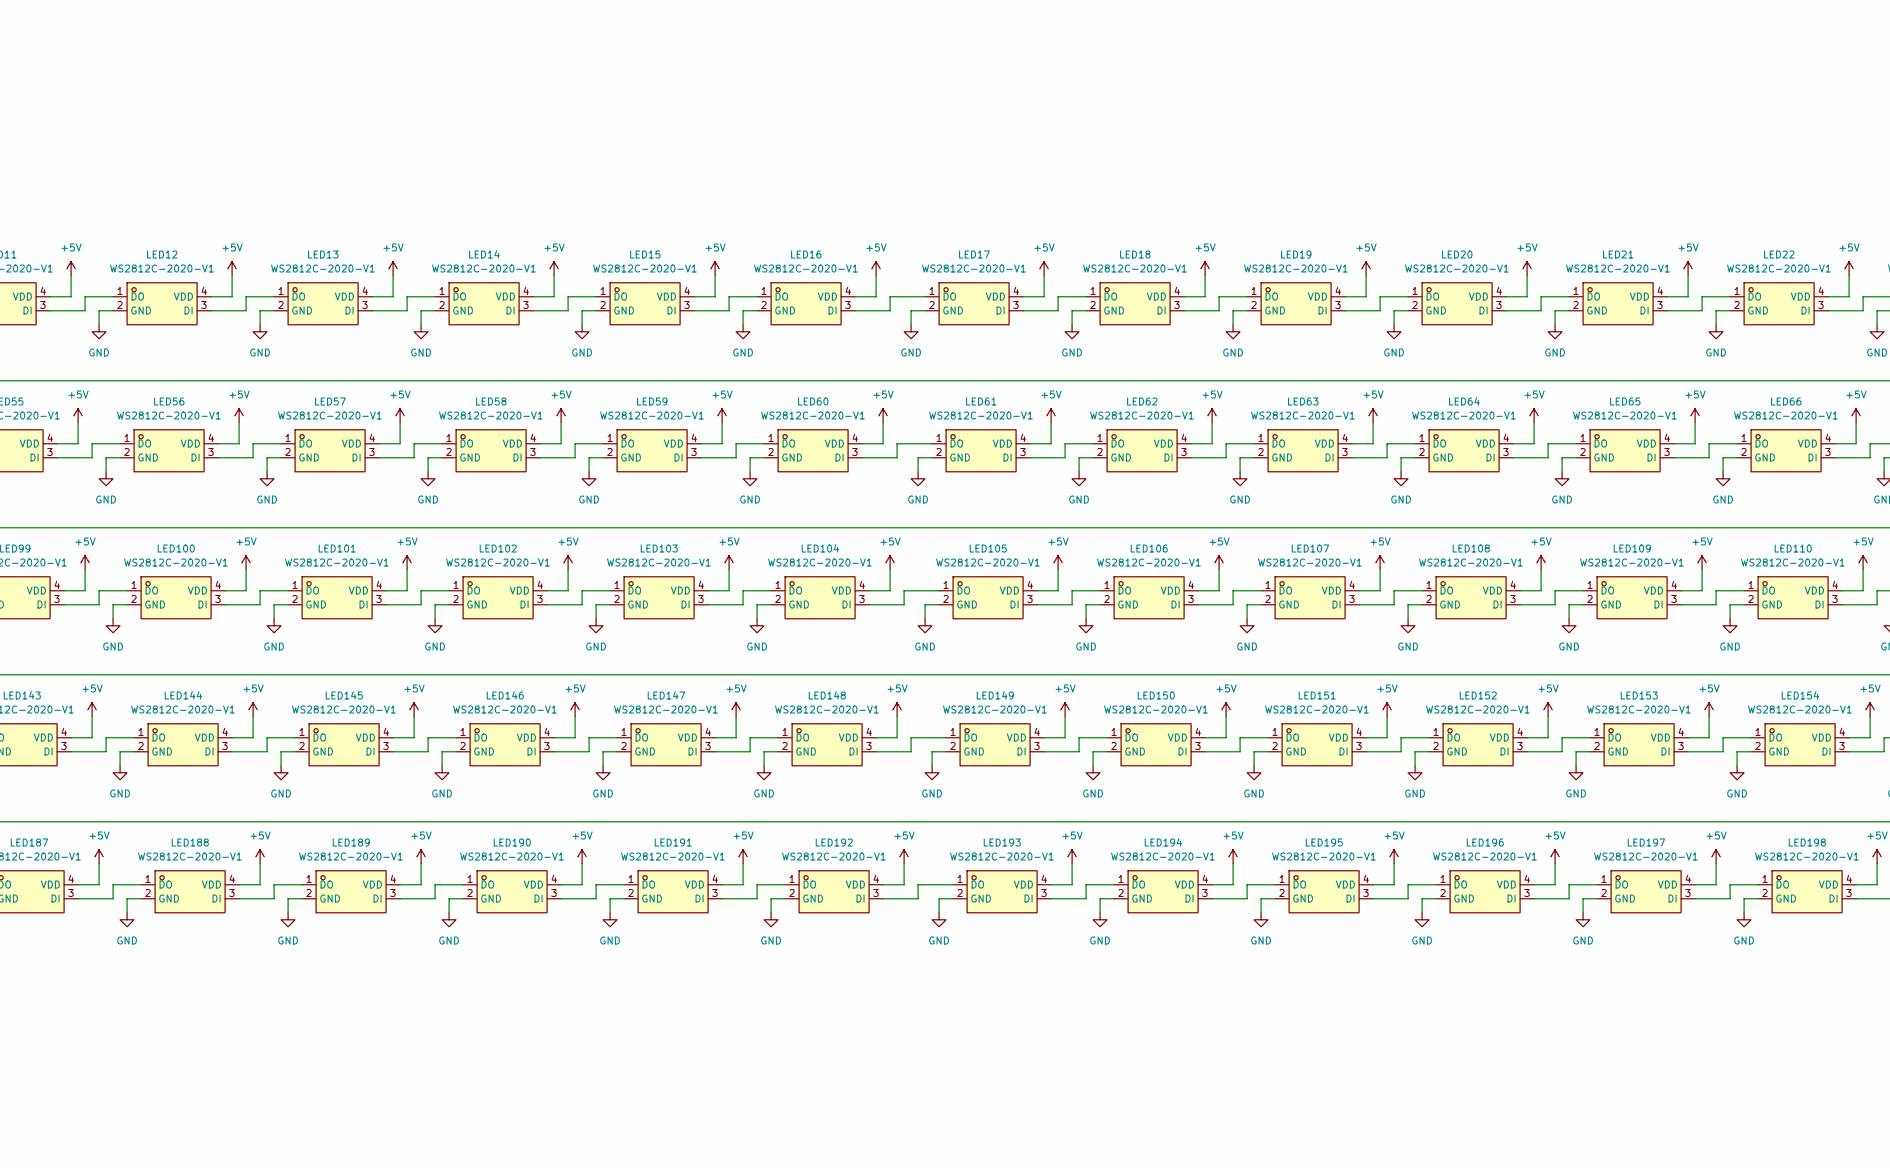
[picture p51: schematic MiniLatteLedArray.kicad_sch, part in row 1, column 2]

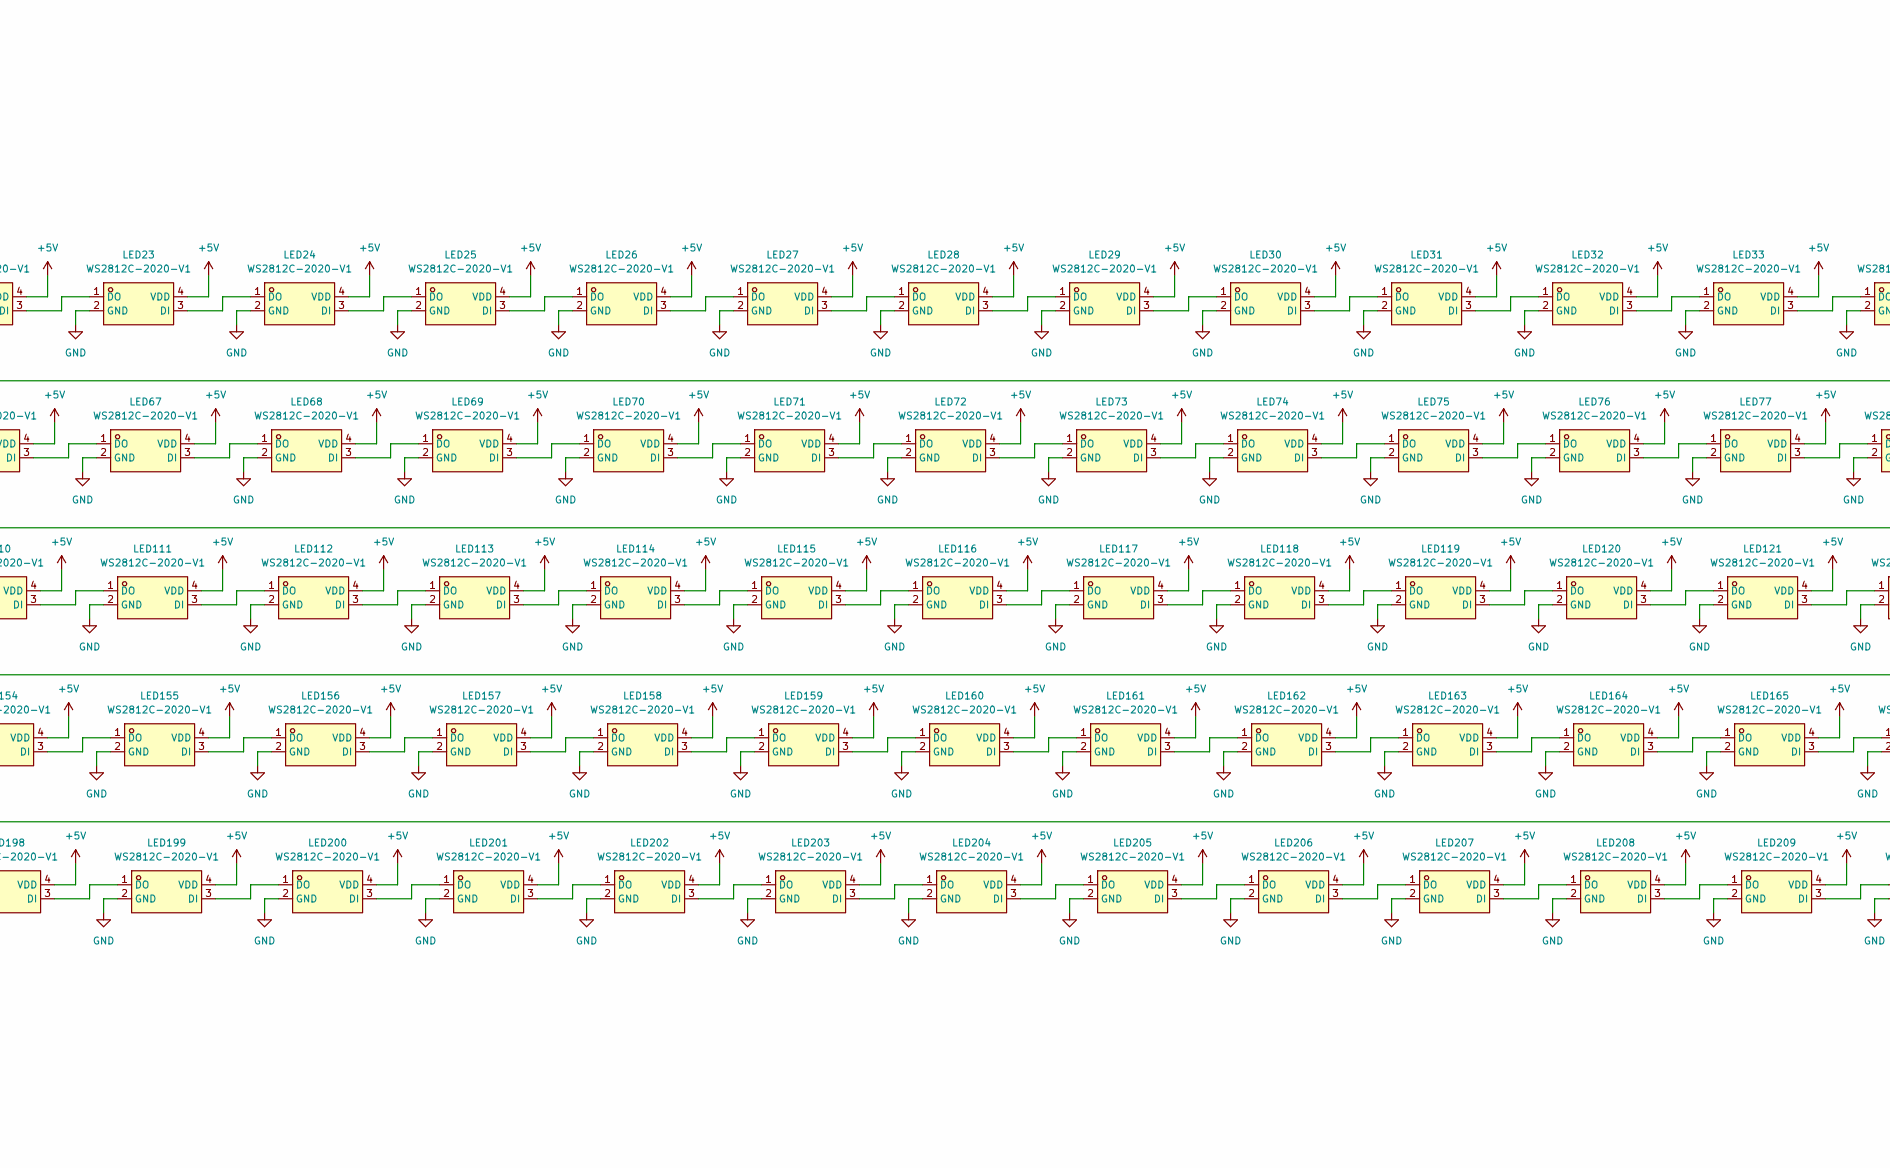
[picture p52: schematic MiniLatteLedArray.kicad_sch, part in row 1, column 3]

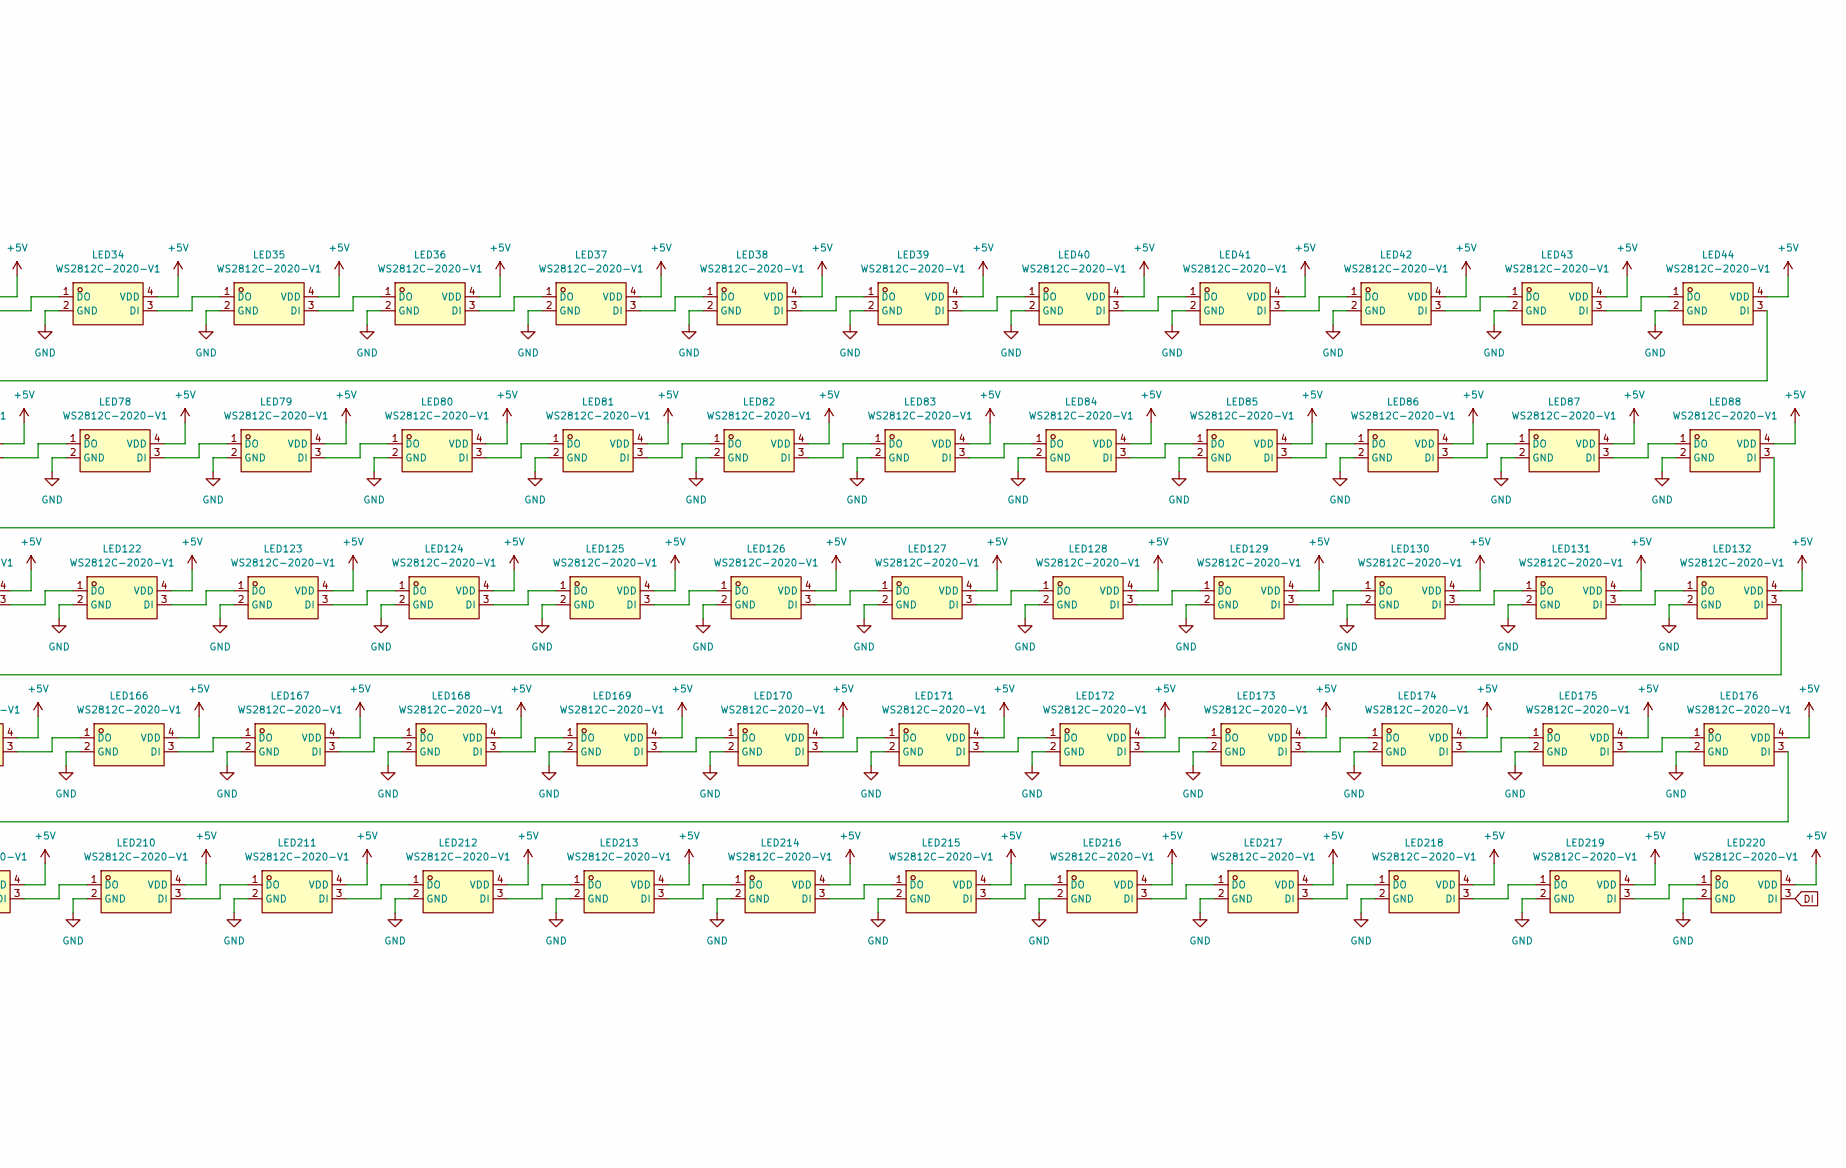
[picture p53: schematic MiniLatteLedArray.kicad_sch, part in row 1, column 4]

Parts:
H1, H2, H3, H4: MountingHole_Pad; MountingHole_2.2mm_M2_DIN965_Pad_TopOnly
LED1, LED2, LED3, LED4, LED5, LED6, LED7, LED8, LED9, LED10, LED11, LED12, LED13, LED14, LED15, LED16, LED17, LED18, LED19, LED20, LED21, LED22, LED23, LED24, LED25, LED26, LED27, LED28, LED29, LED30, LED31, LED32, LED33, LED34, LED35, LED36, LED37, LED38, LED39, LED40, LED41, LED42, LED43, LED44, LED45, LED46, LED47, LED48, LED49, LED50, LED51, LED52, LED53, LED54, LED55, LED56, LED57, LED58, LED59, LED60, LED61, LED62, LED63, LED64, LED65, LED66, LED67, LED68, LED69, LED70, LED71, LED72, LED73, LED74, LED75, LED76, LED77, LED78, LED79, LED80, LED81, LED82, LED83, LED84, LED85, LED86, LED87, LED88, LED89, LED90, LED91, LED92, LED93, LED94, LED95, LED96, LED97, LED98, LED99, LED100, LED101, LED102, LED103, LED104, LED105, LED106, LED107, LED108, LED109, LED110, LED111, LED112, LED113, LED114, LED115, LED116, LED117, LED118, LED119, LED120, LED121, LED122, LED123, LED124, LED125, LED126, LED127, LED128, LED129, LED130, LED131, LED132, LED133, LED134, LED135, LED136, LED137, LED138, LED139, LED140, LED141, LED142, LED143, LED144, LED145, LED146, LED147, LED148, LED149, LED150, LED151, LED152, LED153, LED154, LED155, LED156, LED157, LED158, LED159, LED160, LED161, LED162, LED163, LED164, LED165, LED166, LED167, LED168, LED169, LED170, LED171, LED172, LED173, LED174, LED175, LED176, LED177, LED178, LED179, LED180, LED181, LED182, LED183, LED184, LED185, LED186, LED187, LED188, LED189, LED190, LED191, LED192, LED193, LED194, LED195, LED196, LED197, LED198, LED199, LED200, LED201, LED202, LED203, LED204, LED205, LED206, LED207, LED208, LED209, LED210, LED211, LED212, LED213, LED214, LED215, LED216, LED217, LED218, LED219, LED220: WS2812C-2020-V1; LED-SMD_4P-L2.0-W2.0-TL_WS2812B-2020; LCSC Part C2976072
U1: ZX-XH2.54-4PLT; CONN-SMD_4P-P2.54_C9900012758; LCSC Part C7429682

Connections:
+5V: LED1.4 (VDD), LED2.4 (VDD), LED3.4 (VDD), LED4.4 (VDD), LED5.4 (VDD), LED6.4 (VDD), LED7.4 (VDD), LED8.4 (VDD), LED9.4 (VDD), LED10.4 (VDD), LED11.4 (VDD), LED12.4 (VDD), LED13.4 (VDD), LED14.4 (VDD), LED15.4 (VDD), LED16.4 (VDD), LED17.4 (VDD), LED18.4 (VDD), LED19.4 (VDD), LED20.4 (VDD), LED21.4 (VDD), LED22.4 (VDD), LED23.4 (VDD), LED24.4 (VDD), LED25.4 (VDD), LED26.4 (VDD), LED27.4 (VDD), LED28.4 (VDD), LED29.4 (VDD), LED30.4 (VDD), LED31.4 (VDD), LED32.4 (VDD), LED33.4 (VDD), LED34.4 (VDD), LED35.4 (VDD), LED36.4 (VDD), LED37.4 (VDD), LED38.4 (VDD), LED39.4 (VDD), LED40.4 (VDD), LED41.4 (VDD), LED42.4 (VDD), LED43.4 (VDD), LED44.4 (VDD), LED45.4 (VDD), LED46.4 (VDD), LED47.4 (VDD), LED48.4 (VDD), LED49.4 (VDD), LED50.4 (VDD), LED51.4 (VDD), LED52.4 (VDD), LED53.4 (VDD), LED54.4 (VDD), LED55.4 (VDD), LED56.4 (VDD), LED57.4 (VDD), LED58.4 (VDD), LED59.4 (VDD), LED60.4 (VDD), LED61.4 (VDD), LED62.4 (VDD), LED63.4 (VDD), LED64.4 (VDD), LED65.4 (VDD), LED66.4 (VDD), LED67.4 (VDD), LED68.4 (VDD), LED69.4 (VDD), LED70.4 (VDD), LED71.4 (VDD), LED72.4 (VDD), LED73.4 (VDD), LED74.4 (VDD), LED75.4 (VDD), LED76.4 (VDD), LED77.4 (VDD), LED78.4 (VDD), LED79.4 (VDD), LED80.4 (VDD), LED81.4 (VDD), LED82.4 (VDD), LED83.4 (VDD), LED84.4 (VDD), LED85.4 (VDD), LED86.4 (VDD), LED87.4 (VDD), LED88.4 (VDD), LED89.4 (VDD), LED90.4 (VDD), LED91.4 (VDD), LED92.4 (VDD), LED93.4 (VDD), LED94.4 (VDD), LED95.4 (VDD), LED96.4 (VDD), LED97.4 (VDD), LED98.4 (VDD), LED99.4 (VDD), LED100.4 (VDD), LED101.4 (VDD), LED102.4 (VDD), LED103.4 (VDD), LED104.4 (VDD), LED105.4 (VDD), LED106.4 (VDD), LED107.4 (VDD), LED108.4 (VDD), LED109.4 (VDD), LED110.4 (VDD), LED111.4 (VDD), LED112.4 (VDD), LED113.4 (VDD), LED114.4 (VDD), LED115.4 (VDD), LED116.4 (VDD), LED117.4 (VDD), LED118.4 (VDD), LED119.4 (VDD), LED120.4 (VDD), LED121.4 (VDD), LED122.4 (VDD), LED123.4 (VDD), LED124.4 (VDD), LED125.4 (VDD), LED126.4 (VDD), LED127.4 (VDD), LED128.4 (VDD), LED129.4 (VDD), LED130.4 (VDD), LED131.4 (VDD), LED132.4 (VDD), LED133.4 (VDD), LED134.4 (VDD), LED135.4 (VDD), LED136.4 (VDD), LED137.4 (VDD), LED138.4 (VDD), LED139.4 (VDD), LED140.4 (VDD), LED141.4 (VDD), LED142.4 (VDD), LED143.4 (VDD), LED144.4 (VDD), LED145.4 (VDD), LED146.4 (VDD), LED147.4 (VDD), LED148.4 (VDD), LED149.4 (VDD), LED150.4 (VDD), LED151.4 (VDD), LED152.4 (VDD), LED153.4 (VDD), LED154.4 (VDD), LED155.4 (VDD), LED156.4 (VDD), LED157.4 (VDD), LED158.4 (VDD), LED159.4 (VDD), LED160.4 (VDD), LED161.4 (VDD), LED162.4 (VDD), LED163.4 (VDD), LED164.4 (VDD), LED165.4 (VDD), LED166.4 (VDD), LED167.4 (VDD), LED168.4 (VDD), LED169.4 (VDD), LED170.4 (VDD), LED171.4 (VDD), LED172.4 (VDD), LED173.4 (VDD), LED174.4 (VDD), LED175.4 (VDD), LED176.4 (VDD), LED177.4 (VDD), LED178.4 (VDD), LED179.4 (VDD), LED180.4 (VDD), LED181.4 (VDD), LED182.4 (VDD), LED183.4 (VDD), LED184.4 (VDD), LED185.4 (VDD), LED186.4 (VDD), LED187.4 (VDD), LED188.4 (VDD), LED189.4 (VDD), LED190.4 (VDD), LED191.4 (VDD), LED192.4 (VDD), LED193.4 (VDD), LED194.4 (VDD), LED195.4 (VDD), LED196.4 (VDD), LED197.4 (VDD), LED198.4 (VDD), LED199.4 (VDD), LED200.4 (VDD), LED201.4 (VDD), LED202.4 (VDD), LED203.4 (VDD), LED204.4 (VDD), LED205.4 (VDD), LED206.4 (VDD), LED207.4 (VDD), LED208.4 (VDD), LED209.4 (VDD), LED210.4 (VDD), LED211.4 (VDD), LED212.4 (VDD), LED213.4 (VDD), LED214.4 (VDD), LED215.4 (VDD), LED216.4 (VDD), LED217.4 (VDD), LED218.4 (VDD), LED219.4 (VDD), LED220.4 (VDD), U1.1
DI: LED220.3 (DI), U1.2
GND: H1.1, H2.1, H3.1, H4.1, LED1.2 (GND), LED2.2 (GND), LED3.2 (GND), LED4.2 (GND), LED5.2 (GND), LED6.2 (GND), LED7.2 (GND), LED8.2 (GND), LED9.2 (GND), LED10.2 (GND), LED11.2 (GND), LED12.2 (GND), LED13.2 (GND), LED14.2 (GND), LED15.2 (GND), LED16.2 (GND), LED17.2 (GND), LED18.2 (GND), LED19.2 (GND), LED20.2 (GND), LED21.2 (GND), LED22.2 (GND), LED23.2 (GND), LED24.2 (GND), LED25.2 (GND), LED26.2 (GND), LED27.2 (GND), LED28.2 (GND), LED29.2 (GND), LED30.2 (GND), LED31.2 (GND), LED32.2 (GND), LED33.2 (GND), LED34.2 (GND), LED35.2 (GND), LED36.2 (GND), LED37.2 (GND), LED38.2 (GND), LED39.2 (GND), LED40.2 (GND), LED41.2 (GND), LED42.2 (GND), LED43.2 (GND), LED44.2 (GND), LED45.2 (GND), LED46.2 (GND), LED47.2 (GND), LED48.2 (GND), LED49.2 (GND), LED50.2 (GND), LED51.2 (GND), LED52.2 (GND), LED53.2 (GND), LED54.2 (GND), LED55.2 (GND), LED56.2 (GND), LED57.2 (GND), LED58.2 (GND), LED59.2 (GND), LED60.2 (GND), LED61.2 (GND), LED62.2 (GND), LED63.2 (GND), LED64.2 (GND), LED65.2 (GND), LED66.2 (GND), LED67.2 (GND), LED68.2 (GND), LED69.2 (GND), LED70.2 (GND), LED71.2 (GND), LED72.2 (GND), LED73.2 (GND), LED74.2 (GND), LED75.2 (GND), LED76.2 (GND), LED77.2 (GND), LED78.2 (GND), LED79.2 (GND), LED80.2 (GND), LED81.2 (GND), LED82.2 (GND), LED83.2 (GND), LED84.2 (GND), LED85.2 (GND), LED86.2 (GND), LED87.2 (GND), LED88.2 (GND), LED89.2 (GND), LED90.2 (GND), LED91.2 (GND), LED92.2 (GND), LED93.2 (GND), LED94.2 (GND), LED95.2 (GND), LED96.2 (GND), LED97.2 (GND), LED98.2 (GND), LED99.2 (GND), LED100.2 (GND), LED101.2 (GND), LED102.2 (GND), LED103.2 (GND), LED104.2 (GND), LED105.2 (GND), LED106.2 (GND), LED107.2 (GND), LED108.2 (GND), LED109.2 (GND), LED110.2 (GND), LED111.2 (GND), LED112.2 (GND), LED113.2 (GND), LED114.2 (GND), LED115.2 (GND), LED116.2 (GND), LED117.2 (GND), LED118.2 (GND), LED119.2 (GND), LED120.2 (GND), LED121.2 (GND), LED122.2 (GND), LED123.2 (GND), LED124.2 (GND), LED125.2 (GND), LED126.2 (GND), LED127.2 (GND), LED128.2 (GND), LED129.2 (GND), LED130.2 (GND), LED131.2 (GND), LED132.2 (GND), LED133.2 (GND), LED134.2 (GND), LED135.2 (GND), LED136.2 (GND), LED137.2 (GND), LED138.2 (GND), LED139.2 (GND), LED140.2 (GND), LED141.2 (GND), LED142.2 (GND), LED143.2 (GND), LED144.2 (GND), LED145.2 (GND), LED146.2 (GND), LED147.2 (GND), LED148.2 (GND), LED149.2 (GND), LED150.2 (GND), LED151.2 (GND), LED152.2 (GND), LED153.2 (GND), LED154.2 (GND), LED155.2 (GND), LED156.2 (GND), LED157.2 (GND), LED158.2 (GND), LED159.2 (GND), LED160.2 (GND), LED161.2 (GND), LED162.2 (GND), LED163.2 (GND), LED164.2 (GND), LED165.2 (GND), LED166.2 (GND), LED167.2 (GND), LED168.2 (GND), LED169.2 (GND), LED170.2 (GND), LED171.2 (GND), LED172.2 (GND), LED173.2 (GND), LED174.2 (GND), LED175.2 (GND), LED176.2 (GND), LED177.2 (GND), LED178.2 (GND), LED179.2 (GND), LED180.2 (GND), LED181.2 (GND), LED182.2 (GND), LED183.2 (GND), LED184.2 (GND), LED185.2 (GND), LED186.2 (GND), LED187.2 (GND), LED188.2 (GND), LED189.2 (GND), LED190.2 (GND), LED191.2 (GND), LED192.2 (GND), LED193.2 (GND), LED194.2 (GND), LED195.2 (GND), LED196.2 (GND), LED197.2 (GND), LED198.2 (GND), LED199.2 (GND), LED200.2 (GND), LED201.2 (GND), LED202.2 (GND), LED203.2 (GND), LED204.2 (GND), LED205.2 (GND), LED206.2 (GND), LED207.2 (GND), LED208.2 (GND), LED209.2 (GND), LED210.2 (GND), LED211.2 (GND), LED212.2 (GND), LED213.2 (GND), LED214.2 (GND), LED215.2 (GND), LED216.2 (GND), LED217.2 (GND), LED218.2 (GND), LED219.2 (GND), LED220.2 (GND), U1.4, U1.5, U1.6
unnamed: LED1.3 (DI), LED2.1 (DO)
unnamed: LED2.3 (DI), LED3.1 (DO)
unnamed: LED3.3 (DI), LED4.1 (DO)
unnamed: LED4.3 (DI), LED5.1 (DO)
unnamed: LED5.3 (DI), LED6.1 (DO)
unnamed: LED6.3 (DI), LED7.1 (DO)
unnamed: LED7.3 (DI), LED8.1 (DO)
unnamed: LED8.3 (DI), LED9.1 (DO)
unnamed: LED10.3 (DI), LED11.1 (DO)
unnamed: LED9.3 (DI), LED10.1 (DO)
unnamed: LED11.3 (DI), LED12.1 (DO)
unnamed: LED12.3 (DI), LED13.1 (DO)
unnamed: LED13.3 (DI), LED14.1 (DO)
unnamed: LED14.3 (DI), LED15.1 (DO)
unnamed: LED15.3 (DI), LED16.1 (DO)
unnamed: LED16.3 (DI), LED17.1 (DO)
unnamed: LED17.3 (DI), LED18.1 (DO)
unnamed: LED18.3 (DI), LED19.1 (DO)
unnamed: LED19.3 (DI), LED20.1 (DO)
unnamed: LED20.3 (DI), LED21.1 (DO)
unnamed: LED21.3 (DI), LED22.1 (DO)
unnamed: LED22.3 (DI), LED23.1 (DO)
unnamed: LED23.3 (DI), LED24.1 (DO)
unnamed: LED24.3 (DI), LED25.1 (DO)
unnamed: LED25.3 (DI), LED26.1 (DO)
unnamed: LED26.3 (DI), LED27.1 (DO)
unnamed: LED27.3 (DI), LED28.1 (DO)
unnamed: LED28.3 (DI), LED29.1 (DO)
unnamed: LED29.3 (DI), LED30.1 (DO)
unnamed: LED30.3 (DI), LED31.1 (DO)
unnamed: LED31.3 (DI), LED32.1 (DO)
unnamed: LED32.3 (DI), LED33.1 (DO)
unnamed: LED33.3 (DI), LED34.1 (DO)
unnamed: LED34.3 (DI), LED35.1 (DO)
unnamed: LED35.3 (DI), LED36.1 (DO)
unnamed: LED36.3 (DI), LED37.1 (DO)
unnamed: LED37.3 (DI), LED38.1 (DO)
unnamed: LED38.3 (DI), LED39.1 (DO)
unnamed: LED39.3 (DI), LED40.1 (DO)
unnamed: LED40.3 (DI), LED41.1 (DO)
unnamed: LED41.3 (DI), LED42.1 (DO)
unnamed: LED42.3 (DI), LED43.1 (DO)
unnamed: LED43.3 (DI), LED44.1 (DO)
unnamed: LED44.3 (DI), LED45.1 (DO)
unnamed: LED45.3 (DI), LED46.1 (DO)
unnamed: LED46.3 (DI), LED47.1 (DO)
unnamed: LED47.3 (DI), LED48.1 (DO)
unnamed: LED48.3 (DI), LED49.1 (DO)
unnamed: LED49.3 (DI), LED50.1 (DO)
unnamed: LED50.3 (DI), LED51.1 (DO)
unnamed: LED51.3 (DI), LED52.1 (DO)
unnamed: LED52.3 (DI), LED53.1 (DO)
unnamed: LED53.3 (DI), LED54.1 (DO)
unnamed: LED54.3 (DI), LED55.1 (DO)
unnamed: LED55.3 (DI), LED56.1 (DO)
unnamed: LED56.3 (DI), LED57.1 (DO)
unnamed: LED57.3 (DI), LED58.1 (DO)
unnamed: LED58.3 (DI), LED59.1 (DO)
unnamed: LED59.3 (DI), LED60.1 (DO)
unnamed: LED60.3 (DI), LED61.1 (DO)
unnamed: LED61.3 (DI), LED62.1 (DO)
unnamed: LED62.3 (DI), LED63.1 (DO)
unnamed: LED63.3 (DI), LED64.1 (DO)
unnamed: LED64.3 (DI), LED65.1 (DO)
unnamed: LED65.3 (DI), LED66.1 (DO)
unnamed: LED66.3 (DI), LED67.1 (DO)
unnamed: LED67.3 (DI), LED68.1 (DO)
unnamed: LED68.3 (DI), LED69.1 (DO)
unnamed: LED69.3 (DI), LED70.1 (DO)
unnamed: LED70.3 (DI), LED71.1 (DO)
unnamed: LED71.3 (DI), LED72.1 (DO)
unnamed: LED72.3 (DI), LED73.1 (DO)
unnamed: LED73.3 (DI), LED74.1 (DO)
unnamed: LED74.3 (DI), LED75.1 (DO)
unnamed: LED75.3 (DI), LED76.1 (DO)
unnamed: LED76.3 (DI), LED77.1 (DO)
unnamed: LED77.3 (DI), LED78.1 (DO)
unnamed: LED78.3 (DI), LED79.1 (DO)
unnamed: LED79.3 (DI), LED80.1 (DO)
unnamed: LED80.3 (DI), LED81.1 (DO)
unnamed: LED81.3 (DI), LED82.1 (DO)
unnamed: LED82.3 (DI), LED83.1 (DO)
unnamed: LED83.3 (DI), LED84.1 (DO)
unnamed: LED84.3 (DI), LED85.1 (DO)
unnamed: LED85.3 (DI), LED86.1 (DO)
unnamed: LED86.3 (DI), LED87.1 (DO)
unnamed: LED87.3 (DI), LED88.1 (DO)
unnamed: LED88.3 (DI), LED89.1 (DO)
unnamed: LED89.3 (DI), LED90.1 (DO)
unnamed: LED90.3 (DI), LED91.1 (DO)
unnamed: LED91.3 (DI), LED92.1 (DO)
unnamed: LED92.3 (DI), LED93.1 (DO)
unnamed: LED93.3 (DI), LED94.1 (DO)
unnamed: LED94.3 (DI), LED95.1 (DO)
unnamed: LED95.3 (DI), LED96.1 (DO)
unnamed: LED96.3 (DI), LED97.1 (DO)
unnamed: LED97.3 (DI), LED98.1 (DO)
unnamed: LED98.3 (DI), LED99.1 (DO)
unnamed: LED100.3 (DI), LED101.1 (DO)
unnamed: LED99.3 (DI), LED100.1 (DO)
unnamed: LED101.3 (DI), LED102.1 (DO)
unnamed: LED102.3 (DI), LED103.1 (DO)
unnamed: LED103.3 (DI), LED104.1 (DO)
unnamed: LED104.3 (DI), LED105.1 (DO)
unnamed: LED105.3 (DI), LED106.1 (DO)
unnamed: LED106.3 (DI), LED107.1 (DO)
unnamed: LED107.3 (DI), LED108.1 (DO)
unnamed: LED108.3 (DI), LED109.1 (DO)
unnamed: LED109.3 (DI), LED110.1 (DO)
unnamed: LED110.3 (DI), LED111.1 (DO)
unnamed: LED111.3 (DI), LED112.1 (DO)
unnamed: LED112.3 (DI), LED113.1 (DO)
unnamed: LED113.3 (DI), LED114.1 (DO)
unnamed: LED114.3 (DI), LED115.1 (DO)
unnamed: LED115.3 (DI), LED116.1 (DO)
unnamed: LED116.3 (DI), LED117.1 (DO)
unnamed: LED117.3 (DI), LED118.1 (DO)
unnamed: LED118.3 (DI), LED119.1 (DO)
unnamed: LED119.3 (DI), LED120.1 (DO)
unnamed: LED120.3 (DI), LED121.1 (DO)
unnamed: LED121.3 (DI), LED122.1 (DO)
unnamed: LED122.3 (DI), LED123.1 (DO)
unnamed: LED123.3 (DI), LED124.1 (DO)
unnamed: LED124.3 (DI), LED125.1 (DO)
unnamed: LED125.3 (DI), LED126.1 (DO)
unnamed: LED126.3 (DI), LED127.1 (DO)
unnamed: LED127.3 (DI), LED128.1 (DO)
unnamed: LED128.3 (DI), LED129.1 (DO)
unnamed: LED129.3 (DI), LED130.1 (DO)
unnamed: LED130.3 (DI), LED131.1 (DO)
unnamed: LED131.3 (DI), LED132.1 (DO)
unnamed: LED132.3 (DI), LED133.1 (DO)
unnamed: LED133.3 (DI), LED134.1 (DO)
unnamed: LED134.3 (DI), LED135.1 (DO)
unnamed: LED135.3 (DI), LED136.1 (DO)
unnamed: LED136.3 (DI), LED137.1 (DO)
unnamed: LED137.3 (DI), LED138.1 (DO)
unnamed: LED138.3 (DI), LED139.1 (DO)
unnamed: LED139.3 (DI), LED140.1 (DO)
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

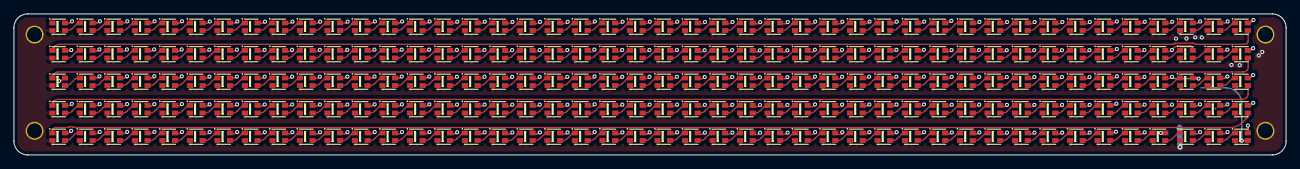
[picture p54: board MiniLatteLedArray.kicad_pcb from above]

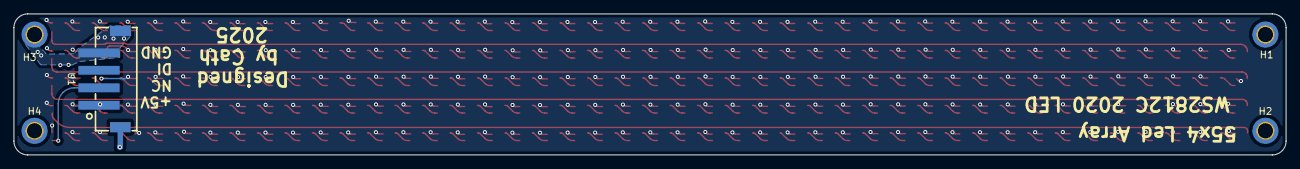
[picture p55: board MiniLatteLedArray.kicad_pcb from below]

Board: 2 copper layers, 185.0 x 20.5 mm, 225 parts (5 on the bottom side), 222 nets.

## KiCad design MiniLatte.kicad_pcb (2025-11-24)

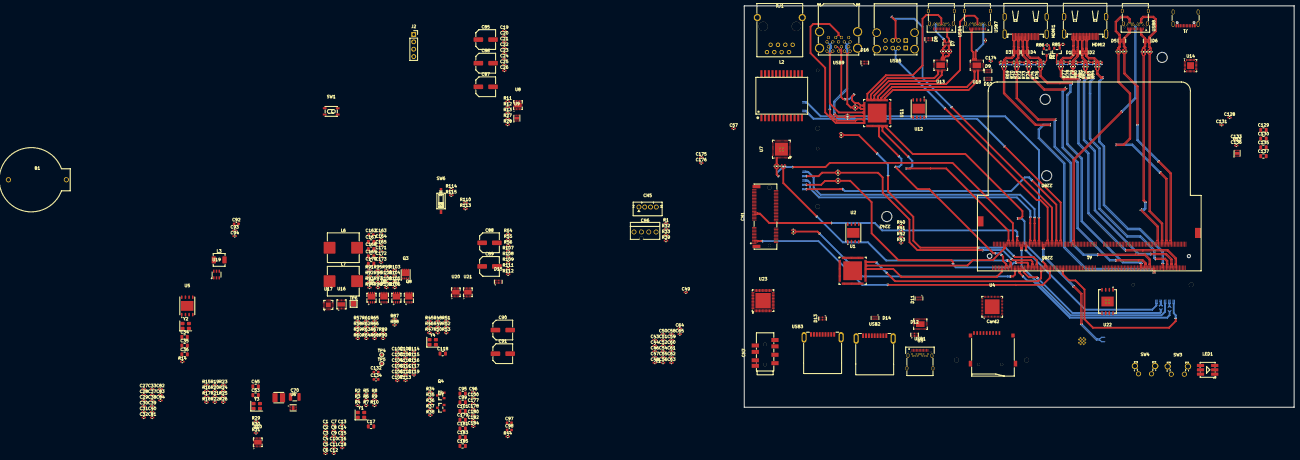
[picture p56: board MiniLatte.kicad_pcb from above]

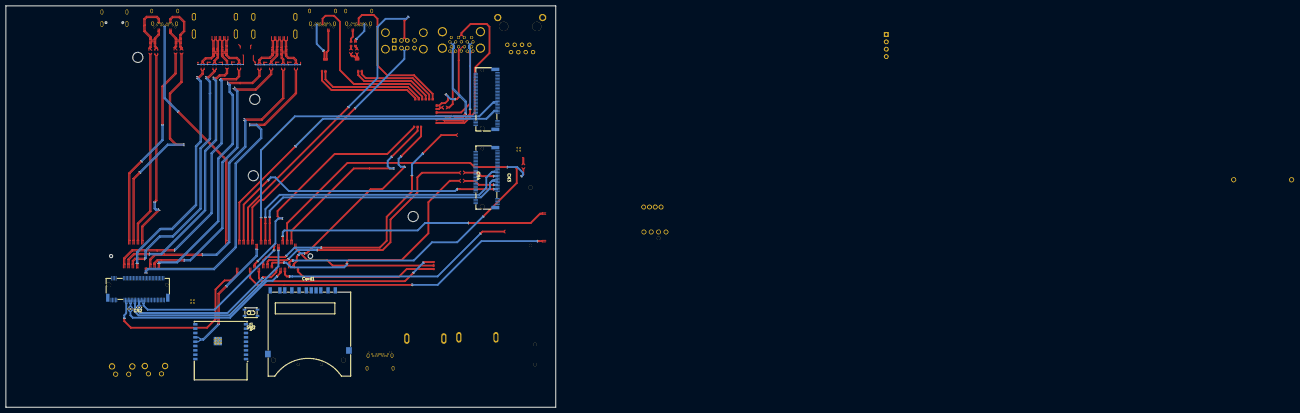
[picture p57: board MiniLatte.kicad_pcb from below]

Board: 4 copper layers, 189.8 x 138.6 mm, 391 parts (10 on the bottom side), 476 nets.

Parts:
A1: LattePanda_Mu; LattePanda_Module_H8.0mm_Horizontal
B1: BS-02-A1AJ010; BAT-TH_BS-02-A1AJ010
C1, C2, C3, C4, C5, C6, C7, C8, C9, C10, C12, C13, C14, C15, C18, C19, C20, C21, C22, C23, C24, C25, C26, C27, C28, C31, C32, C33, C37, C38, C39, C40, C46, C47, C48, C49, C50, C51, C54, C55, C56, C57, C58, C59, C60, C61, C62, C63, C64, C65, C66, C67, C68, C69, C81, C82, C83, C84, C94, C96, C100, C102, C103, C104, C105, C106, C107, C108, C109, C110, C111, C113, C114, C115, C116, C119, C120, C121, C122, C123, C124, C125, C126, C127, C128, C131, C133, C136, C138, C139, C140, C141, C142, C143, C144, C145, C146, C147, C148, C149, C150, C151, C152, C153, C163, C164, C166, C174, C175, C176, C177, C178, C180, C182, C184: 100nF; C_0402_1005Metric
C11, C16, C29, C30, C43, C44, C112, C117: 18pF; C_0402_1005Metric
C17, C35, C36, C45, C53, C95, C99, C101, C118, C129, C130, C135, C137, C167, C168, C169, C170, C179, C181, C183, C185: 10uF; C_0805_2012Metric
C34: 22uF; C_0805_2012Metric
C41, C42, C71, C72, C73, C74, C75, C76, C77, C78, C79, C80, C154, C155, C158, C159, C165, C171, C172, C173: 220nF; C_0402_1005Metric
C52: 22pF; C_0402_1005Metric
C70: 1nF 2kV; C_1210_3225Metric
C85, C86, C87, C88, C89, C90, C91: 220uF; C_Elec_6.3x7.7
C92, C97, C98, C132, C134, C162: 1uF; C_0603_1608Metric
C93: 47pF; C_0402_1005Metric
C156, C157, C160, C161: 330nF; C_0402_1005Metric
CN1: 2199230-4_C2977809; PCIE-SMD_2199230-4
CN2, CN3, CN4: APCI0107-P001A; CONN-SMD_APCI0107-P001A
CN5: WAFER-PH2.0-4PZZ; CONN-TH_4P-P2.00_FWF20001-S04S22W5B
CN6: 47053-1000; CONN-TH_47053-1000
CN7: PJ-393-8P_C49284725; AUDIO-TH_PJ-393-8P
Card1: SD-006M; SD-SMD_SD-006M
Card2: TF-01A; TF-SMD_TF-01A
D1, D2, D3, D4, D5, D6, D7, D8, D9, D10, D11, D12, D13, D14, D15, D16: RCLAMP0524P-N; DFN-10L_L2.5-W1.0-P0.50-BL
HDMI1, HDMI2: HDMI-019S; HDMI-SMD_HDMI-019S
J1: USB_C_Receptacle_USB2.0_16P; USB_C_Receptacle_GCT_USB4105-xx-A_16P_TopMnt_Horizontal
J2: Conn_01x04_Socket; PinSocket_1x04_P2.54mm_Vertical
L1: 2.2uH; IND-SMD_L3.5-W3.0
L2: HY602401; XFMR-SMD_HY602401
L3: 8.2uH; L_Changjiang_FXL0420
L6, L7: 3.3H; L_APV_APH1040
LED1: XL-5050SURC; LED-ARRAY-SMD_6P-L5.0-W5.0-TL-RD-2
Q1, Q2, Q4, Q9: 2N7002-SOT23; SOT-23_L2.9-W1.3-P1.90-LS2.4-BR
Q3: AON7403; PQFN-8_L3.1-W3.1-P0.65-LS3.3-BL
Q5, Q6, Q7, Q8: AON7402; PDFN-8_L3.1-W3.1-P0.65-LS3.4-BL
R1, R32: 27K; R_0402_1005Metric
R2, R3, R4, R5, R6, R7, R45, R46, R47, R48, R49, R50, R57, R58, R59, R105, R114: 10K; R_0402_1005Metric
R8, R51: 47k; R_0402_1005Metric
R9, R52: 100k; R_0402_1005Metric
R10, R53: 12.4K; R_0402_1005Metric
R11, R54, R107: 120k; R_0402_1005Metric
R12, R13, R15, R16, R19, R20, R37, R38, R55, R56, R108, R109, R110, R113: 10k; R_0402_1005Metric
R14: 680R; R_0402_1005Metric
R17: 160k; R_0402_1005Metric
R18: 270k; R_0402_1005Metric
R21, R42, R43, R115: 1K; R_0402_1005Metric
R22: 2.49k; R_0402_1005Metric
R23, R24, R25, R26: 75R; R_0402_1005Metric
R27, R28, R29, R111, R112: ?k; R_0402_1005Metric
R30, R31, R104: 0R; R_0402_1005Metric
R33, R39: 100R; R_0402_1005Metric
R34, R35, R36: R; R_0402_1005Metric
R40, R62, R63, R64, R68: 100K; R_0402_1005Metric
R41: 5.2K; R_0402_1005Metric
R44, R66: 20K; R_0402_1005Metric
R60: 82k; R_0402_1005Metric
R61, R65: 200k; R_0402_1005Metric
R67: 59K; R_0402_1005Metric
R69, R70, R71, R72, R73, R74, R75, R76, R77, R78, R79, R80, R81, R82, R83, R84: 470R; R_0402_1005Metric
R85, R86: 2.2K; R_0402_1005Metric
R87, R88, R89, R90: 220k; R_0402_1005Metric
R91: 10R; R_0402_1005Metric
R92: 50K; R_0402_1005Metric
R93: 5.1K; R_0402_1005Metric
R94: 14K; R_0402_1005Metric
R95: 22.6k; R_0402_1005Metric
R96: 8.2R; R_0402_1005Metric
R97: 6.8R; R_0402_1005Metric
R98: 30.9K; R_0402_1005Metric
R99: 33.2K; R_0402_1005Metric
R100, R102: 13k; R_0402_1005Metric
R101, R103: 20k; R_0402_1005Metric
R106: 3K; R_0402_1005Metric
RJ1: R-RJ45R10P-B000; RJ45-TH_R-RJ45R10P-B000
SW1, SW2: TS-1089S-02526; SW-SMD_4P-L4.2-W3.3-P2.15-LS5.1
SW3, SW4: TC-1102N-C-A-B; SW-TH_TC-1102N-C-A-B
SW6: DSHP01TSGER; SW-SMD_DSHP01TSGER
TP4: MUX3A/TXD1; TestPoint_Pad_D1.0mm
TP5: GP2_IT; TestPoint_Pad_D1.0mm
TP6: Vin TestPoint; TestPoint_Pad_2.0x2.0mm
U1, U11: VL822-QFN76; QFN-76_L9.0-W9.0-P0.40-EP6.3-TL
U2, U5, U12: W25Q32JVZPIQ; WSON-8_L6.0-W5.0-P1.27-BL-EP
U3, U13, U18: VL162; MQFN-28_L4.5-W3.5-P0.40-BL-EP
U4: GL3224-ONY04; QFN-48_L7.0-W7.0-P0.50-BL-EP5.1
U6: TPS62590DRVT; WSON-6_L2.0-W2.0-P0.65-TL-EP
U7: RTL8125BG-CG; TQFN-48_L6.0-W6.0-P0.40-BL-EP4.5
U8, U10, U20, U21: TPS2560DRCR; VSON-10_L3.0-W3.0-P0.50-BL-EP_TPS62410DRCR
U9, U15: TPS2553DRVR-1; WSON-6_L2.0-W2.0-P0.65-BL-EP
U14: IT8851; VQFN-28-1EP_4x4mm_P0.45mm_EP2.4x2.4mm
U16: HUSB238_002DD; DFN-10_L3.0-W3.0-P0.50-BL-EP2.5
U17: TPS51275RUKR; WQFN-20_L3.0-W3.0-P0.40-BL-EP1.7
U19: TPS54202DDCR; SOT-23-6_L2.9-W1.6-P0.95-LS2.8-BL
U22: W25N01GVZEIG_C907680; WSON-8_L8.0-W6.10-P1.27-BL-EP
U23: ALC269Q-VC3-GR; QFN-48_L7.0-W7.0-P0.50-BL-EP5.3
U24: ESP32-C3-WROOM-02
USB1, USB4, USB7, USB8: TYPEC-324-BCP24; USB-C-SMD_TYPEC-324-BCP24
USB2, USB3: U-A-39WD-W-1; USB-A-SMD_U-A-39WD-W-1
USB5: AF SS-JB17.6; USB-A-TH_AF-SS-JB17.6
USB9: USB-303WSD-BRY; USB-A-TH_XUNPU_USB-303WSD-BRY
Y1, Y2, Y3, Y4: 25Mhz; Crystal_SMD_3225-4Pin_3.2x2.5mm

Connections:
3.3LDO: R104.1, U17.3 (VREG3)
+0.95V: C45.1, C46.2, C47.2, C49.2, C50.2, C52.1, C58.2, C62.2, C63.2, L1.1, R17.1, U7.8 (DVDD09), U7.11 (AVDD09), U7.16 (AVDD09), U7.22 (AVDD09), U7.28 (DVDD09), U7.37 (EVDD09), U7.47 (DVDD09)
+1.05V: C1.2, C2.2, C3.2, C6.2, C7.2, C8.2, C10.2, C14.2, C15.2, C17.2, C18.1, C102.2, C103.2, C104.2, C107.2, C108.2, C109.2, C111.2, C115.2, C116.2, C118.2, C119.1, U1.5 (VCC10I), U1.8 (VCC10I), U1.11 (VDD), U1.14 (VCC10I), U1.27 (VCC10I), U1.30 (VDD), U1.33 (VCC10I), U1.36 (VCC10I), U1.48 (VDD), U1.51 (VCC10I), U1.54 (VCC10I), U1.67 (VDD), U11.5 (VCC10I), U11.8 (VCC10I), U11.11 (VDD), U11.14 (VCC10I), U11.27 (VCC10I), U11.30 (VDD), U11.33 (VCC10I), U11.36 (VCC10I), U11.48 (VDD), U11.51 (VCC10I), U11.54 (VCC10I), U11.67 (VDD)
+3.3V: C4.2, C5.2, C9.2, C12.2, C13.2, C48.2, C51.2, C53.1, C59.2, C60.2, C61.2, C64.2, C65.2, C95.1, C96.1, C99.1, C100.1, C105.2, C106.2, C110.2, C113.2, C114.2, C130.2, C131.2, C132.2, C165.2, C171.2, CN1.2, CN1.4, CN1.72, CN1.74, CN2.2, CN2.4, CN2.12, CN2.14, CN2.16, CN2.18, CN2.70, CN2.72, CN2.74, CN3.2, CN3.4, CN3.12, CN3.14, CN3.16, CN3.18, CN3.70, CN3.72, CN3.74, CN4.2, CN4.4, CN4.12, CN4.14, CN4.16, CN4.18, CN4.70, CN4.72, CN4.74, J2.1, L7.1, LED1.1 (A), Q4.3 (D), Q9.3 (D), R2.1, R3.1, R5.1, R6.1, R7.2, R8.2, R15.2, R16.2, R37.1, R38.1, R42.1, R45.1, R46.1, R48.1, R49.1, R50.2, R51.2, R100.1, R110.1, R113.1, R115.1, U1.17 (VCC33I), U1.24 (VCC33I), U1.46 (VCC33I), U1.62 (VCC33I), U1.73 (VCC33I), U2.3 (/WP(IO2)), U2.7 (/HOLDor/RESET(IO3)), U2.8 (VCC), U5.3 (/WP(IO2)), U5.7 (/HOLDor/RESET(IO3)), U5.8 (VCC), U6.5 (VIN), U7.15 (AVDD33), U7.19 (AVDD33), U7.29 (DVDD33), U7.33 (AVDD33), U7.34 (AVDD33_XTAL), U7.43 (EVDD33), U7.46 (DVDD33), U11.17 (VCC33I), U11.24 (VCC33I), U11.46 (VCC33I), U11.62 (VCC33I), U11.73 (VCC33I), U12.3 (/WP(IO2)), U12.7 (/HOLDor/RESET(IO3)), U12.8 (VCC), U14.25 (VIN), U19.5 (EN), U22.8 (VCC), U23.1 (DVDD), U23.9 (DVDD-IO), U24.1 (3V3)
+3.3VA: R20.1, R21.1
+5V: C34.1, C101.1, C128.1, C129.1, C172.1, C173.1, C177.1, C180.1, C181.1, C182.1, C183.1, C184.1, C185.1, CN5.2, L6.2, R61.2, R85.2, R86.2, R102.1, U3.25 (CE), U3.26 (VCC5V), U3.27 (Vconn_5Vin), U4.22 (VBUS), U8.2 (IN), U8.3 (IN), U9.6 (IN), U10.2 (IN), U10.3 (IN), U13.25 (CE), U13.26 (VCC5V), U13.27 (Vconn_5Vin), U14.13 (VCONN), U14.14 (VCONN), U15.6 (IN), U17.14 (VO1), U18.25 (CE), U18.26 (VCC5V), U18.27 (Vconn_5Vin), U20.2 (IN), U20.3 (IN), U21.2 (IN), U21.3 (IN), U23.25 (AVDD1), U23.38 (AVDD2), U23.39 (PVDD1), U23.46 (PVDD2)
+5V_DFP1: C91.1, USB7.A4 (VBUS), USB7.A9 (VBUS), USB7.B4 (VBUS), USB7.B9 (VBUS)
+5V_DFP2: C87.1, C90.1, USB1.A4 (VBUS), USB1.A9 (VBUS), USB1.B4 (VBUS), USB1.B9 (VBUS), USB4.A4 (VBUS), USB4.A9 (VBUS), USB4.B4 (VBUS), USB4.B9 (VBUS)
+5V_DFP3: C85.1, C89.1, USB3.1 (VBUS), USB9.10 (VBUS2)
+5V_DFP4: C86.1, C88.1, USB2.1 (VBUS), USB9.1 (VBUS1)
+5V_DP_ALT: C137.1, R65.2, U15.1 (OUT), USB8.A4 (VBUS), USB8.A9 (VBUS), USB8.B4 (VBUS), USB8.B9 (VBUS)
+5V_HDMI0: HDMI1.18 (+5V), HDMI2.18 (+5V)
+5V_USB2_0: U10.9 (OUT1), USB5.1 (VCC)
+5V_USB2_1: U10.8 (OUT2), USB5.5 (VCC)
+12V: C93.1, C94.2, CN6.2, L3.1, R40.1
/ALC269Q/HDA_BCLK: A1.174 (HDA_BCLK), U23.6 (BCLK)
/ALC269Q/HDA_RST: A1.172 (HDA_RST), U23.11 (~RESET)
/ALC269Q/HDA_SDIN: A1.180 (HDA_SDIN), U23.8 (SDATA-IN)
/ALC269Q/HDA_SDOUT: A1.178 (HDA_SDOUT), U23.5 (SDATA-OUT)
/ALC269Q/HDA_SYNC: A1.176 (HDA_SYNC), U23.10 (SYNC)
/DP_ALT_USB/DP_ALT_HPD: A1.185 (TCP1_HPD), R62.2, U14.23 (GP3/SDA2/CMP5/ADC_5)
/DP_ALT_USB/DP_ALT_RX1+: A1.226 (TCP1_TXRX0+), C156.2
/DP_ALT_USB/DP_ALT_RX1-: A1.228 (TCP1_TXRX0-), C157.2
/DP_ALT_USB/DP_ALT_RX2+: A1.238 (TCP1_TXRX1+), C161.1
/DP_ALT_USB/DP_ALT_RX2-: A1.240 (TCP1_TXRX1-), C160.1
/DP_ALT_USB/DP_ALT_TX1+: A1.220 (TCP1_TX0+), C158.1
/DP_ALT_USB/DP_ALT_TX1-: A1.222 (TCP1_TX0-), C159.1
/DP_ALT_USB/DP_ALT_TX2+: A1.232 (TCP1_TX1+), C154.2
/DP_ALT_USB/DP_ALT_TX2-: A1.234 (TCP1_TX1-), C155.2
/DP_ALT_USB/DP_RX1+: C156.1, D6.2, D6.9, R89.2, USB8.B11 (SSRXp1)
/DP_ALT_USB/DP_RX1-: C157.1, D6.1, D6.10, R90.2, USB8.B10 (SSRXn1)
/DP_ALT_USB/DP_RX2+: C161.2, D5.2, D5.9, R88.2, USB8.A11 (SSRXp2)
/DP_ALT_USB/DP_RX2-: C160.2, D5.1, D5.10, R87.2, USB8.A10 (SSRXn2)
/DP_ALT_USB/DP_TX1+: C158.2, D6.4, D6.7, USB8.A2 (SSTXP1)
/DP_ALT_USB/DP_TX1-: C159.2, D6.5, D6.6, USB8.A3 (SSTXn1)
/DP_ALT_USB/DP_TX2+: C154.1, D5.4, D5.7, USB8.B2 (SSTXp2)
/DP_ALT_USB/DP_TX2-: C155.1, D5.5, D5.6, USB8.B3 (SSTXn2)
/DP_ALT_USB/SBU1: A1.244 (TCP1_AUX+), R64.2, USB8.A8 (SBU1)
/DP_ALT_USB/SBU2: A1.246 (TCP1_AUX-), R63.2, USB8.B8 (SBU2)
/DP_ALT_USB/TCP1_SCL: A1.175 (TCP1_DDC_SCL), R63.1
/DP_ALT_USB/TCP1_SDA: A1.173 (TCP1_DDC_SDA), R64.1
/ESP32/ESP32_D+: A1.70 (USB2_P4+), U24.14 (IO19)
/ESP32/ESP32_D-: A1.72 (USB2_P4-), U24.13 (IO18)
/HDMI/HDMI_0_CLK+: A1.199 (DDIB_TX3+), C144.1
/HDMI/HDMI_0_CLK-: A1.197 (DDIB_TX3-), C145.1
/HDMI/HDMI_0_HPD: A1.183 (DDIB_HPD), HDMI1.19 (HOT_PLUG_DET)
/HDMI/HDMI_0_SCL: A1.171 (DDIB_DDC_SCL), HDMI1.15 (I2C-CLK)
/HDMI/HDMI_0_SDA: A1.169 (DDIB_DDC_SDA), HDMI1.16 (I2C_DATA)
/HDMI/HDMI_0_TX0+: A1.205 (DDIB_TX2+), C142.1
/HDMI/HDMI_0_TX0-: A1.203 (DDIB_TX2-), C143.1
/HDMI/HDMI_0_TX1+: A1.211 (DDIB_TX1+), C140.1
/HDMI/HDMI_0_TX1-: A1.209 (DDIB_TX1-), C141.1
/HDMI/HDMI_0_TX2+: A1.217 (DDIB_TX0+), C138.1
/HDMI/HDMI_0_TX2-: A1.215 (DDIB_TX0-), C139.1
/HDMI/HDMI_1_CLK+: A1.229 (TCP0_TXRX1+), C152.1
/HDMI/HDMI_1_CLK-: A1.227 (TCP0_TXRX1-), C153.1
/HDMI/HDMI_1_HPD: A1.187 (TCP0_HPD), HDMI2.19 (HOT_PLUG_DET)
/HDMI/HDMI_1_SCL: A1.179 (TCP0_DDC_SCL), HDMI2.15 (I2C-CLK)
/HDMI/HDMI_1_SDA: A1.177 (TCP0_DDC_SDA), HDMI2.16 (I2C_DATA)
/HDMI/HDMI_1_TX0+: A1.235 (TCP0_TX1+), C150.1
/HDMI/HDMI_1_TX0-: A1.233 (TCP0_TX1-), C151.1
/HDMI/HDMI_1_TX1+: A1.241 (TCP0_TXRX0+), C148.1
/HDMI/HDMI_1_TX1-: A1.239 (TCP0_TXRX0-), C149.1
/HDMI/HDMI_1_TX2+: A1.247 (TCP0_TX0+), C146.1
/HDMI/HDMI_1_TX2-: A1.245 (TCP0_TX0-), C147.1
/HDMI/H_0_CLK+: C144.2, D4.4, D4.7, HDMI1.10 (CK+), R75.1
/HDMI/H_0_CLK-: C145.2, D4.5, D4.6, HDMI1.12 (CK-), R76.1
/HDMI/H_0_TX0+: C142.2, D4.1, D4.10, HDMI1.7 (D0+), R73.1
/HDMI/H_0_TX0-: C143.2, D4.2, D4.9, HDMI1.9 (D0-), R74.1
/HDMI/H_0_TX1+: C140.2, D3.4, D3.7, HDMI1.4 (D1+), R71.1
/HDMI/H_0_TX1-: C141.2, D3.5, D3.6, HDMI1.6 (D1-), R72.1
/HDMI/H_0_TX2+: C138.2, D3.1, D3.10, HDMI1.1 (D2+), R69.1
/HDMI/H_0_TX2-: C139.2, D3.2, D3.9, HDMI1.3 (D2-), R70.1
/HDMI/H_1_CLK+: C152.2, D2.4, D2.7, HDMI2.10 (CK+), R83.1
/HDMI/H_1_CLK-: C153.2, D2.5, D2.6, HDMI2.12 (CK-), R84.1
/HDMI/H_1_TX0+: C150.2, D2.1, D2.10, HDMI2.7 (D0+), R81.1
/HDMI/H_1_TX0-: C151.2, D2.2, D2.9, HDMI2.9 (D0-), R82.1
/HDMI/H_1_TX1+: C148.2, D1.4, D1.7, HDMI2.4 (D1+), R79.1
/HDMI/H_1_TX1-: C149.2, D1.5, D1.6, HDMI2.6 (D1-), R80.1
/HDMI/H_1_TX2+: C146.2, D1.1, D1.10, HDMI2.1 (D2+), R77.1
/HDMI/H_1_TX2-: C147.2, D1.2, D1.9, HDMI2.3 (D2-), R78.1
/PCIE_SSD/PCIE2_L0TX+: C74.1, CN2.49
/PCIE_SSD/PCIE2_L0TX-: C73.1, CN2.47
/PCIE_SSD/PCIE2_L1TX+: C72.1, CN2.37
/PCIE_SSD/PCIE2_L1TX-: C71.1, CN2.35
/PCIE_SSD/PCIE3_L0TX+: C78.1, CN3.49
/PCIE_SSD/PCIE3_L0TX-: C77.1, CN3.47
/PCIE_SSD/PCIE3_L1TX+: C76.1, CN3.37
/PCIE_SSD/PCIE3_L1TX-: C75.1, CN3.35
/PCIE_SSD/PCIE4TX+: C80.1, CN4.49
/PCIE_SSD/PCIE4TX-: C79.1, CN4.47
/PCIE_SSD/PCIE_2_L0_RX+: A1.40 (HSIO8_RX+), CN2.43
/PCIE_SSD/PCIE_2_L0_RX-: A1.42 (HSIO8_RX-), CN2.41
/PCIE_SSD/PCIE_2_L0_TX+: A1.37 (HSIO8_TX+), C74.2
/PCIE_SSD/PCIE_2_L0_TX-: A1.39 (HSIO8_TX-), C73.2
/PCIE_SSD/PCIE_2_L1_RX+: A1.46 (HSIO9_RX+), CN2.31
/PCIE_SSD/PCIE_2_L1_RX-: A1.48 (HSIO9_RX-), CN2.29
/PCIE_SSD/PCIE_2_L1_TX+: A1.43 (HSIO9_TX+), C72.2
/PCIE_SSD/PCIE_2_L1_TX-: A1.45 (HSIO9_TX-), C71.2
/PCIE_SSD/PCIE_3_L0_RX+: A1.52 (HSIO10_RX+), CN3.43
/PCIE_SSD/PCIE_3_L0_RX-: A1.54 (HSIO10_RX-), CN3.41
/PCIE_SSD/PCIE_3_L0_TX+: A1.49 (HSIO10_TX+), C78.2
/PCIE_SSD/PCIE_3_L0_TX-: A1.51 (HSIO10_TX-), C77.2
/PCIE_SSD/PCIE_3_L1_RX+: A1.58 (HSIO11_RX+), CN3.31
/PCIE_SSD/PCIE_3_L1_RX-: A1.60 (HSIO11_RX-), CN3.29
/PCIE_SSD/PCIE_3_L1_TX+: A1.55 (HSIO11_TX+), C76.2
/PCIE_SSD/PCIE_3_L1_TX-: A1.57 (HSIO11_TX-), C75.2
/PCIE_SSD/PCIE_4_RX+: A1.64 (HSIO6_RX+), CN4.43
/PCIE_SSD/PCIE_4_RX-: A1.66 (HSIO6_RX-), CN4.41
/PCIE_SSD/PCIE_4_TX+: A1.61 (HSIO6_TX+), C80.2
/PCIE_SSD/PCIE_4_TX-: A1.63 (HSIO6_TX-), C79.2
/PCIE_WIFI_ETH/HSIN+: C67.2, U7.41 (HSIP)
/PCIE_WIFI_ETH/HSIN-: C66.2, U7.42 (HSIN)
/PCIE_WIFI_ETH/HSIO+: C69.2, U7.38 (HSOP)
/PCIE_WIFI_ETH/HSON-: C68.2, U7.39 (HSON)
/PCIE_WIFI_ETH/PCIE_0_RX+: A1.28 (HSIO2_RX+), C68.1
/PCIE_WIFI_ETH/PCIE_0_RX-: A1.30 (HSIO2_RX-), C69.1
/PCIE_WIFI_ETH/PCIE_0_TX+: A1.25 (HSIO2_TX+), C66.1
/PCIE_WIFI_ETH/PCIE_0_TX-: A1.27 (HSIO2_TX-), C67.1
/PCIE_WIFI_ETH/PCIE_1_RX+: A1.34 (HSIO3_RX+), CN1.41
/PCIE_WIFI_ETH/PCIE_1_RX-: A1.36 (HSIO3_RX-), CN1.43
/PCIE_WIFI_ETH/PCIE_1_TX+: A1.31 (HSIO3_TX+), C41.2
/PCIE_WIFI_ETH/PCIE_1_TX-: A1.33 (HSIO3_TX-), C42.2
/PWR_LED_SW/PWR_SW: A1.1 (~PWRBTN), R37.2, SW3.2
/PWR_LED_SW/RST_SW: A1.3 (~RSTBTN), R38.2, SW4.2
/PWR_LED_SW/S0_PWR_IND: A1.5 (SLS_S0), Q9.1 (G)
/PWR_LED_SW/S3_PWR_IND: A1.7 (SLS_S3), Q4.1 (G)
/USB_2_PORTS/USB2_0+: A1.76 (USB2_P7+), USB5.3 (D+)
/USB_2_PORTS/USB2_0-: A1.78 (USB2_P7-), USB5.2 (D-)
/USB_2_PORTS/USB2_1+: A1.82 (USB2_P8+), USB5.7 (D+)
/USB_2_PORTS/USB2_1-: A1.84 (USB2_P8-), USB5.6 (D-)
/USB_3/SS_HUB_0_RX+: A1.16 (HSIO0_RX+), U1.53 (SSRX0+)
/USB_3/SS_HUB_0_RX-: A1.18 (HSIO0_RX-), U1.52 (SSRX0–)
/USB_3/SS_HUB_0_TX+: A1.13 (HSIO0_TX+), U1.50 (SSTX0+)
/USB_3/SS_HUB_0_TX-: A1.15 (HSIO0_TX-), U1.49 (SSTX0–)
/USB_3/SS_HUB_1_RX+: A1.22 (HSIO1_RX+), U11.53 (SSRX0+)
/USB_3/SS_HUB_1_RX-: A1.24 (HSIO1_RX-), U11.52 (SSRX0–)
/USB_3/SS_HUB_1_TX+: A1.19 (HSIO1_TX+), U11.50 (SSTX0+)
/USB_3/SS_HUB_1_TX-: A1.21 (HSIO1_TX-), U11.49 (SSTX0–)
/USB_3/USB_HUB_0/GL3224/DFP1_D+: U1.9 (HSD1+), U4.5 (DP)
/USB_3/USB_HUB_0/GL3224/DFP1_D-: U1.10 (HSD1–), U4.4 (DM)
/USB_3/USB_HUB_0/GL3224/DFP1_DRX+: C82.1, U4.8 (TXP)
/USB_3/USB_HUB_0/GL3224/DFP1_DRX-: C81.2, U4.7 (TXN)
/USB_3/USB_HUB_0/GL3224/DFP1_DTX+: C84.1, U4.11 (RXP)
/USB_3/USB_HUB_0/GL3224/DFP1_DTX-: C83.2, U4.10 (RXN)
/USB_3/USB_HUB_0/GL3224/DFP1_RX+: C82.2, U1.6 (SSRX1+)
/USB_3/USB_HUB_0/GL3224/DFP1_RX-: C81.1, U1.7 (SSRX1–)
/USB_3/USB_HUB_0/GL3224/DFP1_TX+: C84.2, U1.3 (SSTX1+)
/USB_3/USB_HUB_0/GL3224/DFP1_TX-: C83.1, U1.4 (SSTX1–)
/USB_3/USB_HUB_0/HUB_0_PORTS/DFP2TX1+: C19.2, U3.2 (TX1_P)
/USB_3/USB_HUB_0/HUB_0_PORTS/DFP2TX1-: C20.1, U3.3 (TX1_N)
/USB_3/USB_HUB_0/HUB_0_PORTS/DFP2TX2+: C22.1, U3.5 (TX2_P)
/USB_3/USB_HUB_0/HUB_0_PORTS/DFP2TX2-: C21.2, U3.4 (TX2_N)
/USB_3/USB_HUB_0/HUB_0_PORTS/DFP2_D+: U1.18 (HSD2+), USB1.A6 (DP1), USB1.B6 (DP2)
/USB_3/USB_HUB_0/HUB_0_PORTS/DFP2_D-: U1.19 (HSD2–), USB1.A7 (DN1), USB1.B7 (DN2)
/USB_3/USB_HUB_0/HUB_0_PORTS/DFP2_RX+: U1.15 (SSRX2+), U3.18 (RX_P)
/USB_3/USB_HUB_0/HUB_0_PORTS/DFP2_RX-: U1.16 (SSRX2–), U3.17 (RX_N)
/USB_3/USB_HUB_0/HUB_0_PORTS/DFP2_TX+: U1.12 (SSTX2+), U3.21 (TXP)
/USB_3/USB_HUB_0/HUB_0_PORTS/DFP2_TX-: U1.13 (SSTX2–), U3.20 (TXN)
/USB_3/USB_HUB_0/HUB_0_PORTS/DFP3_D+: U1.22 (HSD3+), USB3.3 (D+)
/USB_3/USB_HUB_0/HUB_0_PORTS/DFP3_D-: U1.23 (HSD3–), USB3.2 (D-)
/USB_3/USB_HUB_0/HUB_0_PORTS/DFP3_RX+: D13.2, D13.9, U1.28 (SSRX3+), USB3.6 (STDA_SSRX+)
/USB_3/USB_HUB_0/HUB_0_PORTS/DFP3_RX-: D13.1, D13.10, U1.29 (SSRX3–), USB3.5 (STDA_SSRX-)
/USB_3/USB_HUB_0/HUB_0_PORTS/DFP3_TX+: C26.2, U1.25 (SSTX3+)
/USB_3/USB_HUB_0/HUB_0_PORTS/DFP3_TX-: C25.1, U1.26 (SSTX3–)
/USB_3/USB_HUB_0/HUB_0_PORTS/DFP4_D+: U1.37 (HSD4+), USB2.3 (D+)
/USB_3/USB_HUB_0/HUB_0_PORTS/DFP4_D-: U1.38 (HSD4–), USB2.2 (D-)
/USB_3/USB_HUB_0/HUB_0_PORTS/DFP4_RX+: D14.2, D14.9, U1.34 (SSRX4+), USB2.6 (STDA_SSRX+)
/USB_3/USB_HUB_0/HUB_0_PORTS/DFP4_RX-: D14.1, D14.10, U1.35 (SSRX4–), USB2.5 (STDA_SSRX-)
/USB_3/USB_HUB_0/HUB_0_PORTS/DFP4_TX+: C24.2, U1.31 (SSTX4+)
/USB_3/USB_HUB_0/HUB_0_PORTS/DFP4_TX-: C23.1, U1.32 (SSTX4–)
/USB_3/USB_HUB_0/HUB_0_PORTS/H0_DFP3TXC+: C26.1, D13.5, D13.6, USB3.9 (STDA_SSTX+)
/USB_3/USB_HUB_0/HUB_0_PORTS/H0_DFP3TXC-: C25.2, D13.4, D13.7, USB3.8 (STDA_SSTX-)
/USB_3/USB_HUB_0/HUB_0_PORTS/H0_DFP4TXC+: C24.1, D14.5, D14.6, USB2.9 (STDA_SSTX+)
/USB_3/USB_HUB_0/HUB_0_PORTS/H0_DFP4TXC-: C23.2, D14.4, D14.7, USB2.8 (STDA_SSTX-)
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

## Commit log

2026-03-12 redo folder structure
    [ALC269Q.kicad_sch, ALQ269.kicad_sch, Book1.xlsx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]
2026-03-13 Added LedArray and latex project
    [MiniLatteLedArray.kicad_pcb, MiniLatteLedArray.kicad_sch]
2026-07-03 Fixed m.2 wifi (from 2242 to 2230)
    [HDMI.kicad_sch, HUB_1_PORTS.kicad_sch, MiniLatte.kicad_sch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]
